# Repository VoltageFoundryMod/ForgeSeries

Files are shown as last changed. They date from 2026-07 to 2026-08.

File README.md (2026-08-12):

<div align="center">

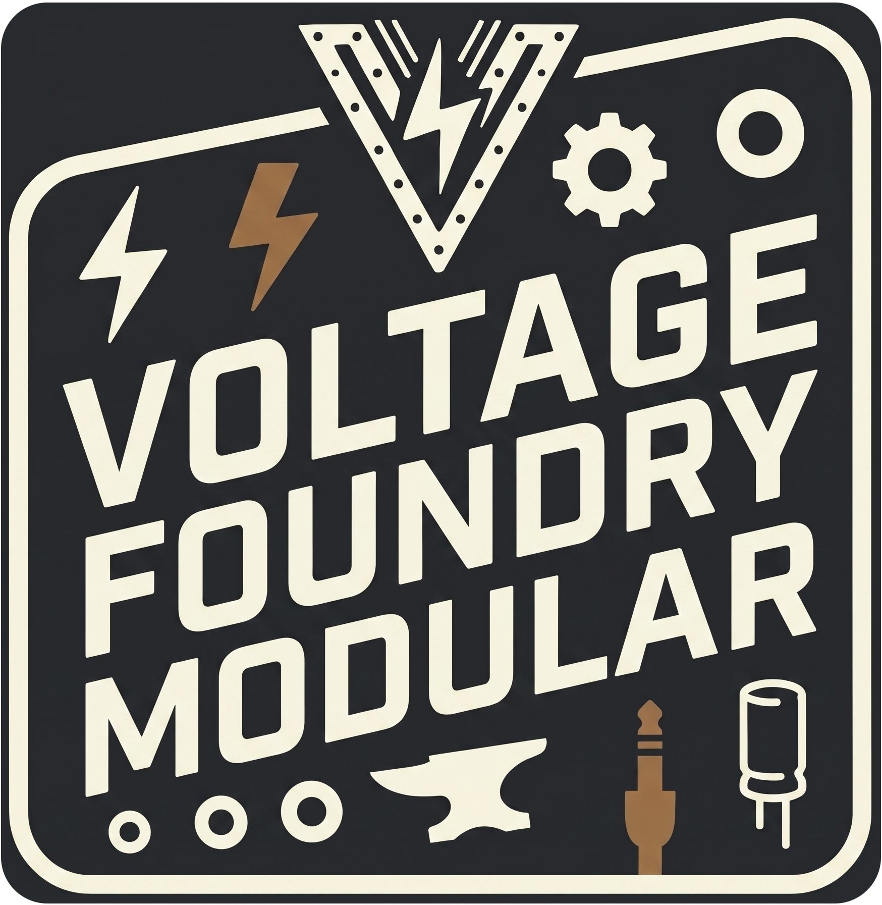
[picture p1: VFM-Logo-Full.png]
Voltage Foundry Modular


# ForgeSeries

**One open-source Eurorack platform. Many modules. You choose which one it is at
power-on — and the same firmware also runs inside VCV Rack.**

[The modules](#the-modules) ·
[Get one running](#get-one-running) ·
[The board](#the-board) ·
[Building from source](#building) ·
[How it fits together](#how-it-fits-together)

[Website & manuals](https://vfmod.com) ·
[Hardware repo](https://github.com/VoltageFoundryMod/ForgeSeries-Hardware) ·
[Firmware releases](https://github.com/VoltageFoundryMod/ForgeSeries/releases) ·
[Support on Patreon](https://patreon.com/carlosedp)

</div>

---

## What this is

ForgeSeries is a family of 6HP Eurorack modules from **Voltage Foundry Modular**
that all share a single board: a Seeed XIAO RP2040, a 128×64 OLED, one encoder,
3 CV inputs and 4 outputs. What makes the board a clock generator or a quantizer
is nothing but firmware.

This repository holds all of it:

- **The firmware** — one image (`src/`) that contains _every_ module. Hold
  the encoder at power-on to pick which one boots; the choice persists.
- **The VCV Rack plugin** — not a reimplementation. The actual firmware runs
  inside Rack against a hardware shim, with the OLED emulated pixel for pixel,
  so a patch behaves the same on the metal and on the screen.
- **The shared core** — board bring-up, CV calibration, storage, display and
  menu plumbing that every module builds on.

Schematics, PCB and panel files are open too, in the separate
[ForgeSeries-Hardware](https://github.com/VoltageFoundryMod/ForgeSeries-Hardware)
repository.

## The modules

| | Module | What it does | Docs |
| --- | --- | --- | --- |
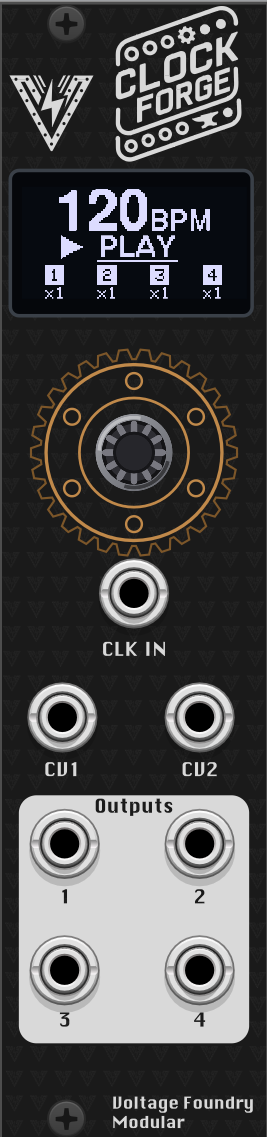
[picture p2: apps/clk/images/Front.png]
ClockForge front panel
|  | **ClockForge**<br><sub>`apps/clk`</sub> | Clock generator and modulation source. Four outputs with individual multiply/divide, waveforms, envelopes, Euclidean rhythms, swing, phase, probability, cross-operations and loops. Tap tempo and external sync. | [Overview](apps/clk/Readme.md) · [Manual](apps/clk/Manual.md) · [VCV port](apps/clk/docs/VCVRack_Plugin.md) · [ModularGrid](https://modulargrid.net/e/voltage-foundry-modular-clockforge) |
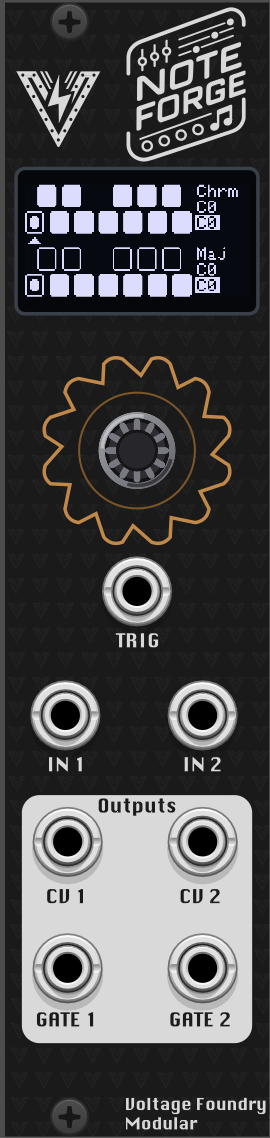
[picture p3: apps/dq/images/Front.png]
NoteForge front panel
|  | **NoteForge**<br><sub>`apps/dq`</sub> | Dual quantizer. Two independent channels, each with its own editable 12-note scale mask, octave shift, glide, sample & hold and a gate/envelope output. | [Overview](apps/dq/Readme.md) · [Manual](apps/dq/Manual.md) · [VCV port](apps/dq/docs/VCVRack_Plugin.md) · [ModularGrid](https://modulargrid.net/e/voltage-foundry-modular-noteforge) |
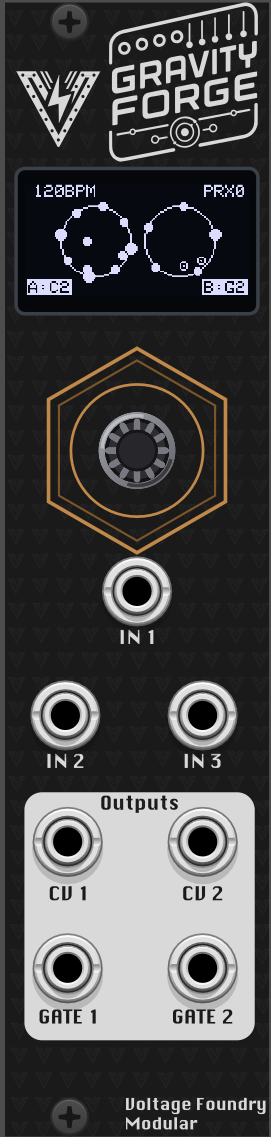
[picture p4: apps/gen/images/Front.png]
GravityForge front panel
|  | **GravityForge**<br><sub>`apps/gen`</sub> | Physics-based generative sequencer. Balls fall inside two rotating containers and ring scale-tuned pegs; a proximity control slides the two from independent sequencers into one entangled instrument. | [Overview](apps/gen/Readme.md) · [Manual](apps/gen/Manual.md) · [Design notes](apps/gen/docs/Design.md) · [ModularGrid](https://modulargrid.net/e/voltage-foundry-modular-gravityforge) |
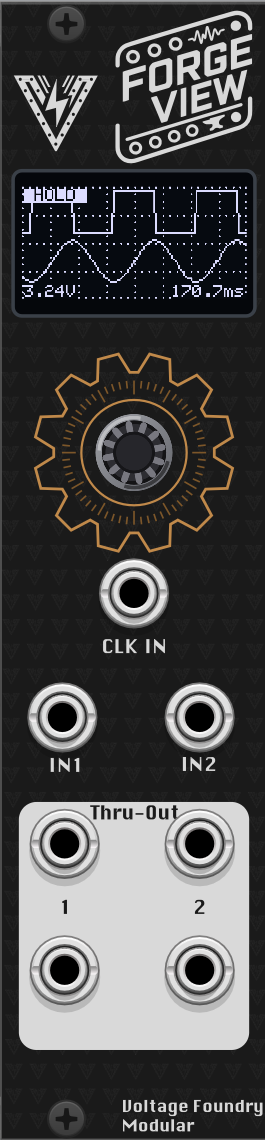
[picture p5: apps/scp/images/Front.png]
ForgeView front panel
|  | **ForgeView**<br><sub>`apps/scp`</sub> | Oscilloscope and analysis. Dual-trace and single-trace scope, triggered capture, spectrum analyzer, X-Y display and a tuner — with buffered pass-through so it can sit mid-patch. | [Overview](apps/scp/Readme.md) · [Manual](apps/scp/Manual.md) · [VCV port](apps/scp/docs/VCVRack_Plugin.md) · [ModularGrid](https://modulargrid.net/e/voltage-foundry-modular-forgeview)  |
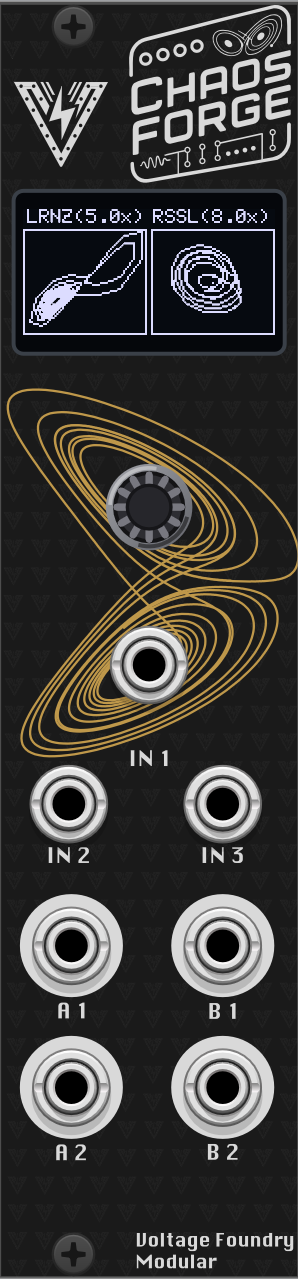
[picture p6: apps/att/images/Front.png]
ChaosForge front panel
|  | **ChaosForge**<br><sub>`apps/att`</sub> | Dual chaotic-attractor modulation source. Twelve strange attractors; each generator sends two of its three state variables to a pair of jacks, and a couple control takes the two from unrelated to locked. | [Overview](apps/att/Readme.md) · [Manual](apps/att/Manual.md) · [Design notes](apps/att/docs/Design.md) · [ModularGrid](https://modulargrid.net/e/voltage-foundry-modular-chaosforge) |
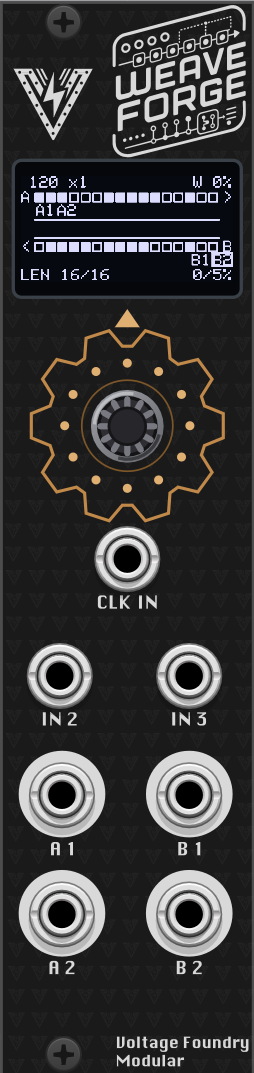
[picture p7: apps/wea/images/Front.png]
WeaveForge front panel
|  | **WeaveForge**<br><sub>`apps/wea`</sub> | Dual shift-register sequencer. Two Turing Machines side by side, and one WEAVE control that slides them from independent to chained into a single ring; four jacks assignable to notes, modulation, gates or triggers. | [Overview](apps/wea/Readme.md) · [Manual](apps/wea/Manual.md) · [Design notes](apps/wea/docs/Design.md) |

Each **Manual** is the complete user guide — every menu page, screenshot,
calibration and wiring detail. Browsable versions with images live on
[vfmod.com](https://vfmod.com).

## Get one running

### On hardware

1. Download `ForgeSeries-<version>-unified.zip` from the [latest release](https://github.com/VoltageFoundryMod/ForgeSeries/releases) or a [dev build](https://github.com/VoltageFoundryMod/ForgeSeries/actions) from CI run's artifacts (enter one of the workflow runs and the artifacts are at the bottom) and unpack the `.uf2` inside it.
2. Hold the small **BOOT (B)** button on the XIAO while connecting USB-C. A
   drive named `RPI-RP2` appears. (The XIAO is socketed, so this can be done
   with it removed from the module.)
3. Copy the `.uf2` onto that drive. The module reboots into the new firmware.
4. **Hold the encoder at power-on** to choose a module. It boots straight into
   that one afterwards; to get back to the selector, either hold the encoder for
   two seconds while running or pick **BOOT MENU** on the module's SETTINGS page.
5. Run the two-point **calibration wizard** once: pick **CALIBRATE**,
   the last row of the boot menu. Calibration works for the board, so one
   run serves every module and it survives firmware updates.

#### Single-module images

`ForgeSeries-<version>-individual-modules.zip` on the same release holds one image per
module — `ClockForge`, `NoteForge`, `GravityForge`, `ForgeView`, `ChaosForge`,
`WeaveForge` —
for a build of
the hardware that is only ever going to be one of them. Flashing works exactly
as above, and everything else in this section still applies: the module boots
straight in, and holding the encoder at power-on (or **BOOT MENU** on its
SETTINGS page) opens the same screen with that one module and **CALIBRATE** on
it, which is how you reach the wizard.

They are the same shell and the same module sources as the unified image, just
linked with one module instead of all of them, so a given release behaves identically
either way. Presets and calibration live in the same files, so you can move
between the two images without losing either.

> **Never connect Eurorack power and USB-C at the same time.** The module takes
> either, not both.

### In VCV Rack

The plugin bundles every module under the **Voltage Foundry Modular** brand.
Until it lands in the VCV library, build it from source — see
[Building](#building) — or take the packaged `.vcvplugin` from the [latest release](https://github.com/VoltageFoundryMod/ForgeSeries/releases) or a [dev build](https://github.com/VoltageFoundryMod/ForgeSeries/actions) from CI run's artifacts (enter one of the workflow runs and the artifacts are at the bottom).

```sh
make vcv && make vcv-install   # build the bundle and install it into Rack
```

And drop the `.vcvrack` file into plugins in the VCVRack user folder. MacOS is `~/Library/Application Support/Rack2/`, Windows is `C:\Users\<username>\AppData\Local\Rack2\`, and Linux is `~/.local/share/Rack2/`.

The Rack build can accept 0–5 V (like the hardware), ±5 V or 0–10 V inputs, so
it is more forgiving than the board while behaving identically inside that
range.

## The board

Every ForgeSeries module is the same hardware:

| | |
| --- | --- |
| MCU | Seeed XIAO RP2040 (dual core, 2 MB flash) |
| Display  | 128×64 SSD1306 OLED |
| Controls | one rotary encoder with push |
| I/O | 3 CV inputs, 4 outputs (12-bit MCP4728 DAC) |
| CV range | 0–5 V in and out (a ±5 V revision builds with `-DFORGE_CV_BIPOLAR`) |
| Size | 6 HP, 40 mm deep |
| Power | 12 V or 5 V, jumper selectable · ~60 mA |

Because the hardware is identical across modules, one board plus one firmware
flash gets you any of them — and a new module is a new firmware, not a new PCB.

## Repository layout

```text
platformio.ini  the firmware project — the repo root IS the PlatformIO project
src/            the shell. The only firmware built for the board
core/      the board, and everything every module shares
apps/
  clk/     ClockForge    — clock generator / modulation source
  dq/      NoteForge     — dual quantizer
  gen/     GravityForge  — physics-based generative sequencer
  scp/     ForgeView     — oscilloscope / spectrum analyser
  att/     ChaosForge    — dual chaotic-attractor modulation source
  wea/     WeaveForge    — dual shift-register sequencer
vcv/       the consolidated VCV Rack plugin (all modules, one binary)
vcvlib/    shared VCV Rack layer (Arduino shim, ForgeModule, IEngine, widgets)
tools/     env.ps1 — optional PATH helper for Windows
```

A module runs on two hosts — the shell (hardware firmware) and VCV Rack — and
its code lives in one place per host:

```text
apps/gen/
  src/gen_app.cpp   the module as the shell sees it (forge::IApp)
  src/gen_app.hpp   its factory — the only thing the shell includes
  lib/              the module's own headers, including engine.hpp
  vcv-plugin/       the same module as a standalone Rack plugin
  test/             native unit tests (googletest + ArduinoFake)
  platformio.ini    those tests only — there is no per-module firmware
```

`lib/engine.hpp` is the piece that keeps the two honest: the module's
per-iteration engine step lives there and both hosts include it, rather than
each carrying a copy. That duplication is how GravityForge's Rack port silently
lost its LOOP▸NAP muting.

## Building

Prerequisites: [PlatformIO](https://platformio.org/) for the firmware, and the
[VCV Rack SDK](https://vcvrack.com/manual/Building) for the plugins (expected at
`../Rack-SDK`, override with `RACK_DIR=`).

```sh
make                # the firmware (unified image, every module)
make upload         # build + flash
make upload-monitor # ...and open the serial monitor
make modules        # the single-module images, one per module
make fw-clk         # one of them  (== pio run -e xiao_clk)
make fw-upload-clk  # ...and flash it
make test           # native unit tests for every module
make vcv            # the consolidated Rack plugin
make vcv-install    # ...and install it into Rack's user directory
make vcv-dist       # package it as a .vcvplugin
make plugins        # every standalone per-module Rack plugin
make clk            # one module's standalone plugin, installed into Rack
make everything     # every firmware image + all standalone plugins
```

**Run `make everything` before committing.** It is the only thing that builds
both hosts. PlatformIO does not compile `vcv-plugin/`, so a green firmware build
says nothing about the Rack ports — and every bug found while this structure was
being built was caught by building all targets and missed by building one.

> **Do not leave both plugin flavours installed in Rack.** The standalone
> plugins have their own slugs (`ClockForge`, `NoteForge`, …) and the
> consolidated one is `VoltageFoundryMod`, so Rack happily loads all of them and
> every module shows up twice in the browser. Delete the standalone ones from
> Rack's plugin directory before installing the consolidated build
> (`make -C vcv print-plugins-dir` prints where that is).

Standalone plugins can also be built directly. Both paths are `?=` defaults:

```sh
cd apps/gen/vcv-plugin && make          # RACK_DIR ?= ../../../../Rack-SDK
make RACK_DIR=/path/to/Rack-SDK         # out-of-tree SDK
```

`FORGEVCV` defaults to `../../../vcvlib` (in-repo). It no longer needs a sibling
`ForgeSeries-VCVLib` checkout.

[CI](.github/workflows/CI.yaml) drives these same entry points, so what it
checks and what you run locally cannot drift apart: unit tests and the unified
image, the VCV engine isolation tests, and both plugin flavours.

### Windows toolchain

Everything builds from PowerShell — an msys2 _shell_ is not required. Rack's
`plugin.mk` shells out to POSIX tools, but GNU make picks up msys2's `sh.exe` as
SHELL once it is on PATH, so PowerShell only has to be the parent shell.

```powershell
. .\tools\env.ps1   # puts the three toolchain dirs on PATH, reports what it found
make everything
```

The plugin compiler must be **mingw64 g++** — the Rack SDK for Windows is
mingw-w64 built and MSVC will not link against it. `jq` is needed too, since
`plugin.mk` uses it to read `SLUG` out of `plugin.json`:

```
pacman -S --needed make mingw-w64-x86_64-gcc mingw-w64-x86_64-jq
```

The Makefile checks for all three before building plugins and says exactly what
is missing, rather than letting it surface as plugin.mk's "SLUG could not be
found in manifest". The check runs only for the plugin goals — the firmware
needs PlatformIO alone and builds without msys2 installed.

Point `MSYS` elsewhere if needed: `make MSYS=D:/msys64 plugins`.

---

# How it fits together

The rest of this document is for people working on the code. Start here if you
are adding a module, touching `core/`, or wondering why the include order in a
module TU looks the way it does.

## What belongs in `core/`

Every ForgeSeries module is the _same board_: XIAO RP2040, SSD1306 on Wire,
MCP4728 on Wire1, one encoder, 3 in / 4 out. Anything that follows from that is
shared:

| | |
| --- | --- |
| `boardPinouts.hpp` | wiring, converter resolution (`MAXDAC`/`MAXADC`) |
| `boardIO.hpp` | I2C bring-up, DAC writes + output calibration |
| `cvInput.hpp` | CV acquisition, calibration, range adapters |
| `calibrationData.hpp` `calibration.hpp` | the blob, and the wizard that fills it |
| `fsStore.hpp` `appStorage.hpp` | LittleFS storage; presets and calibration |
| `shellObjects.hpp` | the board-owned `display` / `displayMgr` / `encoder` / `cal` |
| `displayManager.hpp` `menuDisplay.hpp` `appDisplay.hpp` `splash.hpp`  | UI plumbing |
| `encoder.hpp` `encoderAccel.hpp` `encoderMenu.hpp` | encoder, acceleration, menu driver |
| `envelope.hpp` `scales.hpp` `quantizer.hpp` `utils.hpp` `metrics.hpp` | shared DSP/theory |
| `clockSource.hpp` | internal BPM, external clock at IN 1, the changeover |
| `IApp.hpp` | the shell↔app contract |

What stays in a module's `lib/` is genuinely its own: menu definitions, preset
schema, `engine.hpp`, and the DSP that makes it that module.

ClockForge's quantizer is deliberately not shared: it is a separate
implementation reached through `Output` rather than a channel, so folding it in
would be a port rather than a merge.

**Neither is ClockForge's clock**, for the same reason and with more at stake.
`core/clockSource.hpp` is a passed-in-time value object — nothing in it calls
`micros()`, which is what makes it host-testable and the Rack ports
deterministic. `apps/clk/lib/clockEngine.hpp` is a 960-PPQN hardware-timer ISR
with file-scope `BPM` and `tickCounter` globals driving that whole module from
the interrupt. They share a word, not an architecture. `clockSource.hpp` was
lifted out of GravityForge when WeaveForge needed the same internal/external
changeover, and GravityForge holds one as a member rather than having been
rewritten around it — its `Clock` still owns the quantize grid, SPACE and the
spin rates, and its 21 clock tests were the guard that the lift changed nothing.

Two rules govern anything living here, and both have bitten:

**Anything `core/` defines must be `inline`** (C++17 inline variables included).
The unified image links the shell plus one TU per module; without it you get a
duplicate symbol, or worse a file-scope `static` gives each TU a private copy of
what should be shared hardware state.

**`core/` must never include an app header.** `boardIO.hpp` once included the
module-level `pinouts.hpp` and made `core/` unbuildable without a module on the
include path. Where a shared header genuinely needs data the caller owns, it
requires the caller to have defined it rather than reaching for it — the way
`calibration.hpp` takes `SaveCalibration()` from the shell.

## CV, and the ±5 V hardware

Readings are **normalised floats**: `1.0` is +5 V at the jack on every hardware
revision. Not counts — a count means nothing without also knowing `MAXADC` and
the polarity convention, and presets store values derived from these.

```
unipolar (0..+5 V)   CvRead() ->  0.0 .. 1.0
bipolar  (-5..+5 V)  CvRead() -> -1.0 .. 1.0,  0 V == 0.0
```

Build for the ±5 V revision with `-DFORGE_CV_BIPOLAR`. Apps must read through
the adapters rather than open-coding a mapping, because which one is the
identity swaps when the flag flips:

| | unipolar | bipolar |
| --- | --- | --- |
| `CvUni` → 0..1 | identity | `(v+1)/2` |
| `CvBi` → -1..1 | `v*2-1`  | identity  |

Pitch is **not** normalised — `CvSemitones()` returns 1 V/oct semitones, and DAC
output stays in counts, scaled at the write. Three domains, three units.

0 V is C0 on both revisions, so the bipolar jack keeps the same five-octave
span. Moving C0 to -3 V for eight octaves is a future opt-in menu setting, not
something implied by the hardware.

## The unified firmware

`src/` is the shell and nothing else. It owns the board — one `display`,
one `encoder`, one `cal` — brings the hardware up, mounts the filesystem, runs
the module selector, then drives exactly one module through `forge::IApp`
(`Begin`/`Tick0`/`Tick1` + encoder events). The core split is the one every
firmware already used: Core 0 does ADC/DAC/encoder, Core 1 renders.

**Using it.** Hold the encoder at power-on to choose a module; the choice
persists, so it boots straight into it afterwards. Two ways back to the
selector: hold the encoder for two seconds while running, or pick **BOOT MENU**
on the module's SETTINGS page. Either way the switch reboots rather than
unwinding in place — a running module owns interrupts, a hardware timer and
Core 1 work — so `End()` is called first and a flag survives the reset.

The selector's last row is **CALIBRATE**, and it is the only way into the
wizard. Calibration measures the board's analog front and back ends, not
anything module-specific, so it belongs to the shell — and it has to run with
Core 1 parked and no module started, which is only true on this screen. It
writes `/cal.bin` and reboots back to the selector.

The held-encoder check happens before any module code runs, so a module that
hangs in its own `Begin()` can still be escaped by holding the encoder and
power-cycling.

**Single-module images.** `env:xiao_clk` and its three siblings build the same
shell with one module linked in — for hardware that is only ever going to be
that module. `make modules`, or `make fw-clk` for one.

The shell is not modified for this and neither is any module. The environment
passes `-DFORGE_ONLY_APP=<Factory>`, and the single `#ifdef` in `kApps[]` builds
an array of one from it. Everything above still holds with `kAppCount == 1`: the
module boots straight in, the selector lists it and **CALIBRATE**, and
`FORGE_UNIFIED` stays defined so **BOOT MENU** is still on the module's SETTINGS
page. Stripping the selector out instead is what would have cost something — it
is the only entry point to the wizard, so removing it means either an `#ifdef`
axis through every module's `menuHandlers.hpp` or no field calibration.

Naming the factory rather than setting a per-module flag is what keeps that to
one `#ifdef`: it covers every module, present and future, so adding one is still
just an include and an array entry. The `<app>_app.hpp` includes stay
unconditional even in a single-module image, because they only _declare_ a
factory — an unused declaration is not a link reference, so nothing is paid for
the three that are not there.

The array is written out rather than having each module TU register itself at
static-init time, because `/boot` stores an _index_ into it and static-init order
across translation units is unspecified — self-registration would let link order
decide what index 2 means.

**Storage** is LittleFS, not the emulated EEPROM. That sector is a single 4096
bytes and its `begin()` clamps silently — which is how ClockForge shipped with
permanently broken calibration and three dead preset slots. Several modules could
never have shared it.

```
/cal.bin      CalibrationData, shared by every module
/boot         which module to start, and a return-to-menu flag
/<app><n>.pre one preset slot
```

One file per slot, so a write is a whole-file atomic replace and the slot count
is no longer capped by a sector. Every write goes via a temp file and a rename;
every read checks a magic and an exact length, and anything that fails reads as
absent so the caller falls back to defaults.

**Namespaces.** Each module TU wraps itself in `namespace forge::<app>`, which
is what lets several firmwares share one binary — they all define `menuMode`,
`switchState`, `param` and friends at file scope.

> **Include order in a module TU is load-bearing.** Standard library,
> third-party and `core/` headers go at _global_ scope first, so their guards
> are already satisfied; only then the module's own headers, inside the
> namespace. Miss one — `<cstring>`, say — and libstdc++ lands inside
> `forge::<app>`, producing hundreds of errors in `stringfwd.h` that never name
> the file responsible. The blocks are bracketed with `clang-format off/on`
> because an editor that sorts includes will break this silently. See the header
> comment in `apps/scp/src/scp_app.cpp`.

A few `core/` headers are included _late_, after the module's state exists,
because they close over it: `engine.hpp` (the module's globals),
`appDisplay.hpp` (`HandleOutputs`, the display flags) and `encoderMenu.hpp`
(the five hooks). That is the price of sharing code that calls back into
per-module state.

## Image size, and how it scales

The root `platformio.ini` pulls each module TU in through `build_src_filter`, so
sources stay with their module rather than being copied. Only each module's
`src/` is on the include path: it holds nothing but the uniquely-named
`<app>_app.hpp`, so unlike putting the `lib/` dirs there it cannot shadow a
sibling's header. (It once did — GravityForge resolved `quantizer.hpp` to
NoteForge's copy purely because `dq` came first in the include path.)

Current size, every module in one image:

| | RAM | Flash |
| --- | --- | --- |
| unified | 31108 (11.9 %) | 280508 (15.3 %) |

Flash is measured against 1830912 bytes — 256 KB of the 2 MB part is reserved
for the LittleFS region, and that size must stay fixed across releases or the
region moves and stored files are lost.

Only one module _runs_ at a time, but all of them are _linked_, so static RAM is
the sum of every module's state rather than the maximum. That sounds worse than
it is: most of a module's apparent footprint is the Arduino/TinyUSB baseline,
which is paid once. What a module actually adds is its own translation unit's
`data+bss`:

| module | RAM added | flash added |
| --- | --- | --- |
| clk | ~7 KB | ~46 KB |
| gen | ~1.9 KB | ~28 KB |
| scp | ~1.2 KB | ~14 KB |
| dq | ~0.7 KB | ~19 KB |
| wea | ~0.5 KB | ~17 KB |
| shell  | ~0.2 KB | ~2 KB |

Baseline is ~17.8 KB. Six modules is ~12 % of RAM, so ten ClockForge-weight
ones would be ~34 % and ten typical ones ~15 %. Flash is looser still.

WeaveForge is the cheapest so far and shows where the cost actually is: its
engine is two `uint16_t` and a few dozen bytes of parameters, and essentially all
of its ~17 KB of flash is menu, render and preset code — the plumbing every
module pays, not the DSP that makes it that module.

ClockForge is the outlier at 10× NoteForge — if RAM ever gets tight, that one
module is the lever, not the module count.

If it did get tight, the escape hatch is half-built: each module's
`vcv-plugin/src/engine/engine_state.def` already enumerates every mutable global
it owns, because the Rack port needs per-instance state. The same X-macro could
size a shared arena and make RAM `max(module)` rather than `sum(modules)`. Not
needed at five, probably not at ten — but the enumeration exists, and it is
worth keeping accurate as modules are added, since only the Rack build catches a
stale entry.

## History

This repo was assembled from five separate repositories with `git subtree`, so
all 311 original commits are preserved and reachable.

Because the files moved into `apps/<app>/`, git's default history simplification
hides pre-import commits. To see them, ask for the **old** path with
`--full-history`:

```sh
git log --full-history -- lib/storage.hpp        # CLK's pre-import history
git log --full-history -- include/forgevcv/      # VCVLib's
```

Post-import history uses the new paths as normal.

The original repositories remain untouched on disk and on GitHub. They are the
authoritative record for anything predating the import.

---

## Contributing & support

Issues and pull requests are welcome on the
[GitHub repository](https://github.com/VoltageFoundryMod/ForgeSeries). If a
module misbehaves, its **Manual** has a troubleshooting section worth checking
first.

See [CONTRIBUTING.md](CONTRIBUTING.md) before opening a PR. Commits need a
`Signed-off-by` line (`git commit -s`) certifying the
[DCO](DCO); contributions are under GPL-3.0-or-later, like the rest of the code.
Panel and brand assets are not open to contribution — see
[LICENSE-ASSETS.md](LICENSE-ASSETS.md).

If these modules are useful to you, development is supported on
[Patreon](https://patreon.com/carlosedp) and
[GitHub Sponsors](https://github.com/sponsors/carlosedp).

## License

Two licences, covering two different things.

**The code — [GPL-3.0-or-later](LICENSE).** All of it: firmware, the VCV Rack
port, the shared core, the tooling. Fork it, study it, build on it, ship your
own version — provided your version is free software too. That is the whole
point: the ideas here should be reusable, and a proprietary product should not
be able to quietly absorb them.

**The brand — [LICENSE-ASSETS.md](LICENSE-ASSETS.md).** Panel designs, graphics,
the logo, and the names "Voltage Foundry Modular", "ForgeSeries" and the module
names are copyright and not covered by the GPL. You may build and run the
software with the artwork in place, and distribute modified versions that are
clearly marked as unofficial; you may not manufacture hardware wearing these
panels or ship something that looks like it came from us. Fork the code, put
your own face on it.

Hardware design files carry their own license in the
[hardware repository](https://github.com/VoltageFoundryMod/ForgeSeries-Hardware).

<div align="center">
<sub>Voltage Foundry Modular — open-source Eurorack, forged in code and copper.</sub>
</div>

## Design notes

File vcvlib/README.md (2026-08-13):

# ForgeSeries VCV Library

Reusable VCV Rack layer shared by [ForgeSeries](https://github.com/VoltageFoundryMod)
firmware ports. It lets a firmware written for the ForgeSeries hardware (XIAO
RP2040 + SSD1306 OLED + MCP4728 quad DAC + rotary encoder) compile and run
unchanged inside VCV Rack, wrapped in a consistent module UI.

The firmware's own DSP / menu / render code stays in each firmware repo; this
library provides only the host-side glue that would otherwise be copy-pasted
between plugins.

## What's in here

| Path | Purpose |
| ---- | --- |
| `shim/` | Arduino / Wire / EEPROM / Adafruit shims so firmware `lib/` compiles under Rack. Includes the `HostBridge` that routes firmware I/O (GPIO, ADC, DAC, framebuffer) to the hosting module. |
| `shim/Fonts/` | `GFXfont` headers usable via `display.setFont(&helvB24)` (see below). |
| `include/forgevcv/IEngine.hpp` | Abstract engine contract. Each firmware wraps its bridge in an `IEngine`. |
| `include/forgevcv/ForgeModule.hpp` | `rack::Module` base: owns the engine, holds the framebuffer, the CV-range and encoder-sensitivity host settings, the UI→audio encoder queue, the control-rate engine step, shared patch JSON, and the Initialize/Randomize actions. |
| `include/forgevcv/widgets.hpp` | Shared UI: `FramebufferDisplay` (emulated OLED), `EncoderKnob` (drag/click), `BpmSlider`. |
| `forgevcv.mk` | Makefile fragment: adds the include path, C++17, and exports `FORGEVCV_SHIM`. |
| `test/screenshot.cpp` | Prints a module's emulated 128×64 OLED to the terminal as ASCII, on the host compiler — no Rack, no hardware. Generic over `IEngine`; run it with `make screen-<app>`. |

Everything under `include/` is header-only (in-class definitions are inline, so
including from multiple module TUs is ODR-safe).

## Using it in a plugin

Add this repo as a submodule and include the fragment from your plugin Makefile:

```makefile
FORGEVCV ?= ../ForgeSeries-VCVLib      # git submodule path
include $(FORGEVCV)/forgevcv.mk

SOURCES += $(wildcard src/*.cpp) $(wildcard src/engine/*.cpp)

# Only the firmware engine TU sees the Arduino shim + firmware lib/, so the shim
# names never collide with rack.hpp in the UI sources.
build/src/engine/fw_engine.cpp.o: EXTRA_CXXFLAGS += -I$(FORGEVCV_SHIM) -I../lib
```

In your plugin:

1. **Engine** — implement `forgevcv::IEngine` in your engine TU, wrapping your
   firmware bridge. Keep any richer, module-specific parameter accessors (tempo,
   waveform, ...) in your own header for the context menu.

   `serialize()` must **commit the live state into the EEPROM blob first**
   (`Save(CollectParams(), 0)`) — firmwares only write EEPROM on an explicit
   SAVE, so dumping the raw buffer persists a blob with none of the user's edits
   in it and the patch reloads at factory defaults. `deserialize()` reads slot 0
   back. Optionally override `reset()` / `randomize()` to back Rack's Initialize
   and Randomize; they default to no-ops.
2. **Module** — subclass `forgevcv::ForgeModule`, declare your `InputId` /
   `OutputId` / ... enums, construct your `IEngine` into `engine`, and implement
   `process()` as: gather CV via `mapCvInput` + clock level → `stepEngine(...)` →
   write `outHold` to your outputs. Call `baseToJson` / `baseFromJson` from
   `dataToJson` / `dataFromJson`.
3. **Widget** — place `forgevcv::FramebufferDisplay` and `EncoderKnob`, pointing
   their `module` at your module instance. Add your own ports, panel, keyboard
   shortcuts, and context menu.

## Display rendering

`FramebufferDisplay` rasterizes the 128x64 framebuffer on the CPU, straight to
whatever resolution the screen currently occupies, then blits it 1:1 onto
device-pixel-snapped coordinates so the GPU never resamples it.

This matters because a ForgeSeries screen cutout is ~35 mm ≈ 103 px at 100 %
zoom, i.e. the panel *downscales* the framebuffer. Sampling that with
`NVG_IMAGE_NEAREST` drops 25 of the 128 columns and 13 of the 64 rows outright,
so 1 px font stems vanish; linear sampling smears them instead. Integrating the
exact area each output texel covers keeps a stem that falls between two texels
alive as two dimmer ones, which is why hardware looks sharper than a naive blit.

Above 3 device pixels per OLED pixel it switches to an integer supersample, so
every pixel stays exactly the same size when you zoom in.

Three corrections keep the downscaled result as bright and tight as hardware,
measured on a glyph-like test pattern at 103x51 (0.80 texels per OLED pixel):

| | total light | 1 px stem | solid fill | mid-tone texels |
| - | - | - | - | - |
| plain area resample | — | 209 | 210 | 144 |
| + gap fade | +41.6 % | 246 | **255** | 113 |
| + isolated-pixel gain | +56.0 % | **255** | **255** | 81 |
| + `sharpen` | +58.1 % | **255** | **255** | **4** |

- **Gap fade** — a dark inter-pixel grid only reads as a grid once there are
  enough texels to draw one. Below that it is invisible and just costs
  `(1-gap)²` of the light, so it fades in over 4..8 texels per pixel.
- **Gain** — when downscaling, an isolated lit pixel can only ever cover `s` of
  a texel, so without a `1/s` gain a 1 px stem could never reach the full
  brightness it has on hardware.
- **`sharpen`** — pulls partial coverage away from the middle, so an edge that
  lands well inside a texel goes fully on or off instead of grey. Mid-tone
  texels are what read as blur, and block-heavy UIs are the worst case for
  them: on a keyboard/grid screen this takes them from 647 to 50.

`sharpen` is safe to push hard because the gain pins an evenly-split 1 px stem
to coverage exactly 0.5 — the curve's pivot — so it is invariant under any
amount of sharpening. Measured over every column and row at ten zoom levels, the
dimmest a stem ever gets is 189/255, and it is a full 255 at every zoom at or
above 1:1. That is the difference from the nearest-neighbour blit this replaced:
comparably hard edges, but nothing can ever vanish.

Tweakable per instance (set `dirty = true` if you change one after the first
frame):

| Field | Default | Effect |
| ----- | --- | --- |
| `litColor` / `bgColor` | OLED blue / near-black | pixel and glass colours |
| `pixelGap` | `0.16` | dark fraction of each cell — the inter-pixel grid a real OLED has, faded in as it becomes resolvable. `0` fills cells solid |
| `sharpen` | `4` | >1 snaps edges toward fully on/off; `1` is plain area coverage. Higher approaches nearest-neighbour hardness without its dropped pixels. Backed off automatically as `pixelGap` fades in, since the grid ring is a soft edge worth keeping |
| `gamma` | `2.2` | coverage → alpha encode. OLED light adds linearly but NanoVG blends in sRGB, so without this partial coverage comes out far too dark. `1` disables |
| `bloom` | `0` | 0..1 light spill into the 4 neighbours; a little sells the emissive look at the cost of some sharpness |
| `glassSheen` | `false` | diagonal reflection over the glass; lifts the black floor, so it costs screen contrast |

The lit pixels are drawn on Rack's light layer, so the screen keeps glowing when
the room is dimmed; the glass and sheen stay on the panel layer and darken with
it. The texture is rebuilt only when the framebuffer actually changes, so a
static screen costs one `nvgFill` per frame.

## Custom fonts

The GFX shim implements the full Adafruit custom-font API (`setFont`,
`getTextBounds`, per-glyph metrics), pixel-identical to the hardware library.
`shim/Fonts/` bundles ready-to-use `GFXfont` headers:

- `helvB08/10/12/14/18/24` — hand-hinted X11 Helvetica Bold bitmaps (the
  "Pam's" look; recommended pairing: `helvB24` big + `helvB12` labels)
- `profont12/22` — monospaced terminal font, digits stay column-aligned
- `pixellari16`, `haxrcorp4089_16`, `helvetipixel16` — 16 px pixel fonts
  (use at ×1/×2)
- `FreeSans*`, `Org_01` — stock Adafruit fonts, unmodified

```cpp
#include <Fonts/helvB24.h>
display.setFont(&helvB24);
display.setCursor(x, y + 25); // custom fonts: cursor y = baseline, not top
display.print("120BPM");
display.setFont(nullptr);     // back to classic 5x7
```

The shim include path already covers `Fonts/`, so the include works unchanged
in Rack. For the physical module, copy the same header into the firmware repo
(the real Adafruit_GFX resolves `Fonts/...` from its own library folder for the
stock fonts, and compiles bundled headers like `helvB24.h` the same way).

## Versioning

Consumers pin a tag (`v0.x.y`). Because the `shim/` surface must match what
firmware `lib/` calls, bump the tag deliberately when the shim changes so an
older module can stay on an older tag.

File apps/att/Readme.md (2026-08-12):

# ChaosForge

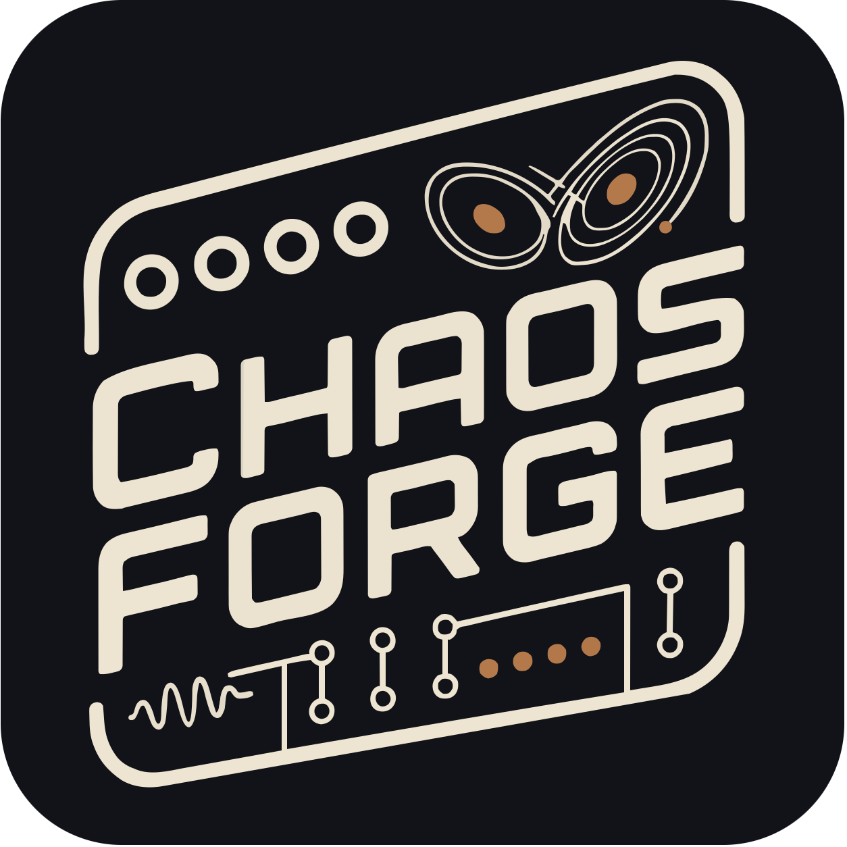
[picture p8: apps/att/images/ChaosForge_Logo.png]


**Dual chaotic-attractor modulation source.** Two strange attractors run side by
side; each sends two of its three state variables to a pair of output jacks. Four
voltages that are related without ever repeating, and a LINK control that lets the
two systems pull on each other.

Part of the [ForgeSeries](../../README.md) — same board, same shell, same
calibration as every other module in the family.

ChaosForge Module

Check the module on [ModularGrid](https://modulargrid.net/e/voltage-foundry-modular-chaosforge).

---

## What it is for

An LFO repeats exactly. A random source has no shape at all. A strange attractor
is the third thing: completely deterministic, smooth, with a figure you can learn
to recognise — and yet it never repeats, and two copies started a thousandth apart
are somewhere else entirely within seconds.

- Three inputs to control the attractor parameters
- Two outputs from each attractor, for a total of four jacks
- Two attractors, each with its own system, constants, speed, output axes, level, offset and smoothing
- A link between the two attractors, adjustable for variation and strength
- Nothing is ever quite the same twice, but it always sounds like the same instrument.

## At a glance

| | |
| --- | --- |
| **Systems** | Lorenz, Rössler, Thomas, Chua, Halvorsen, Chen, Burke-Shaw, Aizawa, Dadras, Sprott B, Sprott C, Finance |
| **Outputs** | 4 × 0–5 V CV — two per generator, each following a chosen axis |
| **Inputs** | IN 1 re-seed / freeze · IN 2 + IN 3 assignable modulation |
| **Per generator** | system, speed (0.01×–100×), up to four of that system's constants, output axes, level, offset, smoothing, range mode |
| **Link** | COUPLE, from unrelated through entrained to locked together |
| **Screen** | live Lissajous plot of each generator's output pair |
| **Presets** | 10 slots, slot 0 auto-loaded at boot, plus RANDOM |

## The controls that matter

**SYSTEM** picks the equations. Each one has its own figure and its own character:
Lorenz's double wing switches lobes at irregular intervals; Rössler drifts smoothly
then folds sharply on Z; Thomas is the gentlest, with no spikes at all; Chen is the
fastest and widest.

**SPEED** means the same kind of motion whichever system is selected — at 1.00×
a Lorenz wing takes about four seconds. From 0.01× (a drift that takes an hour to
go anywhere) up to 100×, which is well past the rate these systems are usually
shown animating at and into audible-adjacent territory.

**The constants** — SIGMA, RHO, ALPHA, and so on, named as the literature names
them — reshape the attractor itself. Some ranges include periodic windows where
the system stops being chaotic and becomes a pair of smooth repeating LFOs with an
unusual shape. That is a feature, not a bug; Thomas's B is the one to explore for
it.

**COUPLE** is the signature control. At 0 the two generators are unrelated. Turned
up they entrain — sharing their timing while keeping their own shapes — and near
the top, two copies of one system lock into a single orbit and the four jacks
become two.

**RANGE** decides how an orbit is fitted to the 0–5 V jack. FIXED uses a window
measured at the system's published constants: predictable, and identical from one
boot to the next. AUTO tracks the orbit's own window, which is what you want once
you have moved the constants far enough that the figure no longer fills the jack.

## Patch ideas

- **The default patch.** A1 and A2 (Lorenz X and Y) to filter cutoff and a
  wavefolder; B1 and B2 (a slow Rössler) to a reverb size and a pan. One
  fast pair, one slow pair, nothing repeating. Each generator owns a column of
  the panel — A down the left, B down the right.
- **One voice, two hands.** Both jacks of a generator into two parameters of the
  same voice. They will never agree and never fight.
- **Entrained pair.** Two generators on the same system, COUPLE around 30–50 %.
  Two voices that keep drifting into and out of agreement.
- **Sparse events.** Rössler with a jack on Z: smooth most of the time with an
  occasional sharp fold. Feed it to a comparator for gates that are rare but not
  random.
- **Frozen chord.** IN 1 set to FREEZE, hold a gate: every output stops dead and
  holds its exact voltage. Release and the orbits resume — they do not
  fast-forward through the pause.

---

## Usage

For more details and usage instructions, see [Manual.md](Manual.md).

## Contact

For support and inquiries, please open an issue on the [GitHub repository](https://github.com/VoltageFoundryMod/ForgeSeries).

## Acknowledgements

Thanks to NonLinear Circuits for the inspiration and many other open-source Eurorack makers that share their knowledge and work!

## License

Source code is GPL-3.0-or-later — see the [LICENSE](../../LICENSE) at the
repository root.

Panel designs, graphics, module names and the Voltage Foundry Modular brand are
copyright and are not covered by that licence; see
[LICENSE-ASSETS.md](../../LICENSE-ASSETS.md).

---

Thank you for choosing the ChaosForge module. We hope it enhances your musical creativity and performance.

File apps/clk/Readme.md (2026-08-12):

# ClockForge 2: Crafting Time, One Pulse at a Time

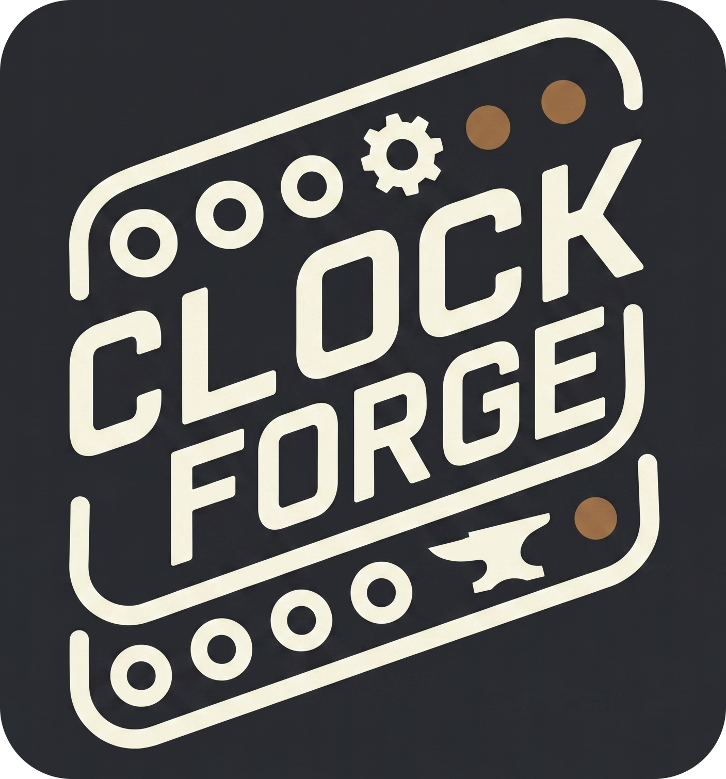
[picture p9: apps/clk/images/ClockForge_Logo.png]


## Overview

ClockForge provides clock signals and waveforms for synchronizing and modulating other modules in your Eurorack system. It features a global BPM control, multiple clock outputs, adjustable clock multiplication and division per output, tap tempo functionality, sync to external clock sources, Euclidean rhythm generation, CV Input modulation matrix and custom swing patterns per output.

Part of the **Forge** series of modules which share a single hardware platform. The new ClockForge 2 is an updated version with a more powerful microcontroller and 4 outputs that can generate clocks, waveforms and envelopes.

Most parts of this manual applies to both Hardware and VCV Rack plugin with exceptions to hardware specific features like calibration, powering and firmware update. The VCV Rack plugin is a full software emulation of the hardware module and can be used to test the module without having the physical hardware.

The hardware schematics and design files are completely open-source and available in the [GitHub repository](https://github.com/VoltageFoundryMod/ForgeSeries-Hardware).

ClockForge 2 Module

Check the module on [ModularGrid](https://modulargrid.net/e/voltage-foundry-modular-clockforge).

## Features

- **Global BPM Control**: Set the global BPM for all outputs.
- **Multiple Clock Outputs**: Four clock outputs with individual settings.
- **Adjustable Clock Multiplication and Division**: Configure each output to multiply or divide the global BPM.
- **Output Waveform Generation**: Outputs can generate different waveforms for modulation.
- **Pulse Probability**: Set the probability of a pulse occurring.
- **Euclidean Rhythm Generation**: Generate complex rhythms using Euclidean algorithm.
- **Custom Swing Patterns**: Apply swing to each output individually.
- **Sync to External Clock Sources**: Automatically adjust BPM based on an external clock signal with adjustable clock divider.
- **Phase Shift**: Adjust the phase of the output in relation to the master clock.
- **Waveform Duty Cycle and Level/Offset**: Adjust the pulse width and level/offset of the clock signal.
- **External modulation**: Many parameters can be modulated by the CV inputs by assigning CV targets.
- **Tap Tempo Functionality**: Manually set the BPM by tapping a button.
- **Quantization**: Quantize the output wave or CV input to some scale and root note.
- **Envelopes**: Outputs can generate different types of envelopes (AD, AR, ADSR) triggered by CV inputs.
- **Cross Operations**: Modulate an output with another output or CV input using arithmetic, logic and sample/hold operations.
- **Loops**: Rewind an output's pattern every few beats to build repeating, structured random/Euclidean phrases, with nap/wake muting.
- **Save/Load Configuration**: Save and load up to 10 configurations.

The module has a user-friendly interface with an encoder for navigation and parameter adjustment, and a clear display showing the current settings and status of each output. The main screen shows the BPM and the status of each output, while navigating into each output's settings allows for detailed configuration of that specific output. There are no submenus as all parameters are accessible by scrolling horizontally on the same menu screen.

The right side of the screen shows a navigation line to indicate the current position of the cursor in the menu. The navigation is not shown in the main (BPM) screen.

Whenever a parameter is changed, a small circle will be shown in the top-left corner of the screen. This indicates that the current settings were modified and not saved. The module always loads the preset saved in slot 0 on boot.

The current hardware design supports input signals from 0 to 5V, and the outputs are also 0-5V. The VCV Rack plugin module can be set to accept CV signals in the range of 0 to 5V like the hardware, -5 to +5V or 0 to 10V for more flexibility. The hardware might support other input/output ranges in the future but for now, voltages higher than 5V will be clipped and voltages lower than 0V will be ignored.

## Usage

For more details and usage instructions, see [Manual.md](Manual.md).

## Contact

For support and inquiries, please open an issue on the [GitHub repository](https://github.com/VoltageFoundryMod/ForgeSeries).

## Acknowledgements

Parts of the code are inspired by Hagiwo code, Quinienl's [LittleBen](https://github.com/Quinienl/LittleBen-Firmware) and Pamela's Workout.
Thanks for the inspiration!

## License

Source code is GPL-3.0-or-later — see the [LICENSE](../../LICENSE) at the
repository root.

Panel designs, graphics, module names and the Voltage Foundry Modular brand are
copyright and are not covered by that licence; see
[LICENSE-ASSETS.md](../../LICENSE-ASSETS.md).

---

Thank you for choosing the ClockForge module. We hope it enhances your musical creativity and performance.

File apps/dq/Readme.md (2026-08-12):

# NoteForge - A Dual Quantizer Eurorack Module

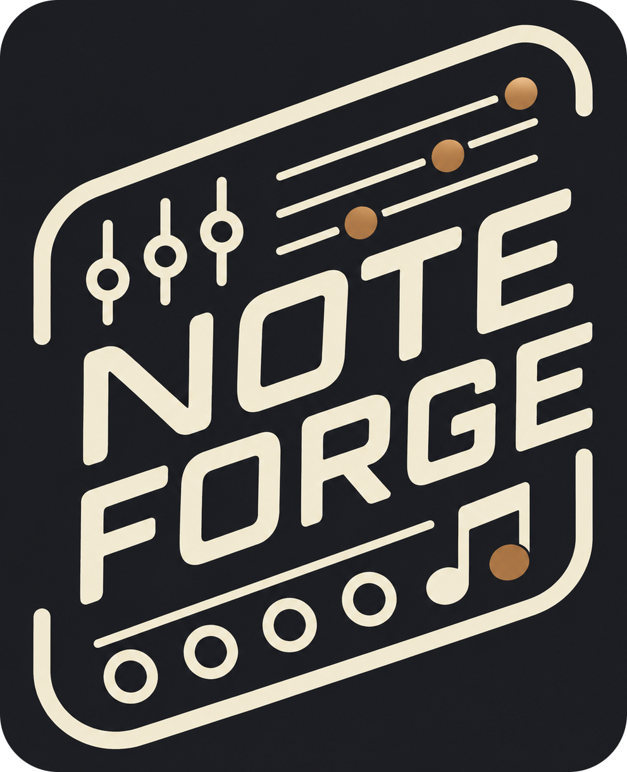
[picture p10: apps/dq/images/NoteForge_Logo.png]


## Introduction

NoteForge quantizes analog control voltages into musical notes. It has two fully
independent quantizers: each takes a pitch CV, snaps it to a scale you can edit
note by note, and emits a quantized CV plus a gate or envelope.

Part of the **Forge** series of modules, which share a single hardware platform
based on the Seeed XIAO RP2040. The hardware schematics and design files are
open-source and available in the
[hardware repository](https://github.com/VoltageFoundryMod/ForgeSeries-Hardware).

NoteForge also runs as a **VCV Rack plugin** — not a reimplementation, but the
actual firmware running inside Rack with the OLED emulated pixel for pixel. See
[docs/VCVRack_Plugin.md](docs/VCVRack_Plugin.md).

NoteForge Module

Check it out on [ModularGrid](https://modulargrid.net/e/voltage-foundry-modular-noteforge).

## Features

- Two independent quantizers, each with its own 12-note scale mask
- 15 built-in scales in any root, plus free per-note editing on the keyboard screen
- 12-bit quantized CV output on both channels (0–5 V, 1V/oct, 5 octaves)
- Boundary hysteresis so a CV resting on a note edge never chatters
- Per-channel gate/envelope output: AD envelope, fixed trigger, or gate
- Sync on trigger input, on note change, or both
- Per-channel octave shift, glide (portamento) and a note settle window
- Settle suppresses the notes an input sweeps through between two pitches
- Per-channel sample & hold: latch the note on a trigger and ignore the input between them
- IN 2 can become a transposition CV, stepping both channels in scale degrees
- 10 preset slots, with slot 0 loaded automatically at power-on
- Two-point CV input and output calibration wizard
- OLED display and rotary encoder for everything

## Usage

For more details and usage instructions, see [Manual.md](Manual.md).

## Contact

For support and inquiries, please open an issue on the
[GitHub repository](https://github.com/VoltageFoundryMod/ForgeSeries/issues).

## License

Source code is GPL-3.0-or-later — see the [LICENSE](../../LICENSE) at the
repository root.

Panel designs, graphics, module names and the Voltage Foundry Modular brand are
copyright and are not covered by that licence; see
[LICENSE-ASSETS.md](../../LICENSE-ASSETS.md).

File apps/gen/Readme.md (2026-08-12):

# GravityForge: Sequencing by Falling

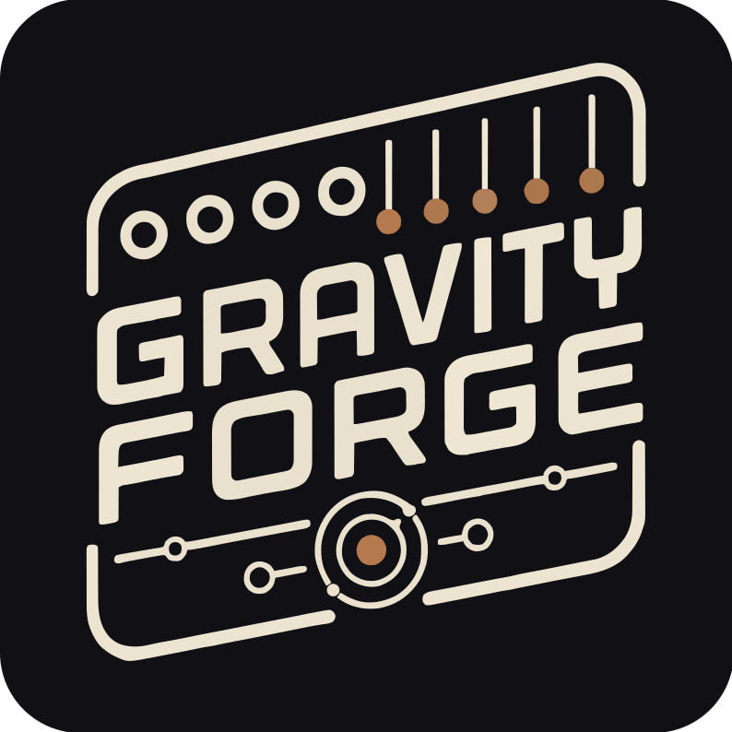
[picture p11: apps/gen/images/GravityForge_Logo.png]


## Overview

GravityForge is a **dual physics-based generative sequencer**. Two virtual containers hold bouncing balls. Gravity pulls them down, the containers rotate, and every time a ball strikes one of the **pegs** ringing a container wall, that peg plays a note.

Each peg _is_ a note. The ring is laid out in ascending pitch, and every peg is a degree of the container's selected scale — so where a ball happens to land decides what you hear, and nothing it can hit is out of key. Three controls shape that ring: **ROOT** is an absolute note (`C4`, not `C`) and the ring starts on it, **SPREAD** sets how many octaves it covers from there (1 to 5), and **BIAS** decides whether the notes are spaced evenly around it or crowd into the low or the high end. The **peg count** (3 to 16) then sets how finely that span is divided: a few pegs give wide intervals and an angular, arpeggio-like melody, while a full ring of sixteen gives small steps and something closer to a run. Individual pegs can be muted to open holes in the pattern — a muted peg still bounces the ball, it just stays silent.

Because the balls are never stepped by a clock, the notes land where the physics puts them: a rhythm that is repetitive enough to feel composed but never quite loops.

The signature control is **PROXIMITY**: the two containers are drawn side by side and a single parameter slides them together. Apart, they are two independent sequencers. Overlapping, a collision in one shoves the balls in the other and rings a peg on its rim. Fully merged, they share one space. It is one continuous knob from "two sequencers" to "one entangled instrument", and you can watch it happening on the screen.

Part of the **Forge** series of modules which share a single hardware platform. GravityForge runs the same board as ClockForge and NoteForge — only the firmware differs.

Most of this manual applies to both the hardware and the VCV Rack plugin, with the exception of hardware-specific topics like calibration, powering and firmware update. The VCV Rack plugin is a full software emulation of the hardware module and can be used without owning the physical module.

The hardware schematics and design files are completely open-source and available in the [GitHub repository](https://github.com/VoltageFoundryMod/ForgeSeries-Hardware).

GravityForge Module

Check the module on [ModularGrid](https://modulargrid.net/e/voltage-foundry-modular-gravityforge).

## Features

- **Two independent containers**: Each with its own gravity, bounce, rotation, ball count and peg ring, feeding its own CV and GATE output pair.
- **Proximity Coupling**: Slide the containers together to make collisions in one drive the other, from fully independent to fully merged.
- **Physics you can see**: The home screen draws the actual simulation — the balls, the peg ring, the hits and the coupling sparks are the state, not an illustration.
- **Scale-locked pitch**: Every peg is a scale degree, so no combination of settings can produce an out-of-key note. 15 scales and 12 root notes per container.
- **ROOT, SPREAD and BIAS**: ROOT is an absolute note and the ring starts on it, SPREAD sets how many octaves it covers from there, and BIAS decides where inside that span the notes crowd. Between them they place every peg — nothing is inferred.
- **Peg muting**: Individual pegs can be silenced to open up the rhythm and shape which coupled hits speak.
- **0V NOTE**: Tell the module which note your oscillator calls 0 V (C0–C5, default C4) and the notes it displays are the notes you hear.
- **Clock-locked rotation**: Container spin is set in beats per revolution (with reverse), so the motion stays musically related to the patch. Internal tempo or external clock.
- **Optional grid quantize**: The physics always free-runs, but the resulting note events can be deferred onto a 1/4 … 1/16T grid when a patch needs to lock up.
- **Loop / phrase mode**: Keep a passage you like. The simulation is deterministic, so it snapshots the balls and rewinds them every N beats, turning the endless stream into a repeating phrase — while gravity, proximity, the scale and every CV stay live over the top of it. Nap/wake mutes whole loops per container, and shifting one against the other gives call-and-response.
- **Gate shaping**: Per container AD envelope, fixed trigger or gate mode, with adjustable attack, decay and level.
- **Accent**: Scale the gate level by how hard the ball actually struck the peg, for real dynamics out of the physics.
- **CV modulation matrix**: Two assignable CV inputs covering gravity, spin, bounce, ball count, peg count, proximity and coupling — per container or both at once.
- **Assignable trigger input**: IN 1 acts as external clock, reset, kick or ball spawn.
- **Randomize**: Roll a whole new patch from the panel (or Ctrl+R in VCV Rack), leaving your clock and CV routing untouched.
- **Save/Load Configuration**: 10 preset slots, with slot 0 loaded automatically on boot.

The module has a single encoder for navigation and parameter adjustment and a 128×64 display. The main screen is the physics view; turning the encoder walks through parameter pages, and there are no submenus — every parameter is one scroll away on the same list.

The right side of the screen shows a navigation line indicating the cursor's position in the menu. It is not drawn on the main (physics) screen.

Whenever a parameter is changed, a small dot appears in the top-left corner of the screen. This indicates that the current settings were modified and not saved. The module always loads the preset saved in slot 0 on boot.

The pitch outputs cover five octaves at 1V/oct. Which notes those volts are depends on the oscillator you patch into, so **SETTINGS ▸ 0V NOTE** tells the module what its 0 V stands for (C0–C5, default C4 — VCV Rack's convention and the common one on hardware VCOs). The notes on screen are then the notes you hear; it renames the range without moving a single voltage.

The current hardware design supports input signals from 0 to 5V, and the outputs are also 0-5V. The VCV Rack plugin can be set to accept CV signals in the range of 0 to 5V like the hardware, -5 to +5V or 0 to 10V for more flexibility. Voltages higher than 5V will be clipped and voltages lower than 0V will be ignored on the hardware.

## Usage

For more details and usage instructions, see [Manual.md](Manual.md).

For the concept and the reasoning behind the design decisions, see [docs/Design.md](docs/Design.md).

## Contact

For support and inquiries, please open an issue on the [GitHub repository](https://github.com/VoltageFoundryMod/ForgeSeries/issues).

## Acknowledgements

The concept is inspired by Teenage Engineering's Tombola sequencer. Parts of the shared platform code are inspired by Hagiwo's code, Quinienl's [LittleBen](https://github.com/Quinienl/LittleBen-Firmware) and Pamela's Workout.
Thanks for the inspiration!

## License

Source code is GPL-3.0-or-later — see the [LICENSE](../../LICENSE) at the
repository root.

Panel designs, graphics, module names and the Voltage Foundry Modular brand are
copyright and are not covered by that licence; see
[LICENSE-ASSETS.md](../../LICENSE-ASSETS.md).

---

Thank you for choosing the GravityForge module. We hope it enhances your musical creativity and performance.

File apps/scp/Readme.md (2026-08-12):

# ForgeView: A scope for Eurorack

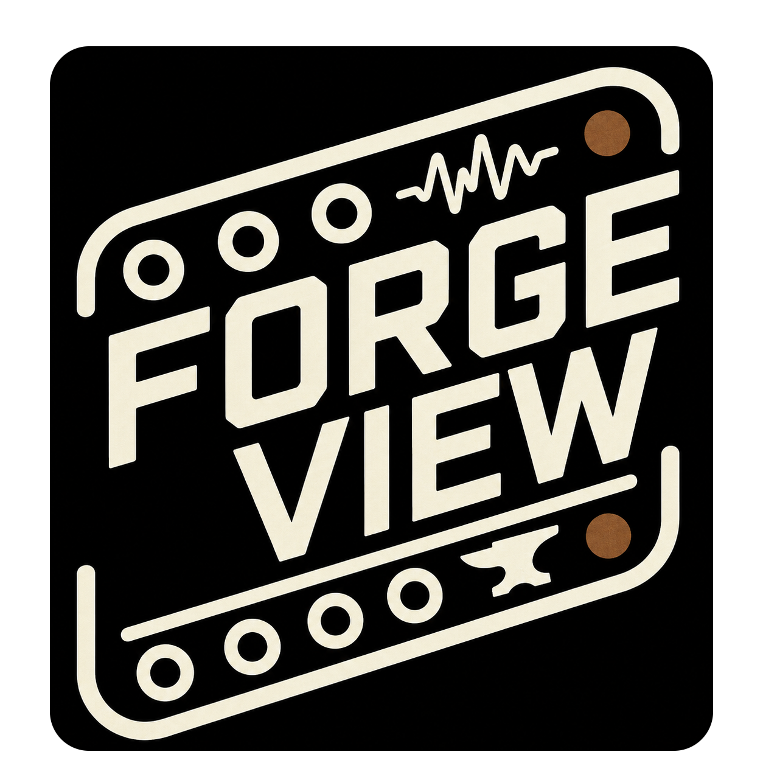
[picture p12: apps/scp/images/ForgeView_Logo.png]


## Overview

ForgeView is an essential oscilloscope for Eurorack systems. It can be used to visualize waveforms and signals in your modular system. The module has a 0.96" OLED display and can be used to visualize waveforms from LFOs, envelopes, oscillators, filters, and other signals in your system.

The module also exists as a VCV Rack plugin, which can be used to try the module virtually before building the hardware.

Part of the **Forge** series of modules which share a single hardware platform.

The hardware schematics and design files are completely open-source and available in the [GitHub repository](https://github.com/VoltageFoundryMod/ForgeSeries-Hardware).

ForgeView Module Front Panel

Check it out on [ModularGrid](https://modulargrid.net/e/voltage-foundry-modular-forgeview).

## Features

- **6 modes of operation** — dual-trace scope, single-trace scope, triggered single-shot capture, spectrum analyzer, X-Y (Lissajous) display, and a tuner / frequency meter.
- **Per-mode settings menu** — each mode has its own parameter list, edited with the encoder.
- **Engineering-unit readouts** — optional V/div and time/div axis labels, plus a peak-frequency readout in Spectrum mode.
- **Freeze-frame** — long-press the encoder in any mode to hold the current display.
- **Persistent settings** — the selected mode and all parameters are saved automatically and restored at power-up.
- **Signal pass-through** — both inputs are buffered and copied to the outputs so the scope can sit in the middle of a patch.

The current hardware design supports input signals from 0 to 5V, and the outputs are also 0-5V. The module is intended for visualization and not for high precision measurements. The VCV Rack plugin module can be set to accept CV signals in the range of 0 to 5V like the hardware, -5 to +5V or 0 to 10V for more flexibility. The hardware might support other input/output ranges in the future but for now, voltages higher than 5V will be clipped and voltages lower than 0V will be ignored.

## Usage

For more details and usage instructions, see [Manual.md](Manual.md).

## Contact

For support and inquiries, please open an issue on the [GitHub repository](https://github.com/VoltageFoundryMod/ForgeSeries).

## Acknowledgements

Great part of the code are inspired by Hagiwo's code.
Thanks for the inspiration!

## License

Source code is GPL-3.0-or-later — see the [LICENSE](../../LICENSE) at the
repository root.

Panel designs, graphics, module names and the Voltage Foundry Modular brand are
copyright and are not covered by that licence; see
[LICENSE-ASSETS.md](../../LICENSE-ASSETS.md).

---

Thank you for choosing the ForgeView module. We hope it enhances your musical creativity and performance.

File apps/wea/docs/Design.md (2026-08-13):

# WeaveForge — design notes

A dual shift-register sequencer for the Forge Series hardware.

Two 16-bit shift registers clock in parallel, each one a Turing Machine in the
Tom Whitwell sense: a ring of bits that either loops, drifts, or dissolves into
noise depending on one probability control. The novel part is **WEAVE** — a
single control that decides how much of each register's bit stream comes from
the _other_ one. At zero they are two independent sequencers; at full they chain
tail-to-head into a single ring as long as the two of them together.

That is the same proposition as GravityForge's PROXIMITY and ChaosForge's
COUPLE, but here the coupling is not a metaphor — it is the actual wiring of the
registers, and the screen draws it.

Inspired by Tom Whitwell's [Turing Machine], Hemisphere Suite's ShiftReg, and
the output-assignment idea from Phazerville's [Enigma] (see §9 for what was
deliberately not taken from it).

[Turing Machine]: https://www.musicthing.co.uk/Turing-Machine/
[Enigma]: https://firmware.phazerville.com/Enigma

---

## 1. Hardware contract

Shared Forge Series platform (XIAO RP2040, SSD1306 128×64, MCP4728 quad DAC,
rotary encoder + switch). See [ForgeSeries-Hardware].

[ForgeSeries-Hardware]: https://github.com/VoltageFoundryMod/ForgeSeries-Hardware

### Inputs

| Jack | Range | Role |
| ---- | --- | --- |
| IN 1 | gate/trigger | **CLOCK** — always, see below |
| IN 2 | **0–5 V** | Assignable modulation target  |
| IN 3 | **0–5 V** | Assignable modulation target  |

**IN 1 has no role menu, and that is a deliberate departure** from GravityForge
and ChaosForge. Those modules run a simulation that has its own life, so IN 1 is
free to mean RESET or KICK. A shift register has no state evolution between
clocks — unclocked, this module is a static voltage. Spending the only
interrupt-capable jack on anything but the clock would make the module
inoperable in its default patch, so the role list is one entry long and is not
shown.

An internal clock covers the unpatched case (see §7); RESET and the ShiftReg
"unlock" gate are reachable as CV targets on IN 2/IN 3.

> **CV range.** Current hardware is 0–5 V; a later revision moves to ±5 V. Every
> modulation read goes through `CvNorm()` / `CvBipolar()` in `lib/cvInputs.hpp`,
> which defer to `core/cvInput.hpp`, so the swap stays the `-DFORGE_CV_BIPOLAR`
> build flag and nothing else.

### Outputs

All four go through the MCP4728. Unlike every other module in the series, **the
jack map is not fixed** — it is the output matrix of §5. What is fixed is the
_default_ map, which mirrors NoteForge and GravityForge exactly so the muscle
memory survives:

| DAC index | Position | Panel | Default (ROUTING ▸ DUO) |
| --- | --- | ----- | --- |
| 0 | top-left | A1 | NOTE, register A |
| 1 | top-right | B1 | NOTE, register B |
| 2 | bottom-left  | A2 | GATE, register A |
| 3 | bottom-right | B2 | GATE, register B |

**Each register owns a COLUMN** in the default routing — A down the left, B down
the right — and the panel is labelled to match, exactly as ChaosForge's
generators are. Which half of the module a cable belongs to is then readable from
across a room, where two identical-looking rows are not.

The naming deliberately collides with the registers, and the collision is the
point: in DUO, jack `A2` really is register A. It is free to stop being true —
a jack named `A2` may perfectly well read register B in any other routing. The
jack name says where the cable goes; SOURCE (§5) says what comes out of it.

---

## 2. The register

Each channel holds a `uint16_t`. On a clock edge, with length `N` (2–16) and
chance `P` (0–100 %):

```cpp
bool tail = (reg >> (N - 1)) & 1;   // the bit about to wrap
if (RandomPercent(P)) tail = !tail; // ...possibly flipped
reg = (uint16_t)((reg << 1) | tail);
```

The register is always shifted as a full 16 bits; `N` only chooses which bit is
fed back, not how much of the register moves.

**What that does to the bits above `N` is worth understanding, because it looks
like a bug and is not.** They are not preserved. They keep marching up and fall
off the top at position 15, while position `N-1` copies whatever passes through
it into the region above. So the upper region is a running copy of the loop: at
CHANCE 0 it is the same loop at a different phase, and with CHANCE up it is the
loop's recent past. It is a delay line, not an attic.

Two consequences, both load-bearing:

- **ROTATE beyond LENGTH is musically meaningful**, not a jack reading dead
  bits. On a locked pattern it is another phase of the same loop — which is what
  makes §5's canon trick work at any length, not only at 16.
- **Shortening LENGTH and lengthening it again does not bring the long pattern
  back.** It is gone within `16 − N` clocks. That is the faithful Whitwell /
  ShiftReg behaviour and it is kept, but it is also the reason the register
  contents are part of a preset (§8): saving the slot is how you keep a pattern,
  not turning LENGTH back up.

### CHANCE is the original module's knob, unrolled

The Turing Machine's front-panel geometry is not three features, it is one
probability read at different points, and a plain 0–100 % control reproduces all
of it:

| CHANCE  | Original knob | Result |
| --- | --- | --- |
| 0 % | 5 o'clock | Locked. Repeats every `N` steps, forever. |
| ~50 % | noon | Maximum drift — a new sequence every pass. |
| 100 % | 7 o'clock | Locked, inverting: period **2N**, not N. |
| 10–30 % | 3 / 9 o'clock | "Slip" — a loop that changes a note now and then. |

The 100 % case is worth calling out in the manual: always-flip is just as
deterministic as never-flip, and it buys a pattern twice as long as the LENGTH
setting says. Users of the original know this trick; users who don't will find
it by turning the control to the end.

### Locking and editing

CHANCE = 0 is the lock, so there is no separate freeze control. What the module
adds instead is a **bit editor** on the home screen: the encoder walks a cursor
along the register's row and flips the bit under it.

The gesture has one platform constraint that decides its shape. The shell
reserves a **2 s hold** of the encoder for returning to the module selector
(`APP_SWITCH_HOLD_MS` in [src/main.cpp](../../../src/main.cpp)), and it forwards
the raw press/release to the app on every poll — so an app can time a press
itself, but anything it defines has to finish well inside two seconds. That
leaves:

| Gesture | Does |
| --- | ---- |
| click on HOME | enter cursor mode |
| turn | move the cursor (register A's row, then B's) |
| hold ~500 ms | flip the bit under the cursor |
| click | leave cursor mode |

Click cannot be both "flip" and "leave", which is what forces flip onto the
short hold rather than the more obvious click. **Not yet implemented** — the
home screen is currently read-only and the encoder navigates the menu as on
every other module.

This is the feature that turns a Turing Machine into something you can call a
sequencer. The workflow it is designed for is: let it drift until something good
goes past, pull CHANCE to 0 to keep it, then fix the two notes that bother you.
One encoder is a genuinely good fit for this — the row is the map, it runs in
the direction the encoder turns, and there is only ever one cursor.

`CLEAR` / `FILL` / `INVERT` / `RANDOMIZE` actions live on the register page for
the cases where editing bit by bit is the wrong tool.

---

## 3. WEAVE

The coupling. Per clock, each register's incoming bit is drawn either from its
own tail or from the other register's tail:

```
        ┌──────────── register A (16 bits) ────────────┐
   ┌───►│ bit0  ●  ○  ●  ●  ○  ○  ●  ○ ... bit N-1 ────┼──┐
   │    └──────────────────────────────────────────────┘  │
   │                          WEAVE  0..100 %             │
   │    ┌──────────── register B (16 bits) ────────────┐  │
   └────┼──── bit N-1 ... ○  ●  ○  ●  ●  ○  ○  ●  bit0 │◄─┘
        └──────────────────────────────────────────────┘
```

WEAVE is the probability, evaluated independently per register per clock, that
the incoming bit is taken from the other register instead of its own. CHANCE
still applies afterwards, to whichever bit was chosen.

| WEAVE | Behaviour |
| ----- | --- |
| 0 % | Two unrelated Turing Machines sharing a clock. |
| ~50 % | Motifs leak across and drift back — related, never identical. |
| 100 % | Tails swap every clock: A and B are **one ring of NA + NB**.  |

The endpoint is the point. At WEAVE 100 % a bit entering A at position 0 walks
to `NA-1` over `NA` clocks, crosses into B, walks `NB` more, and returns — a
single circulating ring of period **NA + NB**. Combined with CHANCE = 0 that is
a locked 32-step phrase spread across two outputs, which no amount of turning a
single Turing Machine's knob will give you.

Nothing requires the two lengths to match, and the general case is the useful
one: 5 and 3 chain into a ring of 8, 7 and 2 into 9. "Twice the length" is this
with `NA == NB`, which is only the default because both registers start at 16.

### Direction

One field qualifies the coupling. **DIR** — who feeds whom: `BOTH` · `A▸B` ·
`B▸A`.

One-way is the most useful of the three in practice and deserves its own entry
rather than being buried: with `A▸B`, register B becomes a variation on A that
cannot contaminate it. A stays the theme; B is the answer.

There is no coupling _mode_. An XOR variant (new bit = own tail ⊕ other tail)
was considered and dropped: it produces long deterministic non-repeating
structure, which is genuinely different from SWAP's endpoint, but it is a second
mechanism to explain in the manual and — worse — it is the one thing on this
module you cannot see happening on the screen. Bit exchange draws as strands
crossing between two rows (§6); a bitwise XOR draws as nothing at all. A control
whose only feedback is "the pattern sounds different now" is exactly the kind of
control this series avoids.

---

## 4. Why coupling belongs on this module at all

A fair objection: two Turing Machines and a mixer is not a new module. The test
this design holds itself to is that **WEAVE must be musically meaningful in
every routing mode of §5**, not just the two-voice one. It is:

| Routing | What WEAVE does there |
| --- | --- |
| DUO | Two basslines → two voices playing one long shared phrase. |
| MONO | The second modulation slides from unrelated to locked with the melody. |
| PULSE | Two independent 2-track drum patterns → one 32-step pattern across 4 tracks. |

If a future routing mode cannot answer that question, it does not belong in the
list.

---

## 5. The output matrix

Enigma's genuinely good idea is that registers and outputs are decoupled: an
output picks a source and a _type_, rather than the module hard-wiring which
jack is pitch. That is cheap to implement and it is what lets a 4-jack module be
several different instruments.

Each of the four jacks owns a slot:

| Field | Values |
| --- | --- |
| SOURCE | `A` · `B` · `AB` (the woven 32-bit ring — see §3) |
| TYPE | `NOTE` · `MOD` · `GATE` · `TRIG` |
| DEPTH | 1–8 bits — the window width read out of the ring |
| ROTATE | 0–15 (0–31 for `AB`) — where in the ring the window sits |
| _(contextual)_ | NOTE ▸ RANGE · MOD ▸ LEVEL · GATE/TRIG ▸ THRESH |
| _(contextual)_ | NOTE/MOD ▸ SLEW · TRIG ▸ WIDTH · GATE ▸ — |

Six fields, which is exactly the six rows a menu page holds — so each jack is
one page, four pages, no scrolling and no seventh row silently clipped off the
bottom at y=57.

**Those four pages are walked in panel order — A1, A2, B1, B2 — not in DAC
order.** The DAC order is the rows (top-left, top-right, bottom-left,
bottom-right) and it is fixed by the hardware, but the panel is labelled by
column and each register owns one in the default routing (§1), so a list in DAC
order puts B1 between A1 and A2 and interleaves the two halves of the module on
the one screen where you are setting up a jack you are looking at.
`WEA_JACK_COLUMN_ORDER` in `lib/outputs.hpp` is the single source of that order:
the OUT pages, the ROUTING page summary and the Rack context menu all walk it,
the last via `jackAt()` on the engine bridge so the plugin cannot drift. The
menu group IDs still map straight to jack indices — it is the order the blocks
sit in `MENU_ITEMS[]` that the encoder follows.

### ROTATE earns its place

Enigma offers rotation only on favourited registers. Here every jack has it, and
it costs one modulo add. Four jacks tapping the _same_ register at different
offsets are four phase-shifted copies of one pattern — canons, rounds, a bass
line and its own echo four steps late. It is the highest musical return per line
of code in the module.

### The types

**NOTE** — the DEPTH-bit window becomes a scale degree:

```
index  = (window * DegreesPerOctave() * RANGE) >> DEPTH
semitone = quantizer.SemitoneAt(index) + rootOffset
```

DEPTH sets _resolution_ and RANGE (1–5 octaves) sets _span_, which keeps the two
independent — 3 bits over 2 octaves is a sparse, singable line; 7 bits over the
same 2 octaves is a fine-grained wander through it. Uses
[core/quantizer.hpp](../../../core/quantizer.hpp) and
[core/scales.hpp](../../../core/scales.hpp) unchanged; the scale mask is
module-wide (one root, one mask, §7), not per jack.

**MOD** — the window scaled to 0–LEVEL % of 5 V. This is the original module's
main CV output, and at DEPTH 8 it is the same signal.

**GATE / TRIG** — see below. GATE holds high while the condition is true and
falls at the first clock where it is not; TRIG emits a fixed-width pulse.

### THRESH, and why GATE is not just bit 0

The obvious implementation — "output high when bit 0 is 1" — gives every gate
output a fixed ~50 % density that nothing can change. Four such outputs is not a
drum machine, it is four coins being flipped.

Instead the DEPTH-bit window is compared against a threshold:

```cpp
const int span  = 1 << DEPTH;
const int limit = (threshold * span) / 100;
bool fire = window >= span - limit;   // the TOP `limit` values of the range
```

THRESH 12 % is a sparse kick, 88 % is a busy hat, and the whole thing is still
driven by — and locked to — the same register as the melody. At DEPTH = 1 and
THRESH = 50 % it collapses exactly to the classic bit-0 behaviour, so the
original is a point in this space rather than a special case.

**Both halves of that comparison are load-bearing, and the first version got the
first half wrong** — it fired on `window < limit`, i.e. on the LOW values. A set
bit has to be the one that plays: the screen draws bit 1 as a filled cell and bit
0 as a hollow one, and every shift-register sequencer since the Turing Machine
fires on the 1, so firing on the low values meant a row of empty cells played
while a row of full ones sat silent. The panel, the screen and the manual all
described the opposite of what the jack did.

Counting the qualifying values down from the TOP of the range rather than up from
the bottom is what keeps THRESH meaning what it says. `limit` values out of `span`
qualify either way, so the density is `threshold` % whichever end they are taken
from — the naive repair, `window >= limit`, fixes the polarity and silently
inverts the control, turning a sparse kick at 12 % into a busy one.

### ROUTING is a macro, not a mode

The three configurations the matrix is _for_ are one menu item at the top of the
outputs page:

| ROUTING | A1 | B1 | A2 | B2 | The module is... |
| --- | --- | --- | --- | --- | --- |
| `DUO` | NOTE A | NOTE B | GATE A | GATE B | two voices |
| `MONO`  | NOTE A | GATE A | MOD A (rot 8) | MOD B | one voice + two correlated modulations |
| `PULSE` | TRIG A | TRIG A (rot 8) | TRIG B | TRIG B (rot 8) | the Pulses expander, in software |

**Selecting one stamps the four slots and nothing more.** The slots remain the
source of truth and stay individually editable; when they no longer match any
template the item reads `CUSTOM`.

This is the pattern [core/scales.hpp](../../../core/scales.hpp) already
establishes for note masks — "a scale here is only a helper for _populating_ the
mask; the mask is the source of truth, and the user is free to edit it
afterwards, which leaves it no longer matching any named scale." Following it
here means no mode/expert split, no settings that exist in one mode and vanish
in another, and no second code path.

`CUSTOM` is **recomputed by comparing the slots against the three templates**,
not stored. A stored mode index goes stale the moment a slot is edited from CV
or a preset load, and a preset that happens to match DUO should say DUO.

---

## 6. The screen

Home is **the loom**: two rectangular registers facing each other, running in
opposite directions, with the weave itself drawn in the channel between them.

```
 ▶ 124  ÷2                        WEAVE 65%
A ■□■■□□■□■■□■ · · · ·                    ▸
  └──────── len 12 ────────┘ ▲
     ╲   ╱ ╲       ╱ ╲   ╱
      ╳ ╱   ╲     ╳   ╲ ╳
     ╱ ╲     ╲   ╱ ╲   ╱ ╲
  ◂        └──── len 8 ────┘
B □■■□■□□■ · · · · · · · ·
   1▲      3▲        2▲   4▲
  CHANCE A                        24%
```

**The two rows flow in opposite directions** — A left to right, B right to left
— and that is the whole reason there are two rows rather than one. At WEAVE
100 % the chain becomes a visible racetrack: out of A's right end, down
through the channel, back along B, up into A's left end. A bit can be followed
around it with a finger. Two rows flowing the same way would draw that circuit
as a crossing tangle, and one long row would not draw it at all.

**The channel between them is the weave**, and it is the only animated element:
at WEAVE 0 the two rails run flat and parallel with nothing between them; strand
crossings appear as the control comes up, their count proportional to it; at
100 % it is a full braid. DIR shows as which way the arrowheads on the strands
point. The module is named for this and the screen draws it literally — the
picture of woven cloth **is** the parameter.

### What a cell says

Four states, all legible on a 1-bit panel at arm's length:

| Drawn | Means |
| --- | --- |
| ■ 6×6 filled  | bit = 1, inside the active length |
| □ 6×6 hollow  | bit = 0, inside the active length |
| ▨ 6×6 shaded  | bit = 1, past the feedback point |
| · 2×2 dot | bit = 0, past the feedback point |

LENGTH is therefore a _visible boundary_, not a number to read: the point where
the row goes dim. The delay line of §2 is drawn dimmer rather than omitted
because an output ROTATEd out there is reading it — and it shows its BIT VALUE
for the same reason. A single flat marker for the whole region, which is what
the first version drew, says "something is here" about cells a jack is actively
reading and refuses to say what; it is drawn dim, not small, because it is not
part of the loop and shortening LENGTH is about to overwrite it.

The third tone is a **checkerboard**. There is no grey on a 1-bit panel, but the
SSD1306 is a true pixel grid and the Rack port's OLED widget area-integrates, so
both hosts resolve one to a tone rather than to a visible pattern.

### What moves

The screen has to distinguish a running module from a stopped one, and at
CHANCE 0 — the setting the module is _sold_ on — every frame is otherwise
byte-identical. Three things animate, all driven by `StepClock::StepPhase()` and
`StepCount()`, both display-only: nothing that produces a voltage may read them,
or the outputs would depend on the frame rate.

| Element | Says |
| --- | ---- |
| the fresh-bit hole, at each row's entering end | which bit arrived on this clock |
| the travelling braid | the cloth is being drawn through the loom |
| the crossing courier | a bit **actually** jumped on this step |

A caret above each row marks the **feedback tap**, bit `LENGTH-1`. It is the most
important cell in a Turing machine — the bit about to wrap, the one CHANCE flips
on the way round, and the one a courier departs from — and nothing pointed at it,
so the only way to find the tail was to wait for a crossing, and at WEAVE 0 there
was no way at all. It also gives LENGTH a second reading: the shading boundary
says where the loop ends, the caret says which cell closes it.

**A strand is exactly 45°** — one pixel across per pixel down — so it spans as
many columns as the channel has rows. That is forced, not chosen. The first
version spanned a fixed 8 columns over however many rows the channel happened to
have, stepping `x0 + (i * 8) / h`; at `h = 7` that yields offsets 0,1,2,3,4,5,6,8,
so offset 7 never appears and every strand ran straight for seven rows and then
jumped two pixels sideways. Nine columns over eight rows is not a line. It read
as a bent strand with a detached pixel at the end, worst on the rightmost one
where nothing follows it to make the pattern legible — and the fixed width also
made the marks along the rails alternate 8 px / 6 px apart at WEAVE 100 instead
of falling evenly. Any change to the channel's height has to keep the strand
width tied to it (`LOOM_STRAND_W`), or the slope stops being 45° and the kink
comes back.

**Every animation moves at the rate the bits do**, and that constraint decides
each one's speed rather than taste. The braid travels one **cell pitch per
clock** — the same distance the registers shift — which is why it needs
`StepCount()` and not the phase alone: the first version scrolled a whole strand
span per clock, and the span is `112/strands`, so the cloth flew past at a low
WEAVE and crawled at a high one. Fastest exactly where least was crossing.
Speed must not depend on the control the picture is describing.

The courier earns its place twice over. WEAVE is a probability, so the braid
draws the _setting_ and is the same picture on the step where a bit crossed and
the step where none did; the courier draws the _event_. It runs between the two
cells the transfer is really between — out of the sender's tail, the cell LENGTH
selects, and into the receiver's bit 0, where the next frame draws it as the
fresh bit — so the animation joins up with the register rows rather than floating
between them. `WeavePair::Crossed()` is what it reads, and that flag is
observation only: nothing in `shiftreg.hpp` reads it back, so the file stays a
pure function of its inputs (§10).

Below about two frames per step the phase is a lie — successive redraws sample
unrelated points in the step — so the marks that depend on landing inside a
fraction of it drop out. The registers are a blur at those rates anyway.

**A full-width sweep line under the header was tried and removed.** It was the
largest moving thing on the screen and the least informative one; it read as a
progress bar for something that is not loading. The three animations above
already say the module is running _while also_ saying something about the
pattern, which is the bar an element on a 64-row screen has to clear.

### Where an output reads

Each jack's window — the DEPTH cells it is reading, at its ROTATE offset — is
barred underneath its row, between the cells and that jack's label. Without it
the label says only where a jack _starts_ reading, and a NOTE at DEPTH 5 is built
from five cells; the window exists nowhere on screen and the pitch you are
hearing has no visible source. Barred rather than boxed, because the cell outline
already means "bit = 0" and a second rectangle would read as a bit value.

Several jacks routinely read the same cells — the DUO default puts a NOTE and its
GATE both on register A at ROTATE 0 — so the bars merge. The jack being edited is
redrawn at cell _pitch_ rather than cell _width_, closing the 1 px gaps into one
solid bar, which picks it out of the pile without needing a row the screen does
not have.

### The leaders, and why labels cannot simply sit on their taps

Jacks sharing a tap have their labels packed left to right from it, because two
labels drawn at the same x print on top of each other. That packing means only
the FIRST label sits over its own cell: in the DUO default `A2` lands two cells
to the right of the one it taps, and the screen then states something false about
where a jack reads. This was live until the screenshot tool (`make screen-wea`)
made it visible — a photo of the panel cannot resolve it.

So each label gets a **leader** on a row of its own between the window bars and
the labels, running from the cell to the label that names it. The chain reads
cell ▸ window bar ▸ leader ▸ label, each touching the next.

Two details are load-bearing. The leader is **dotted**: drawn solid it stacked
under the window bar into a two-row slab and read as a fatter bar, which is the
one thing the row exists not to be. And the dots are on an **absolute parity**
rather than one relative to each leader's own start, so leaders that merge —
which they should, when jacks share a tap — stay dotted instead of filling each
other in.

The row was paid for by the labels, not the loom: a tap label is the classic
font's 8-row cell, but the glyphs here are capitals and digits, all of which
leave the last row empty for descenders. The lit block behind a speaking jack is
therefore 7 rows. It may not be widened back — row 29, under register A's
labels, is the weave channel's top rail.

The bracket under each row marks the active span and carries two more things:
the **bit-editor cursor** (`▲`), and the **output taps** — each jack's digit sits
at its ROTATE column under its source register. Seeing `1▲` and `3▲` four cells
apart is the only thing that makes ROTATE stop being an abstract number. Jacks
sourced from `AB` address the combined 32-cell ring and their digit lands on
whichever row that offset falls in, which is also how you learn what `AB` means
without reading the manual.

### Pixel budget

128×64 exactly, no scrolling, at 16 cells on a 7 px pitch (6 px cell + 1 px gap
= 112 px, centred with 8 px margins):

| Rows  | Content |
| ----- | --- |
| 0–11  | header — tempo in helvB12, rate and WEAVE % small  |
| 12–13 | A's feedback-tap caret |
| 14–19 | register A, flowing ▸ |
| 20 | A's output windows |
| 21 | A's tap leaders |
| 22–28 | A's output taps (length bracket, cursor: unbuilt)  |
| 29–38 | the weave channel — braid and couriers |
| 39–40 | B's feedback-tap caret |
| 41–46 | register B, flowing ◂ |
| 47 | B's output windows |
| 48 | B's tap leaders |
| 49–55 | B's output taps (length bracket, cursor: unbuilt)  |
| 56–63 | status line — the two lengths, the two chances |
| 54–63 | the live strip, over the status line while editing |

**The budget is exactly full, and the header is what fills it.** A helvB12 digit
is 12 rows, so the tempo cost four rows off the loom — two from the weave channel
(12 → 10) and one from each row of tap labels (9 → 8, which is the classic font's
cell exactly, so a lit label's block now has no padding row above it). There is
nowhere for a fifth row to come from. Anything else wanting large type has to
take it from something on this list, and the channel has no more to give: the
strands are diagonals, and below about 8 rows they stop reading as crossings.

The font is `core/fonts/helvB12.h`, shared with ClockForge and ScopeForge — it
used to be three byte-identical copies, one per app plus the Rack shim's. It is
included from inside the app's namespace like every other header here, which is
what keeps the unified firmware and the consolidated plugin from seeing several
definitions of the same glyph tables.

### Why not rings

Circles were the first sketch and are the wrong answer here. They are
GravityForge's face, so the series would have two modules that look alike from
across a room; the counter-flow reading that makes the chain obvious costs a
crossing tangle once both rings are round; a 32-position combined ring is
cramped at this diameter; and rectangular cells put the bit editor's cursor on a
straight line the encoder walks in one direction, which is what one encoder is
good at.

The row-of-LEDs every other Turing Machine uses is not this either — that is one
row, unlabelled, with no length boundary, no taps and no weave.

---

## 7. Clock, scale and CV

**Clock.** IN 1 with an internal fallback so the module does something on a
bench with nothing patched.

The shared part is promoted to **`core/clockSource.hpp`**, lifted out of
[apps/gen/lib/clock.hpp](../../gen/lib/clock.hpp) and trimmed to what a module
needs to know what time it is:

| Promoted to `core/` | Stays in GravityForge's `lib/clock.hpp` |
| --- | --- |
| BPM range, the external-PPQN enum and its tables | beats-per-revolution rotation mapping |
| external edge → interval → BPM, with outlier rejection | the `QuantizeDiv` hit grid |
| internal/external source selection and fallback | `NoteSpace` thinning |
| time always **passed in**, never read from a wall clock | `ConsumeBoundary()` and the LOOP phrase machinery |

The passed-in-time rule is the load-bearing one and the reason this promotion is
safe: it is what makes the clock testable on the host and deterministic in the
Rack port, and it is already how GravityForge works.

**GravityForge is migrated by composition, not rewrite** — its `Clock` keeps its
name and its API and gains a `ClockSource` member. A shipping module under test
should not be restructured to serve an unwritten one, and its native tests in
[apps/gen/test/](../../gen/test/) are the guard that the lift changed nothing.

### ClockForge is not a third consumer, and should not be made one

Worth settling now, because it looks like it ought to be. ClockForge's time base
is [apps/clk/lib/clockEngine.hpp](../../clk/lib/clockEngine.hpp): a 960-PPQN
**hardware-timer ISR** with file-scope `BPM` and `tickCounter` globals, tap
tempo, and the whole module driven from the interrupt. GravityForge's is a
passed-in-time value object with no timer and no globals. These are not two
copies of one thing — they are opposite architectures that happen to share the
word "clock", and folding one into the other means rewriting ClockForge's core
so that a new module can save eighty lines.

This is the same call [README.md](../../../README.md) already records for the
quantizer: _"ClockForge's quantizer is deliberately not shared: it is a separate
implementation reached through `Output` rather than a channel, so folding it in
would be a port rather than a merge."_ The clock is that situation again, with
more at stake, since ClockForge's ISR is the one piece of real-time code in the
series with no slack in it.

What would have to be true first: ClockForge would need its ISR to consume a
tempo rather than own one, and that refactor should be justified by ClockForge's
own needs, not by WeaveForge's. Until then `core/clockSource.hpp` has two
consumers, which is the threshold `core/` is meant to have anyway.

Also on the clock page: CLOCK DIV (÷1–÷16) and, for the internal clock, RATE.
The divider stays module-local — it is three lines and GravityForge has no use
for it, since its physics free-runs and is never stepped.

**Scale** is module-wide — one root, one mask, one keyboard page, reusing
NoteForge's. Per-jack scales were considered and dropped: two NOTE outputs in
different keys is a patch you can build with two modules, and the shared mask is
what makes the DUO routing sound like one instrument rather than two.

**CV targets** for IN 2 / IN 3, same `BuildModBus()` shape as
[apps/gen/lib/cvInputs.hpp:177](../../gen/lib/cvInputs.hpp#L177):

```
OFF · LEN A · LEN B · LEN AB · CHANCE A · CHANCE B · CHANCE AB
    · WEAVE · TRANSPOSE · ROTATE ALL · RESET · LOCK
```

`RESET` and `LOCK` are threshold-detected gates rather than continuous targets —
`LOCK` forces CHANCE to 0 while high, which is ShiftReg's Digital-2 trick
reachable without a second digital jack. As in every other module, **append to
this enum, never insert**: presets store the target as a raw index.

---

## 8. Preset schema

Ten slots via [core/appStorage.hpp](../../../core/appStorage.hpp), slot 0
auto-loaded at boot.

**The register contents are part of the preset.** Four bytes, and without them a
preset restores a machine that makes a different pattern — which for this module
means it restores nothing at all. Saving the pattern is the whole point.

```cpp
struct LoadSaveParams {
    uint8_t  valid;
    uint16_t reg[2];          // ← the patterns themselves
    uint8_t  length[2], chance[2];
    uint8_t  weave, weaveDir;
    uint8_t  outSource[4], outType[4], outDepth[4],
             outRotate[4], outParam[4], outParam2[4];   // the four slots
    uint16_t noteMask;  uint8_t scaleIndex, rootIndex; int8_t octave;
    uint8_t  clockDiv, clockRate, clockSource;
    uint8_t  cvTarget[NUM_CV_INS], cvDepth[NUM_CV_INS];
    int      menuScreenTimeout;
};
```

No ROUTING index — §5. Every field here must appear in `CollectParams()`; a
parameter reachable from the menu but missing from it is silently not persisted,
and in Rack silently lost on patch reload.

---

## 9. Deliberately left out

**Enigma's library, banks and song mode.** 40 registers in five banks, four
tracks of up to 99 steps, transposition per step, SysEx dump. It is a fine
design _for its hardware_ — two encoders, four buttons, and a screen you can
put a table on. Reproducing it on one encoder would mean a four-level nested
edit for every step, and a preset schema an order of magnitude larger than
anything else in the series. The part of Enigma worth having is the output
assignment matrix, and that is §5.

**A coupling mode (XOR)**, §3 — dropped because it is the one mechanism on this
module the screen cannot draw.

**Register stride** (shift by 2 or 3 instead of 1). Genuinely interesting — it
fragments a loop into interleaved sub-patterns — but it breaks the one-to-one
relationship between the row drawn on screen and the order bits are heard in,
which is the thing making this module legible. Revisit only with a screen design
that can show it.

**Folding ClockForge into `core/clockSource.hpp`**, §7 — a port, not a merge.

**Per-jack scales**, §7. **A second digital input**, §1.

**An IN 1 role menu.** §1 — the clock is not optional here.

---

## 10. File map

Mirrors ChaosForge; see [../AGENTS.md](../AGENTS.md) once written.

| File | Purpose |
| --- | --- |
| `src/wea_app.cpp` | the `forge::IApp` — `Begin`/`Tick0`/`Tick1`, encoder events, all file-scope state |
| `src/wea_app.hpp` | `forge::WeaApp()` factory, the only thing the shell includes |
| `lib/engine.hpp` | the per-iteration step + `DACWriteAll()`, **shared with the Rack port** |
| `lib/shiftreg.hpp` | `ShiftRegister` + `WeavePair` — the bit machinery, pure, no I/O |
| `lib/outputs.hpp` | the four slots, the four types, `ROUTING_TEMPLATES[]` |
| `lib/clock.hpp` | the ÷1–÷16 divider and the step edge, over `core/clockSource.hpp` (§7) |
| `lib/params.hpp` | `RegParams` / `WeaveParams` / `ModBus` + `ApplyParams()` |
| `lib/cvInputs.hpp` | `CvNorm()`/`CvBipolar()`, `CVTarget`, `BuildModBus()` |
| `lib/randomize.hpp` | `RandomizeParams()` — backs PRESETS ▸ RANDOM and Rack's Randomize |
| `lib/menuDefinitions.hpp` `lib/menuHandlers.hpp` `lib/menuRender.hpp` | the menu, its setters, the loom home screen |
| `lib/presetManager.hpp` `lib/storage.hpp` `lib/version.hpp` | §8, and the four-line storage shim |

Plus `vcv-plugin/` (standalone Rack plugin, slug `WeaveForge`), an entry in
`vcv/` for the consolidated build, `test/test_native/`, an `env:xiao_wea` in the
root [platformio.ini](../../../platformio.ini), and the `kApps[]` entry in
[src/main.cpp](../../../src/main.cpp).

---

## 11. Constraints inherited from the platform

- **Every mutable file-scope global in `lib/` must be listed in**
  `vcv-plugin/src/engine/engine_state.def`, or two Rack instances share it.
  `make isolation` is the guard and only the Rack build catches a stale entry.
  For this module that is both registers, so the failure mode is two WeaveForges
  playing the same pattern — obvious, at least.
- **Six rows per menu page.** `MD_START_Y=12` + `MD_ROW_H=9` puts row 6 at y=57;
  a seventh is clipped with no error. §5's six fields per jack is not a
  coincidence.
- **All four outputs are DAC** (MCP4728). Gates and triggers are DAC levels, and
  minimum trigger width is bounded by the `Tick0` period — TRIG ▸ WIDTH must
  clamp to something the loop can actually produce.
- **DAC channel swap**: hardware swaps DACB↔DACC, compensated by `_chanMap[]` in
  [core/boardIO.hpp](../../../core/boardIO.hpp).
- **Panel SVG**: `vcv-plugin/res/WeaveForge.svg` is the single source of jack
  labels; nanosvg ignores `<text>`, so every glyph is a path. Keep an editable
  `-src.svg` and re-run the Inkscape conversion rather than hand-editing.
- **Cost.** Two `uint16_t` plus a few dozen bytes of parameters: this is the
  smallest engine in the series, below NoteForge's ~0.7 KB. The work is the
  plumbing, not the DSP.

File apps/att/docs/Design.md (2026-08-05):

# ChaosForge — design notes

Why the module is built the way it is. The user-facing guide is
[../Manual.md](../Manual.md); the coding rules are [../AGENTS.md](../AGENTS.md).

---

## 1. The idea

A modulation source has two usual shapes. An LFO repeats exactly, which is
predictable and eventually boring. A random source never repeats, which is
unpredictable and has no shape at all — sample-and-hold is the same texture
forever, whatever you do to it.

A strange attractor is the third thing. It is completely deterministic, its
trajectory is smooth and it has an unmistakable shape you can learn to hear, and
yet it never repeats and two copies started a thousandth apart end up somewhere
entirely different within seconds. That is the whole proposition: modulation that
behaves like a *system* rather than like a waveform or a die.

The module runs two of them at once, and takes two of each system's three state
variables to a jack. That pairing matters more than the count:

- **two jacks from one orbit are related but never equal.** They are two views of
  one moving object. Patch them to filter cutoff and resonance and the two move
  together in a way no pair of free-running LFOs ever does, but they never line
  up into an obvious ratio the way two synced LFOs do.
- **two jacks from different orbits are unrelated** — until COUPLE says
  otherwise.

Prior art: Hemisphere Suite's Low-rents applet (Lorenz + Rössler, two generators,
a vectorscope screensaver), and Mutable Instruments' Streams, whose Lorenz code
Low-rents ported. This module keeps the pairing and the vectorscope and adds
twelve systems, editable constants, coupling between the generators and output
scaling that adapts to what the constants were changed to.

---

## 2. Integration: RK4 on a fixed 1 ms module step

**Why RK4 rather than Euler.** On a stiff system like Lorenz, Euler does not
merely lose accuracy — it changes the attractor. The orbit spirals outward and
eventually diverges, which on a jack is a CV that slams to a rail and stays
there. RK4 costs four derivative evaluations per step and buys an order of
magnitude in stable step size, so for a *bounded* orbit it is also the cheaper
option.

**Two clocks, deliberately.**

| | unit | changes with |
| --- | --- | --- |
| module step | 1 ms of real time | never |
| integrator step `h` | the attractor's own time units | SPEED |

SPEED decides how much attractor time each 1 ms slice covers; the slice itself is
fixed. Keeping them separate is what makes SPEED a smooth control rather than a
change of simulation grid, and the fixed slice is what makes the simulation
deterministic and testable.

Each system carries two constants for this:

- `hMax` — the largest RK4 step it stays accurate at, taken from the reference
  simulators these systems were tuned in.
- `rate` — attractor time units per real second at the rate the system is
  normally *catalogued* at. This is what makes SPEED mean the same thing on every
  system: Thomas advances 24 units a second there and Chua 0.96, yet both trace
  their figure at a comparable rate. Without it, changing system would be a wild
  jump in output rate.

**SPEED 1.00 is a tenth of the catalogued rate** (`ATT_RATE_SCALE`). Those rates
come from simulators built to be *watched*, and a rate that looks good on a
screen is a fast one to modulate with: at the catalogued rate a Lorenz wing takes
a third of a second, which is a 3 Hz LFO. At SPEED 1.00 it takes about four
seconds, which is where a modulation source wants to sit. The range runs to 100x,
so the catalogued rate and beyond are still reachable — only the middle of the
dial moved.

It is one constant rather than twelve edited `rate` values, so the table keeps
meaning "as catalogued" and the decision stays reversible in one place.

**Everything else that is a rate scales with SPEED too.** The auto-range relax
and the coupling strength are both "per second" quantities, and leaving them in
plain wall time would mean a slow patch had its window closed and its orbits
dragged ten times harder relative to the motion feeding them. Both are multiplied
by SPEED so they describe an amount of *orbit* rather than an amount of time. The
one deliberate exception is SMOOTH, which is a filter and belongs in
milliseconds — but its maximum had to grow with the slowdown, since 200 ms
rounded nothing off a fold that now takes over a second.

**The substep cap.** A 1 ms slice is split into `ceil(rate x scale x speed x
1 ms / hMax)` substeps, capped at `ATT_MAX_SUBSTEPS` (8). If the cap ever binds,
the step grows past `hMax` instead of time slowing down — an honest clock with
degraded accuracy beats a SPEED control that silently stops speeding up. At the
current ranges it never binds: the worst case at `ATT_SPEED_MAX` is seven
substeps, and every system is at or under its own `hMax` there. The cap remains as
a bound on what one module step can cost. Anything that does escape is caught by
`AttDiverged()` and re-seeded.

**Budget.** At SPEED 1 each generator runs 1000 RK4 steps/s — one per module step,
since the wanted step is well under `hMax` there. A step is roughly 70 soft-float
operations, so two generators cost a few percent of one M0+ core. At the top of
the SPEED range with both maxed it is ~7000 steps/s each, which is the worst case
the cap exists to bound.

**Divergence is caught, not clamped.** The parameter ranges are wide enough to
include settings where a system has no bounded attractor at all, and a divergent
orbit reaches 1e30 in a handful of steps. `AttDiverged()` tests `-1e5 < s < 1e5`
as a positive range check, which catches NaN in the same expression (every
comparison against NaN is false), and the generator re-seeds. A re-seed is heard
as the pattern restarting; a clamp would be heard as a dead module.

---

## 3. Getting an orbit into 0–5 V

The jack is 0–5 V. A Lorenz z lives in 3..47, a Chua y in ±0.4. Something has to
map one onto the other, and what it does when the constants are moved is the
whole question.

**FIXED — the published window.** `centre[]`/`halfSpan[]` per axis in
`ATTRACTORS[]`, measured rather than guessed: each system was run for ~700
simulated seconds at its published parameters and these are the **0.2/99.8
percentiles** of the resulting orbit.

Percentiles rather than true extremes, because a chaotic orbit's excursions are
rare and enormous. Sizing the jack to Lorenz's rarest z spike would spend most of
the range on a voltage you hear once a minute; the occasional clamped excursion is
a hundred times less audible than permanently halving the swing.
`PublishedWindowFillsMostOfTheJack` asserts every axis of every system still uses
more than 55 % of the range, which is what catches a mistyped constant.

**AUTO — the tracked window.** Those constants are only exact at the published
parameters. Move Rössler's C from 5.7 to 2.5 and the orbit is less than half the
size it was measured at, so the jack quietly loses more than half its swing. AUTO
tracks the orbit's own min/max instead:

- **instant on the way out**, because a clipped peak is the thing this exists to
  prevent;
- **slow on the way in** (5 % of the window per second, per side), because a
  chaotic orbit's excursions can be minutes apart and a fast relax would re-gain
  the CV between them;
- **floored**, because a system parked near a fixed point has a near-zero span and
  dividing by it turns numerical dust into full-scale CV.

FIXED is the default: it is predictable and identical from one boot to the next,
which is what you want when a patch depends on the voltage. AUTO is one click away
when it stops being.

**LEVEL and OFFSET are applied after normalisation, never inside the
simulation.** What the orbit does must not depend on how it is being listened to.
LEVEL scales around the centre of the range, so LEVEL 0 parks the jack at 2.5 V
rather than at a rail — a modulation depth control that jumped to 0 V when turned
down would be unusable as a VCA target.

---

## 4. Which twelve systems, and why those defaults

The set is drawn from the two reference simulators this module started as:
Lorenz, Rössler, Thomas, Chua, Halvorsen, Chen, Burke-Shaw, Aizawa, Dadras,
Sprott B, Sprott C and the Ma–Chen finance system.

**Four parameters, never more.** A menu page is six rows, and the SYSTEM page
carries TYPE and SPEED as well. Two systems naturally have more — Aizawa has six,
Dadras five — and rather than drop them, the constants that only reshape the
figure (Aizawa's e and f, Dadras's e) are fixed at their published values and the
four musical ones are exposed.

**Every shipped system must be genuinely chaotic at its defaults.** Two were not,
at the parameters they are usually published with. Measuring the largest Lyapunov
exponent by the two-orbit renormalisation method (two copies separated by 1e-9,
re-normalised every step, the mean log growth rate) gives:

| system | λ | e-folds/sec at the catalogued rate |
| --- | --- | --- |
| Lorenz | +0.91 | 2.2 |
| Rössler | +0.07 | 0.7 |
| Thomas (b = 0.19) | **+0.0001** | **0.0** |
| Chua | +0.41 | 0.4 |
| Halvorsen | +0.67 | 2.0 |
| Chen | +2.05 | 2.5 |
| Burke-Shaw | +0.70 | 1.7 |
| Aizawa | +0.10 | 0.6 |
| Dadras | +0.39 | 0.9 |
| Sprott B | +0.21 | 1.5 |
| Sprott C | +0.16 | 1.2 |
| Finance (a = 0.001) | **−0.0000** | **0.0** |

Thomas at b = 0.19 and Finance at a = 0.001 are **limit cycles**, not attractors.
On a limit cycle two nearby orbits converge and stay in phase, so the two
generators tracked each other forever and the module had two outputs rather than
four. The fix was to move both defaults into a genuinely chaotic band —
Thomas b = 0.05 (λ = +0.12) and Finance a = 0.95 (λ = +0.10) — and to draw their
parameter ranges around those bands rather than around the equations'
mathematically legal values.

This was found by `TheTwoGeneratorsDivergeFromEachOther`, not by ear, which is
why that test exists and why adding a system means measuring it.

**The periodic windows are left reachable on purpose.** Thomas's B in particular
is mostly *not* chaotic across its range, and a limit cycle there is a pair of
smooth, perfectly repeating LFOs with an unusual shape — a useful thing for the
module to be able to do, and one it can only do because the ranges were not
trimmed to the chaotic bands alone.

---

## 5. COUPLE

The signature control, and the reason the two generators are in one module rather
than being two copies of a simpler one.

It is **diffusive coupling**: each orbit is pulled toward the other by a fraction
of their difference, every module step, on all three axes. What comes out of it is
the real phenomenon of chaotic synchronisation — turned up far enough, two copies
of one system converge onto a single orbit and stay there, and two *different*
systems are entrained: they start sharing their timing while keeping their own
shapes.

Three decisions inside it:

- **In normalised units.** The systems' natural sizes differ by two orders of
  magnitude. Exchanging raw state would mean Chen simply overwriting Chua.
- **Symmetric.** Each orbit is pulled the same distance toward the other, so
  neither is master. Two copies of one system converging to a single orbit — four
  jacks becoming two — is the intended extreme and the clearest demonstration of
  what the control does.
- **Squared.** The interesting region, entrainment without lock, is narrow and
  sits near the bottom; a linear taper puts all of it in the first few percent.

At full coupling two *different* systems are dragged off their own attractors,
which is a legitimate place to be and is why
`CouplingLeavesDifferentSystemsBoundedAndAlive` exists: it must not flatten either
one into a stuck voltage.

---

## 6. The screen

Two Lissajous plots, one per generator: each generator's two output values
plotted against each other. It is the only view that shows what the module is
doing — one trace against time shows a wobble, the pair shows the attractor.

The trail is sampled **on the orbit's own clock**, not the frame clock: a point
every 1/40th of the attractor time the system covers in a second at its
catalogued rate. So the drawn arc covers the same amount of *trajectory* at every
SPEED, and the figure looks like itself whether it is being traced in ten seconds
or in a minute — at SPEED 1.00 a full 256-point buffer is about a minute of
drawing, which is simply how long a slow orbit takes to go round. A wall-time
floor sits under that, or SPEED 0.01 would leave the screen unchanged for seconds
at a time and read as a hung module.

**The head is drawn from the live output, not from the newest stored point**, and
the last segment runs from that point to it. Without that the whole picture only
changes when a trail point is pushed — four times a second at SPEED 1.00 — and
the screen stutters while the jacks are perfectly smooth. That was the first
thing anyone noticed about it. Measured on the emulated panel, the fix took the
plot from 4 to 8 distinct frames per second at SPEED 1.00, where the remaining
limit is that the head moves less than a pixel per frame, and from 16 to 24 at
SPEED 10.

This module also asks `DisplayManager` for a 30 fps redraw instead of the 20 fps
every other module uses. Their home screens are pages that change when you touch
something; this one is an animation, and 20 fps is visibly steppy at the middle
of the SPEED range. It costs Core 1 duty cycle and nothing else — the display bus
belongs to Core 1 alone, and the DAC is on the other bus behind Core 0, so a
faster screen cannot slow the outputs down.

What is plotted is the value **before** LEVEL and OFFSET, so the figure keeps
filling the frame however the jacks are scaled. The screen is for the shape; the
jack is for the voltage. Values outside the window are pinned to the frame rather
than dropped, so a clipping output is visible as the trace flattening against the
edge — which is exactly what the jack is doing at that moment.

---

## 7. Deliberately left out

**Gate or trigger outputs from threshold crossings.** Low-rents can XOR and sum
its generators into gate-ish outputs, and a threshold crossing on a Lorenz wing is
a decent event source. It was left out because all four jacks are spoken for by
the pairing above, and a jack that is sometimes a CV and sometimes a gate is a
worse version of both. A comparator downstream does this better and costs the
patch one module.

**Clock sync.** A chaotic system has no period to sync to, so anything honest here
would be a rate control locked to tempo — which is what SPEED already is, minus
the tempo. If it lands later it belongs on the CV page as a target, not as a
transport.

**Systems with more than four exposed parameters.** See §4: the page is six rows.

**Randomising RANGE, the IN 1 role, the CV matrix or the view.** Those are patch
wiring and preferences. Rerolling them turns "give me a new shape" into "break my
patch", which is the same line VCV Rack draws when it leaves ports alone on
randomize.

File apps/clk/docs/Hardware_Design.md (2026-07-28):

# Hardware Design

This document provides an overview of the hardware design for the ForgeSeries-CLK module. The module is designed to generate clocks, waveforms, and envelopes, and it is built on a powerful microcontroller platform.

## Microcontroller

The module uses the Seeed XIAO RP2040 microcontroller, which is based on the RP2040 chip. This microcontroller provides sufficient processing power and I/O capabilities to handle the module's functionality.

### Pinout

Looking from the front of the module, counted counter-clockwise starting from the top-left corner, the pinout is as follows:

| Pin | GPIO / Use | Function | In/Out | Notes |
| --- | --- | --- | --- | --- |
| 1 | GP26 /A0 / D0 | Input 1 | In | Clock/Trigger In |
| 2 | GP27 /A1 / D1 | Input 2 | In | CV In 1 |
| 3 | GP28 /A2 / D2 | Input 3 | In | CV In 2 |
| 4 | GP29 /A3 / D3 | Input 4 | In | CV In 3 (expander) |
| 5 | GP6 / D4 | SDA 1 | Out | Display Data Line  |
| 6 | GP7 / D5 | SCL 1 | Out | Display Clock Line |
| 7 | GP0 / D6 | SCL 2 | Out | DAC Clock Line |
| 8 | GP1 / D7 | SDA 2 | Out | DAC Data Line |
| 9 | GP2 / D8 | Encoder Pin 2  | In | Encoder Input B |
| 10  | GP4 / D9 | Encoder Pin 1  | In | Encoder Input A |
| 11  | GP3 / D10 | Encoder Switch | In | Encoder Switch |
| 12  | 3.3V Out | | Out | |
| 13  | GND | MODE button | In | |
| 14  | VBUS | SHIFT button | In | |

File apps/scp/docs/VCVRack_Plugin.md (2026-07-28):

# ForgeView — RP2040 port + VCV Rack plugin

ForgeView is the Forge Series **oscilloscope / spectrum** module. It shares the
Seeed XIAO RP2040 hardware with ClockForge and is built the same way: one set of
scope logic (`lib/scope.hpp`) drives both the hardware firmware and a VCV Rack
plugin through an Arduino compatibility shim.

## Scope modes

| Mode | What it shows | Parameters |
| --- | --- | --- |
| **Dual** | Dual-trace slow scope of CV1 + CV2 | Timebase, Off1, Off2, Vert, Info |
| **Single** | Single-channel oscilloscope (CV1) | Timebase, Off1, Vert, Refresh, Info |
| **Shot** | Triggered single-shot capture of CV1 | Timebase, Trig (Off/Rising/Falling/Auto), Off1, Vert, Info |
| **Spectrum** | 128-point FFT magnitude of CV1 | HF emphasis, Noise floor, Info |
| **X-Y** | Lissajous scatter — CV1 = X, CV2 = Y | Vert, Pers (persistence Live–60s), Info |
| **Tuner** | Frequency meter (Hz + nearest note + cents) | Chan (CV1/CV2) |

The encoder navigates a **per-mode named parameter list**: rotate to move the
cursor through that mode's parameters, click to edit the highlighted row, click
again to commit. The overlay scrolls when a mode has more rows than fit. **Mode
and Trig are shown by name** (not numbers). A **long-press** of the encoder
(~800 ms) toggles **Freeze-frame** (a `HOLD` marker appears). The **Info** row
toggles engineering-unit axis labels (V/div and time/div; approximate on hardware,
derived from the measured feed interval — exact-ish in Rack where the sample rate
is known).

## Architecture

Same three-layer split as ClockForge (see that repo's
`docs/VCVRack_Plugin_Development.md` for the full rationale):

```
lib/scope.hpp   ── the scope engine: state + acquisition + render + encoder
   ▲                     (platform-independent, no hardware calls)
   │
   ├── src/main.cpp                      RP2040 firmware (dual-core)
   │      Core 0: encoder + ADC sampling + DAC pass-through
   │      Core 1: ScopeRender() + display.display()
   │
   └── vcv-plugin/src/engine/fw_engine.cpp   VCV Rack engine
          Arduino shim + per-instance context-swap (engine_state.def)
          exposes the POD API in fw_engine.hpp (namespace fvengine)
```

### Push-based acquisition (the one real adaptation)

The original SAMD21 scope *pulled* samples in a blocking `analogRead()` +
`delayMicroseconds()` loop. That cannot work under Rack's one-sample-at-a-time
`process()`. So acquisition was rearchitected to be **push-based**:
`ScopeFeedSample(ch1, ch2, clk)` is called once per input sample — per ADC read on
hardware, per audio sample in Rack — and the engine decimates / captures
internally. The timebase knob became a sample-decimation factor. This unifies both
targets and is strictly cleaner than the busy-wait original.

### `fix_fft`

Vendored into `lib/fixfft.cpp` (PROGMEM/AVR access stripped) and `#include`d from
`scope.hpp`, so the same source compiles on RP2040 and in the Rack engine with no
external dependency — mirroring how ClockForge vendors `quantizer.cpp`/`scales.cpp`.

### VCV specifics

- **Inputs**: CLK/Trigger, CV1, CV2. **Outputs**: OUT1/OUT2 = buffered pass-through
  of CV1/CV2 (oscilloscope "through"). The engine produces the display; the module
  wires the pass-through directly (no DAC shim needed).
- Engine runs at control rate (`ENGINE_DECIM = 2`, ~22 kHz acquisition); the OLED
  re-renders at ~60 Hz.
- Context menu mirrors the firmware menu (Mode / Timebase / Par2) plus host-side
  conveniences (Input CV Range, Encoder Sensitivity). Scope state persists with the
  patch via `dataToJson`/`dataFromJson`.

## Building

**Firmware** (from repo root):

```bash
pio run -e xiao_rp2040        # build; double-tap reset to flash the UF2
```

**VCV plugin** (needs the VCV Rack SDK + a GCC toolchain; on Windows, MSYS2
MinGW64):

```bash
export PATH="/c/msys64/mingw64/bin:/c/msys64/usr/bin:$PATH"
cd vcv-plugin
make RACK_DIR="<path-to>/Rack-SDK"                    # -> plugin.dll
make RACK_DIR="<path-to>/Rack-SDK" RACK_USER_DIR="<Rack2>" install
```

**Host isolation/render test** (no Rack needed):

```bash
cd vcv-plugin && test/build_isolation_test.sh
```

## Panel art

`vcv-plugin/res/ForgeView.svg` is a clean lightweight placeholder panel. If you
have the real hardware panel export, drop it in at that path (keep the widget mm
coordinates in `ForgeView.cpp` in sync with the cutouts).

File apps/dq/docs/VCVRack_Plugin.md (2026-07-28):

# NoteForge for VCV Rack

NoteForge is available as a VCV Rack plugin. It is not a reimplementation — the
plugin runs the **actual hardware firmware** inside Rack, with the OLED emulated
pixel for pixel. Everything you learn on the panel applies to the module, and
vice versa.

6HP, same panel as the hardware

## Installing

Grab the release for your platform and drop the `NoteForge` folder into your
Rack user plugins directory, or build it yourself:

```bash
cd vcv-plugin
make install
```

See [VCVRack_Plugin_Development.md](VCVRack_Plugin_Development.md) for build
requirements.

## Ports

| Jack | Direction | Meaning |
|---|---|---|
| TRIG | in | Trigger input. Rising edges fire the gate/envelope on channels set to `TRIG` or `BOTH` sync; the level is what `GATE` mode follows. |
| IN 1 | in | Pitch CV for channel 1 (0–5 V, 1V/oct). |
| IN 2 | in | Pitch CV for channel 2. |
| CV 1 | out | Quantized pitch, channel 1. |
| CV 2 | out | Quantized pitch, channel 2. |
| GATE 1 | out | Gate / envelope, channel 1. |
| GATE 2 | out | Gate / envelope, channel 2. |

## Driving the panel

- **Encoder**: drag to turn, click to select. Dragging locks the cursor, so you
  can spin as far as you like without running off the module.
- **Keyboard shortcuts** (while hovering the module):
  - `[` / `]` — one encoder detent counter-clockwise / clockwise
  - `Space` — encoder push

The screen behaves exactly as the hardware does: the keyboard page is home, the
encoder walks through the 12 keys of each channel (click toggles a note), and
continuing past them moves into the SCALES, PITCH, CH1 GATE, CH2 GATE and
SETTINGS pages.

## Context menu

Everything the on-screen menu can do is also reachable from the right-click menu,
with proper option lists instead of encoder turns. Changes made here drive the
same live firmware state, so the emulated OLED tracks them and they are saved
with the patch.

**Hardware**

- **Input CV Shift** — `0V` / `+1V` / `+2V` / `+3V`. The hardware quantizes a
  0–5 V window. Rack sequencers commonly emit bipolar pitch CV, so this *shifts*
  the input up into that window. It deliberately does **not** rescale: pitch is
  1V/oct, and squeezing ±5 V into 0–5 V would make an octave 2 V wide.
- **Encoder Sensitivity** — pixels of drag per detent.

**Input routing**

- **IN 2** — `PITCH` (default) leaves IN 2 as channel 2's pitch input. `TRANSP`
  turns it into a transposition CV, and channel 2 then quantizes IN 1 alongside
  channel 1: two voicings of the same melody, transposed together.
- **Transpose range** — `+7`, `+12`, `-7/+7`, `-12/+12`, in scale degrees.
  Transposition steps along the scale, so +2 degrees is a third in a major scale
  and a fourth in a pentatonic — always in-scale, which semitone transposition
  could not guarantee.

**Per channel** (Channel 1 / Channel 2, showing the live note at the right)

- **Notes** — the 12-note mask; this is the real source of truth for quantization.
- **Scale** / **Root** — written straight into the note mask when chosen, exactly
  as on the hardware. Hand-edit individual **Notes** afterwards if you want
  something that is not a named scale; changing the scale or root again rebuilds
  the mask and replaces those edits.
- **Pitch mode** — `TRACK` follows the input; `S&H` latches the note on a TRIG
  edge and holds it, so nothing the input does between triggers is heard.
- **Octave** — −3…+3, applied after quantization.
- **Glide** — 0–100 %, portamento between notes.
- **Settle** — 0–50 ms. How long a new note must hold before the output plays
  it, so the notes an input sweeps through on the way between two pitches are
  never heard. A genuinely slow input still plays every note. Default 5 ms.
- **Follow transpose CV** — whether this channel responds to the transposition
  input (see *Input routing* below).
- **Gate mode** — `ENV` (attack/decay), `TRIG` (fixed 10 ms pulse), `GATE`
  (follows the TRIG input level).
- **Sync** — `TRIG`, `NOTE` (fire on note change) or `BOTH`.
- **Attack** / **Decay** — 0–2000 ms / 0–4000 ms.

## Patch persistence

The module's entire EEPROM image — all 10 preset slots — is saved with the patch,
so preset slots work in Rack just as they do on hardware, and a patch reopens
with exactly the state you left.

## Differences from the hardware

- **No calibration wizard.** Rack's inputs and outputs are ideal, so there is
  nothing to trim; the module uses the nominal 0–5 V mapping and quantizes
  exactly.
- **The screen refreshes at the firmware's 20 Hz rate.** That is the hardware
  behaviour, kept deliberately.
- Multiple instances are fully independent, despite the firmware keeping its
  state in globals — see the developer reference for how.

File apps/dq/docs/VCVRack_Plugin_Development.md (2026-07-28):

# VCV Rack Plugin — Developer Reference

This document describes how the VCV Rack port of NoteForge is built. For the
user-facing feature list and shortcuts, see [VCVRack_Plugin.md](VCVRack_Plugin.md).

## Strategy: run the firmware, don't rewrite it

The plugin is **not** a reimplementation of the module. It compiles the
**unmodified hardware firmware** (`lib/`) inside VCV Rack by providing a thin
compatibility ("shim") layer that emulates the Arduino/RP2040 environment the
firmware expects. The OLED is emulated as a framebuffer, so the on-screen UI is
pixel-identical to the hardware and the entire menu + quantizer + envelope
system comes across for free. Future firmware changes to `lib/` re-port with
little or no effort.

```txt
VCV Rack  ──►  NoteForge.cpp (Module + widgets)
                     │  clean POD API (nfengine)
                     ▼
              fw_engine.cpp  ──includes──►  ../lib/*.hpp   (unchanged firmware)
                     │                          │
                     ▼                          ▼
              ForgeSeries-VCVLib/shim/ (Arduino, Wire, GFX/SSD1306, MCP4728, EEPROM)
```

The shim, the reusable `ForgeModule`/`IEngine`/widget layer and the build
fragment all live in the shared [ForgeSeries-VCVLib](https://github.com/VoltageFoundryMod/ForgeSeries-VCVLib)
repository, which ClockForge uses too. This plugin adds only the parts that are
actually specific to NoteForge.

## Repository layout (`vcv-plugin/`)

| Path | Purpose |
| --- | --- |
| `src/plugin.cpp` / `plugin.hpp` | Plugin entry point; registers `modelNoteForge`. |
| `src/NoteForge.cpp` | The Rack `Module` + widgets (display, encoder, ports) and the context menu. Includes **only** `fw_engine.hpp` — never the shim or firmware headers. |
| `src/engine/fw_engine.hpp` | Clean opaque/POD API (`namespace nfengine`). The only bridge header; exposes no Arduino/firmware types so it coexists with `rack.hpp`. |
| `src/engine/fw_engine.cpp` | VCV-adapted port of the firmware's `main.cpp`: defines the firmware globals, non-blocking versions of the integration functions, and the `nfengine` entry points. |
| `src/engine/engine_state.def` | The registry of per-instance firmware state (see below). |
| `res/NoteForge-src.svg` | Panel authoring source (real `<text>` elements). |
| `res/NoteForge.svg` | The shipped panel — generated from the source with text converted to paths. |
| `test/isolation_test.cpp` | Two-instance state isolation harness; no Rack or hardware required. |
| `../lib/` | The hardware firmware — **reused unchanged** via the `-I../lib` include path on the engine translation unit only. |

## The engine (`fw_engine`)

`fw_engine.cpp` mirrors the firmware's `main.cpp` globals and provides
non-blocking replacements for the hardware/dual-core integration functions
(`HandleOutputs`, `RedrawDisplay`, `ShowTemporaryMessage`). The `nfengine` API
it exposes:

- `createEngine` / `destroyEngine`
- `process(dt, cvVolts[2], trigGateHigh, outVolts[4])` — reads the pitch CVs,
  quantizes, renders the envelopes.
- `encoderTurn(detents)` / `encoderButton(pressed)` — UI.
- `getFramebuffer(out[1024])` — current screen.
- `serialize` / `deserialize` — the EEPROM blob, for patch persistence.
- A curated parameter bridge (scales, roots, note masks, octave, glide, gate
  mode, sync, attack/decay) backing the Rack context menu.

## Module & UI (`NoteForge.cpp`)

- Runs the engine at **control rate** (`engineDecim = 8` samples ≈ 5.5 kHz at
  44.1 kHz). Outputs are held between updates.
- `forgevcv::FramebufferDisplay` blits the firmware framebuffer as a cached
  128×64 texture sampled `NVG_IMAGE_NEAREST` for crisp pixels at any zoom.
- `forgevcv::EncoderKnob` — drag to rotate (relative detents via `cursorLock`),
  click to push. UI events reach `process()` through `std::atomic` counters.
- Persistence: the EEPROM blob is stored as a JSON int array via
  `ForgeModule::baseToJson` / `baseFromJson`.

### Input CV handling: shift, never scale

`forgevcv::ForgeModule` offers a `cvRange` remap that linearly rescales a
bipolar input onto the firmware's 0–5V domain. **NoteForge deliberately does not
use it.** Pitch CV is 1V/oct: rescaling −5…+5V onto 0…5V would halve
volts-per-octave and an octave would stop being an octave.

Instead the module exposes an **Input CV Shift** (0V / +1V / +2V / +3V) that
*offsets* the incoming voltage into the hardware's window, leaving
volts-per-octave untouched. A sequencer putting out −2…+3V works correctly with
a +2V shift. `cvRange` is still serialized by the base class; it is simply
unused here.

## Time model

Engine time (`g_engineMicros`, backing `millis()`/`micros()`) advances by
`process()`'s `dt` — **not** wall-clock. This is deterministic and stays correct
when Rack renders faster than real time. The firmware's 20 Hz display
rate-limiter, envelope timing and glide all depend on it.

> If you write a headless harness and the screen never changes, this is why: the
> display rate-limiter needs engine time to advance, so call `process()` between
> `getFramebuffer()` calls.

## I/O mapping

- **CV in**: input volts (after the shift) → 0–4095 ADC (0–5 V range, matching hardware).
- **Outputs**: 0–4095 DAC → 0–5 V.
- **DAC channel swap**: hardware swaps DAC B/C; the shim undoes it
  (`hwToOut = {0,2,1,3}`) so outputs map 1:1 to jacks 1–4.
- Jack order is CV 1, CV 2, GATE 1, GATE 2.
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

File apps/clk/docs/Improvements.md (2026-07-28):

Features:

- [ ] Implement internal modulators for parameters
- [x] Add an operation to invert the output signal for each channel

Project Improvements:

- [x] Better resolution to generate cleaner waveforms
- [x] Better detection of input clock with different PPQNs (dividers)
- [x] Update menus to be able to change settings to all 4 outputs and not the previous outputs 3 and 4 which had DAC.
- [x] Add outputs 1 and 2 to the CV target options in the menu
- [x] Add outputs 1 and 2 to the quantization options in the menu
- [x] Timeout to main screen off or set seconds
- [ ] Organize code to find the defines and configurations easier also centralize default configs
- [x] Make the screen output indicators follow the outputs with probability, euclidean and things that affect it
- [x] Probability doesn't affect outputs with envelopes
- [x] CV 1/CV 2 passthrough: Probability and Euclidean are inert (value always passes through and the blink indicator follows the flowing CV instead of blinking "off")
- [x] Guard so the CV "Output X Div" target (and divider menu) can't move an envelope output off the "Env" divider slot
- [x] Improve user manual and documentation
- [x] Check the slight clipping in the outputs... could be adjustment but also firmware calibration issue
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

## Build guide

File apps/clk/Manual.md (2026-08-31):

# ClockForge 2: Crafting Time, One Pulse at a Time



## Overview

ClockForge provides clock signals and waveforms for synchronizing and modulating other modules in your Eurorack system. It features a global BPM control, multiple clock outputs, adjustable clock multiplication and division per output, tap tempo functionality, sync to external clock sources, Euclidean rhythm generation, CV Input modulation matrix and custom swing patterns per output.

Part of the **Forge** series of modules which share a single hardware platform. The new ClockForge 2 is an updated version with a more powerful microcontroller and 4 outputs that can generate clocks, waveforms and envelopes.

Most parts of this manual applies to both Hardware and VCV Rack plugin with exceptions to hardware specific features like calibration, powering and firmware update. The VCV Rack plugin is a full software emulation of the hardware module and can be used to test the module without having the physical hardware.

The hardware schematics and design files are completely open-source and available in the [GitHub repository](https://github.com/VoltageFoundryMod/ForgeSeries-Hardware).

ClockForge 2 Module

Check the module on [ModularGrid](https://modulargrid.net/e/voltage-foundry-modular-clockforge).

## Features

- **Global BPM Control**: Set the global BPM for all outputs.
- **Multiple Clock Outputs**: Four clock outputs with individual settings.
- **Adjustable Clock Multiplication and Division**: Configure each output to multiply or divide the global BPM.
- **Output Waveform Generation**: Outputs can generate different waveforms for modulation.
- **Pulse Probability**: Set the probability of a pulse occurring.
- **Euclidean Rhythm Generation**: Generate complex rhythms using Euclidean algorithm.
- **Custom Swing Patterns**: Apply swing to each output individually.
- **Sync to External Clock Sources**: Automatically adjust BPM based on an external clock signal with adjustable clock divider.
- **Phase Shift**: Adjust the phase of the output in relation to the master clock.
- **Waveform Duty Cycle and Level/Offset**: Adjust the pulse width and level/offset of the clock signal.
- **External modulation**: Many parameters can be modulated by the CV inputs by assigning CV targets.
- **Tap Tempo Functionality**: Manually set the BPM by tapping a button.
- **Quantization**: Quantize the output wave or CV input to some scale and root note.
- **Envelopes**: Outputs can generate different types of envelopes (AD, AR, ADSR) triggered by CV inputs.
- **Cross Operations**: Modulate an output with another output or CV input using arithmetic, logic and sample/hold operations.
- **Loops**: Rewind an output's pattern every few beats to build repeating, structured random/Euclidean phrases, with nap/wake muting.
- **Save/Load Configuration**: Save and load up to 10 configurations.
- **Expandable**: An optional [expander](#expander) adds four more outputs and a
  third CV input, with the same per-output settings as the built-in four.

The module has a user-friendly interface with an encoder for navigation and parameter adjustment, and a clear display showing the current settings and status of each output. The main screen shows the BPM and the status of each output, while navigating into each output's settings allows for detailed configuration of that specific output. There are no submenus as all parameters are accessible by scrolling horizontally on the same menu screen.

The right side of the screen shows a navigation line to indicate the current position of the cursor in the menu. The navigation is not shown in the main (BPM) screen.

Whenever a parameter is changed, a small circle will be shown in the top-left corner of the screen. This indicates that the current settings were modified and not saved. The module always loads the preset saved in slot 0 on boot.

The current hardware design supports input signals from 0 to 5V, and the outputs are also 0-5V. The VCV Rack plugin module can be set to accept CV signals in the range of 0 to 5V like the hardware, -5 to +5V or 0 to 10V for more flexibility. The hardware might support other input/output ranges in the future but for now, voltages higher than 5V will be clipped and voltages lower than 0V will be ignored.

---

## User Manual

- [ClockForge 2: Crafting Time, One Pulse at a Time](#clockforge-2-crafting-time-one-pulse-at-a-time)
  - [Overview](#overview)
  - [Features](#features)
  - [User Manual](#user-manual)
    - [Global Parameters](#global-parameters)
    - [Output Parameters](#output-parameters)
  - [Operation](#operation)
    - [Interface](#interface)
    - [Setting the BPM](#setting-the-bpm)
    - [Global Play/Stop](#global-playstop)
    - [Output clock division/multiplication](#output-clock-divisionmultiplication)
    - [Output Waveform](#output-waveform)
    - [Output Level and Offset](#output-level-and-offset)
    - [Output Enable/Disable and Invert](#output-enabledisable-and-invert)
    - [Pulse Probability](#pulse-probability)
    - [Euclidean Rhythm Configuration](#euclidean-rhythm-configuration)
    - [Swing Configuration](#swing-configuration)
    - [Output Phase Shift](#output-phase-shift)
    - [Duty Cycle (pulse width)](#duty-cycle-pulse-width)
    - [Envelopes](#envelopes)
    - [CV Input Modulation](#cv-input-modulation)
    - [Cross Operations](#cross-operations)
    - [Loops](#loops)
    - [Quantization](#quantization)
    - [Misc Settings](#misc-settings)
      - [Tap Tempo](#tap-tempo)
      - [Main screen timeout](#main-screen-timeout)
      - [Boot menu](#boot-menu)
    - [Save/Load Configuration](#saveload-configuration)
    - [External Clock Sync](#external-clock-sync)
  - [Expander](#expander)
    - [Enabling the expander](#enabling-the-expander)
    - [What it adds](#what-it-adds)
    - [After fitting one](#after-fitting-one)
    - [In VCV Rack](#in-vcv-rack)
    - [Notes](#notes)
  - [VCV Rack Plugin](#vcv-rack-plugin)
  - [Hardware Calibration](#hardware-calibration)
    - [What you need](#what-you-need)
    - [Running calibration](#running-calibration)
  - [Firmware Update](#firmware-update)
  - [Troubleshooting](#troubleshooting)
  - [Powering](#powering)
  - [Specifications](#specifications)
  - [Contact](#contact)
  - [Acknowledgements](#acknowledgements)
  - [License](#license)

### Global Parameters

- **BPM**: Beats per minute, adjustable from 10 to 300.
- **Master Stop**: Stop or resume all outputs.

The small squares on the main screen show the status of each output. If the square is filled, the output is active. If the square is empty, the output is stopped.

### Output Parameters

Each of the four outputs can be individually configured with the following parameters:

- **Divider/Multiplier**: Set the clock multiplication or division ratio.
- **Output State**: Enable or disable the specific output.
- **Invert**: Invert the output polarity (5V - value).
- **Pulse Probability**: Probability of a pulse occurring.
- **Euclidean Enabled**: Enable or disable Euclidean rhythm generation.
- **Euclidean Steps**: Number of steps in the Euclidean pattern.
- **Euclidean Triggers**: Number of triggers in the Euclidean pattern.
- **Euclidean Rotation**: Rotate the Euclidean pattern.
- **Euclidean Pad**: Add empty steps to the end of the Euclidean pattern.
- **Swing Amount**: Adjust the swing amount for the output.
- **Swing Every**: Set the pulse interval for applying swing.
- **Phase Shift**: Adjust the phase of the output in relation to the master clock.
- **Duty Cycle**: Adjust the pulse width of the clock signal.
- **Level**: Set the output voltage level.
- **Offset**: Set the output voltage offset.
- **Waveform**: Select the waveform for outputs.
- **Quantization**: Quantize the output to a specific scale and root note.
- **Cross Operation**: Combine this output's value with another output or CV input using a selected operation.
- **Loop**: Rewind this output's pattern every N beats, with optional nap/wake muting.

## Operation

### Interface

On it's main page, the module shows the current BPM and the status of each output. The small squares on the main screen show the status of each output. If the square is filled, the output is active. If the square is empty, the output is stopped.

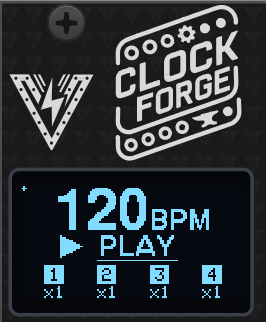
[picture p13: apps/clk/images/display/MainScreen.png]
Main Screen


- CLK In: Optional CV Clock input (0-5V)
- IN1, IN2: CV input to control internal parameters via matrix (0-5V)
- OUT 1 / 2 / 3 / 4: Outputs which are waveform capable (0-5V)

### Setting the BPM

1. Use the encoder to navigate to the BPM setting.
2. Push the encoder to enter edit mode.
3. Rotate the encoder to adjust the BPM value.
4. Press the encoder to exit edit mode.

### Global Play/Stop

With the **PLAY** or **STOP** word underlined, press the encoder button to stop or resume all outputs. The individual outputs can still be stopped or resumed individually and will remain in the last state set.

### Output clock division/multiplication

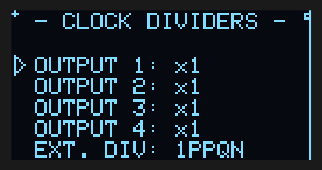
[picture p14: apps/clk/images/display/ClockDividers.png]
clock dividers


Outputs can be configured to multiply or divide the master clock. The default value is 1x which means the output will be in sync with the master clock. The outputs can be multiplied up to 64x or divided down to /128 with some triplets and dotted notes in between in the "1.5" and "3" division and multiplier values.

1. Navigate to the selected output.
2. Click the encoder to enter edit mode.
3. Use the encoder to select the desired divider value.
4. Click the encoder to exit edit mode.

### Output Waveform

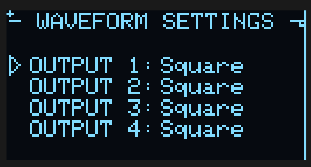
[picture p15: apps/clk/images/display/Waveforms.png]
waveforms


Outputs can be configured to multiple waveforms and envelopes.

They support the following:

- **Square**: A square wave with adjustable duty cycle, level and offset.
- **Triangle**: A triangle wave with adjustable duty cycle, level and offset.
- **Sawtooth**: A sawtooth wave with adjustable duty cycle, level and offset.
- **Sine**: A sine wave with adjustable duty cycle, level and offset.
- **Parabolic**: A parabolic wave with adjustable duty cycle, level and offset.
- **Logarithm Envelope**: A logarithm envelope curve (starts at 0% rising to 100%) with adjustable level and offset. Triggered by clock pulses.
- **Exponential Envelope**: An exponential envelope curve (starts at 0% rising to 100%) with adjustable level and offset. Triggered by clock pulses.
- **Inverted Logarithm Envelope**: An inverted logarithm envelope curve (starts at 100% decaying to 0) with adjustable level and offset. Triggered by clock pulses.
- **Inverted Exponential Envelope**: An inverted exponential envelope curve (starts at 100% decaying to 0) with adjustable level and offset. Triggered by clock pulses.
- **Hatchet x2**: Generates 2 square pulses in one up clock cycle. The pulse width can be adjusted by the duty cycle parameter. Level and offset can also be adjusted.
- **Hatchet x4**: Generates 4 square pulses in one up clock cycle. The pulse width can be adjusted by the duty cycle parameter. Level and offset can also be adjusted.
- **Noise**: A random signal with adjustable level and offset. Continuous.
- **Smooth Noise**: A smooth random signal with adjustable level and offset. Continuous.
- **Sample & Hold**: A sample and hold signal based on noise with adjustable level and offset. Triggered by clock pulses.
- **AD Envelope**: An Attack-Decay envelope (no sustain while gate is held) with adjustable level and offset. Triggered by a CV input.
- **AR Envelope**: An Attack-Release envelope (sustain is held at max level while gate is on) with adjustable level and offset. Triggered by a CV input.
- **ADSR** Envelope: An Attack-Decay-Sustain-Release envelope with adjustable level and offset. Triggered by a CV input.
- **Play**: The output will be true (high) when the master clock is running and false (low) when the master clock is stopped. This is useful for triggering other modules based on the master clock.
- **Reset**: The output will trigger (high) when the master clock starts running. This is useful for resetting other modules based on the master clock.
- **CV 1** / **CV 2**: The output mirrors CV input 1 or 2 respectively (a buffered copy of the input voltage). Enable Quantize on the output to snap that CV to the selected scale and root note — handy for pitch-quantizing an external sequencer or random source. No CV target assignment is needed.

1. Navigate to the selected output item. Click the encoder to enter edit mode.
2. Use the encoder to select the desired waveform. The waveform will be updated in real-time.
3. Click the encoder to exit edit mode.

### Output Level and Offset

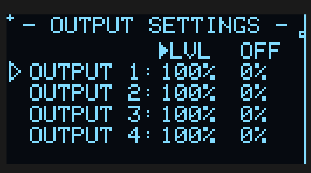
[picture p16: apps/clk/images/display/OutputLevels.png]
output level


Allows setting the output level and offset which ranges from 0 to 100% corresponding to 0 to 5V.

1. Navigate to the selected output. Click the encoder to enter edit mode.
2. Use the encoder to select the desired output level from 0 to 100% which corresponds to 0 to 5V.
3. Click the encoder to exit edit mode.

### Output Enable/Disable and Invert

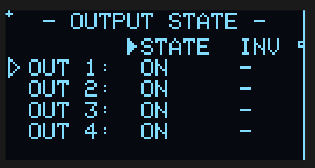
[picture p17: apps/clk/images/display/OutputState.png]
output state


The Output State page has two columns per output: **STATE** and **INV**.

Outputs can be stopped individually (STATE). When stopped, the output will not generate any pulses. When master stop is activated, all outputs will be stopped and when master play is resumed, any stopped output will be kept stopped.

The **INV** column inverts the output polarity (the final voltage becomes 5V − value), so a rising ramp becomes falling, and a high gate becomes low. This is applied at the very last stage, after cross-operations and quantization. (Note: inverting a quantized pitch mirrors it around mid-scale rather than transposing it, so invert is mainly useful for gates, triggers and modulation shapes.)

1. Navigate to the output state menu page.
2. Use the encoder to move between the STATE and INV columns for each output (the arrow indicates the active column).
3. Click the encoder to toggle the selected output's state (ON/OFF) or invert (Inv/-).

### Pulse Probability

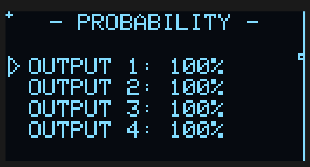
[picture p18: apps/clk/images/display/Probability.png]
probability


This is the percentage of probability that a pulse will be generated on the output. This is useful for creating random patterns or adding some variation to the output.

1. Navigate to the probability menu page.
2. Click the encoder to enter edit mode on the selected output.
3. Use the encoder to select the desired pulse probability in percentage.
4. Click the encoder to exit edit mode.

### Euclidean Rhythm Configuration

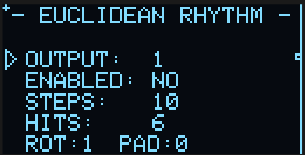
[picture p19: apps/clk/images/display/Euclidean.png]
euclidean


Euclidean rhythms are generated by an algorithm that takes a number of steps, a number of triggers (HITS — the active steps) and a rotation (ROT) of the pattern, then spaces the hits as equidistant from each other as possible. See <https://en.wikipedia.org/wiki/Euclidean_rhythm> for more info.

Additional empty steps can be added to the end of the pattern using the pad (PAD) parameter. This is useful for creating more complex rhythms.

1. Navigate to the euclidean rhythm menu page.
2. Select the output item and click the encoder to select the output to be edited. Click the encoder again to exit the output selection.
3. First setting enables or disables the Euclidean rhythm generation by clicking the encoder.
4. Select the Steps, Triggers and Rotation parameters, click the encoder to edit the values.
5. The pattern will be updated in real-time and displayed on the right of the screen. Euclidean rhythm allows up to 64 steps but only the first 47 are displayed. Rhythm steps are shown in columns, top to bottom, left to right.

The euclidean rhythm pulse is affected by the pulse probability setting.

### Swing Configuration

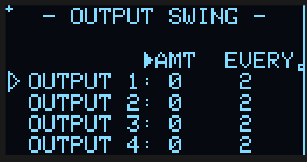
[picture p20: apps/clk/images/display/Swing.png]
swing


The outputs can have a swing pattern applied to them. The swing amount is in 1/96th of a note based on current BPM and the swing every is the interval between applying the swing. The swing amount can be set from 2/96th to 12/96th delay and the swing every from 1 to 16 pulses.

1. Navigate to the selected output. The first parameter to be edited is the swing amount.
2. Click the encoder to enter edit mode.
3. Use the encoder to select the desired swing amount.
4. Click the encoder to exit edit mode.
5. Navigate to the selected output, the second parameter to be edited is the swing every.
6. Click the encoder to enter edit mode.
7. Use the encoder to select the desired swing every value.
8. Click the encoder to exit edit mode.

### Output Phase Shift

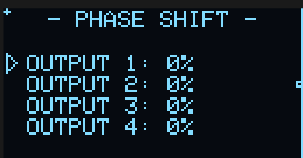
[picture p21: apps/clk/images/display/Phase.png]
phase


Outputs can have their phase adjusted in percentage in relation to the master pulse. This allows for phase shifting the output in relation to the master clock. The default value is 0% which means the output is in phase with the master clock.
An adjustment of 50% will shift the output by half a pulse width, which means this output will hit on the upbeats of the master clock (or of an output with a 0% phase shift).

Just be careful with phase wraps as shifting an output phase by more than 50% with a duty-cycle bigger than 50% can lead to unexpected triggers.

### Duty Cycle (pulse width)

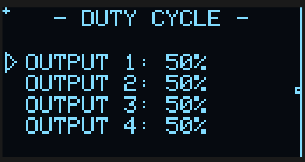
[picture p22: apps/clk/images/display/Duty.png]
duty


Duty cycle or width is the percentage of the pulse that remains high or low. The default value is 50% which means the pulse high cycle has the same length as the low cycle. The duty cycle can be set from 1 to 99% where 1% will generate a very short pulse and 99% a very long high pulse.

The non-square waveforms can also have their shape modified by the duty cycle parameter. For example, a 50% duty cycle (default) in the triangle wave output will generate a perfect triangle wave, setting the duty cycle to 1% will generate a sawtooth wave and setting it to 99% will generate an inverted sawtooth wave. The duty cycle also affects the envelopes by shortening or lengthening the decay time during the pulse.

1. Select the duty cycle parameter for the desired output. Click the encoder to enter edit mode.
2. Use the encoder to select the desired duty cycle value from 1 to 99%.
3. Click the encoder to exit edit mode.

### Envelopes

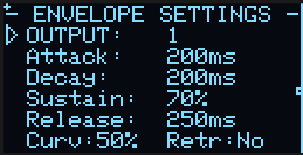
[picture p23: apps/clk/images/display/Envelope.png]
envelope


The module supports envelope generators based on input CV triggers. Refer to the Output Waveform section for more information on setting the envelope types.

The AD, AR and ADSR envelopes can only be generated by using triggers/gates on the CV inputs. They can have configurable curves between logarithmic, linear and exponential and also allow retriggering while the envelope is still active. The other waveforms (square, sine, Exp Env, Log Env and its inverted modes, etc) cannot be triggered by CV inputs.

To set an envelope generation, follow these steps:

1. Go to the waveform selection and choose between "AD Env", "AR Env" or "ADSR Env".
2. Go to CV Input target configuration, select which CV input will receive the gate/trigger and assign it to the Output X Env parameter.

Tip: You can have up to 2 envelopes running at the same time, as there are only 2 CV inputs that can be assigned as triggers. Each output can have its own parameters like envelope type, levels, offsets, curves and retriggering settings.

Adjust the envelope parameters like Attack, Decay and Release times, Sustain level, curve percentage and retriggering to your needs.

### CV Input Modulation

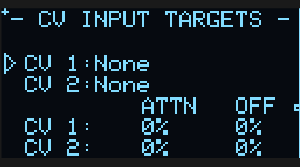
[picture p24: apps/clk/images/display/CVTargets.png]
cv input targets


Many parameters can be modulated by the CV inputs. The CV inputs are 0-5V and can be used on the modulation matrix to control the parameters below (X is the output number, 1-4, or 1-8 with an [expander](#expander) fitted):

- **Start/Stop**: Start or stop all outputs with a gate/CV signal (high = play, low = stop).
- **Reset**: Reset the clock on a rising edge.
- **BPM**: Modulate the global BPM with a CV signal.
- **Output X Div**: Modulate the clock division/multiplication for output X.
- **Output X Prob**: Modulate the probability of a pulse occurring on output X.
- **Swing X Amount**: Modulate the swing amount for output X.
- **Swing X Every**: Modulate the pulse interval for applying swing on output X.
- **Output X Level**: Modulate the output voltage level for output X.
- **Output X Offset**: Modulate the output voltage offset for output X.
- **Output X Waveform**: Select the waveform for output X based on the input CV Value.
- **Output X Duty Cycle**: Modulate the duty cycle of the output X.
- **Output X Envelope**: Trigger the envelope generation for the output X by sending a gate/trigger signal to the assigned CV input.

> To route a CV input straight to an output (e.g. to quantize an external CV), no target assignment is needed — set that output's waveform to "CV 1", "CV 2" or "CV 3" instead (see [Quantization](#quantization)).

Each input can be assigned to one of the parameters above, and each has its own
attenuation and offset. These live on two pages: **CV INPUT TARGETS** for the
assignments, and **CV ATTEN / OFFSET** for the trims.

1. On **CV INPUT TARGETS**, navigate to the CV input you want to assign.
2. Click the encoder to enter edit mode.
3. Use the encoder to select the desired parameter to be modulated.
4. Click the encoder to exit edit mode.
5. Optionally, scroll on to **CV ATTEN / OFFSET** and set the attenuation and
   offset for that input in the same way. The arrow at the top of the page shows
   which of the two columns the encoder is editing.

The CV target is only applied to the selected parameter when the user exits edit mode. This way, a CV connected to an input does not change the scrolled parameters while the user is selecting the target.

### Cross Operations

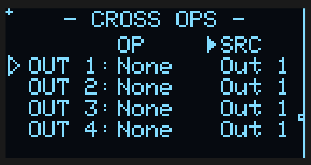
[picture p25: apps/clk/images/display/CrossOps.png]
cross operations


Cross operations allow the value of an output to be influenced by another signal (a _source_) through a selected operation. This can be as simple as mixing two outputs together, a logic gate, or something more involved like sample-and-hold or reseeding randomness. It greatly extends the basic logic operations found on similar modules.

The **Cross Ops** menu page has one row per output with two columns:

- **OP**: the operation to apply (set to anything other than "None" to activate).
- **SRC**: the source signal — another output (`Out 1`–`Out 4`) or a CV input (`IN 1`, `IN 2`).

When a source is another output, its value is taken **before** that output's own cross operation is applied, so two outputs can cross-modulate each other without feedback and the result is independent of output order. Cross operations are applied **before** quantization, so you can, for example, mix two pitches and then quantize the result.

1. Navigate to the Cross Ops page and the desired output row.
2. Click the encoder to edit the **OP** column and select an operation.
3. Move to the **SRC** column, click to edit, and select the source output or CV input.
4. Click the encoder to exit edit mode.

The available operations are:

- **None**: Cross operation disabled (output is unaffected).
- **MIX**: Average of the output and source values.
- **MULT**: Multiplies the two values (ring-mod style).
- **ADD**: Adds the two values, clipping any overflow.
- **SUB**: Subtracts the source from the output, clipping at zero.
- **MIN**: The lower of the two values.
- **MAX**: The higher of the two values.
- **HOLD**: While the source is high, the output value is frozen at its last value.
- **S&H**: A rising edge on the source samples the current output value and holds it until the next rising edge.
- **MASK**: When the source is zero, the output is forced to zero; otherwise it passes through.
- **NOT**: When the source is high, the output is forced to zero (inverse of MASK).
- **OR** / **XOR** / **AND**: Boolean logic of the two values, outputting either zero or full scale (like CMOS logic gates).
- **BitOR** / **BitXOR** / **BitAND**: Bitwise logic across all bits of the two values, for more complex stepped results.
- **SEED**: A rising edge on the source rewinds this output's random generator, replaying the same random sequence from the start (useful for "Krell"-style patches). The value passes through unchanged.

Logic operations treat a value above half scale as "high". The HOLD, MASK, NOT, S&H and SEED operations treat any value meaningfully above zero as "high/triggered".

### Loops

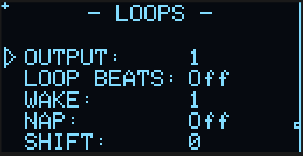
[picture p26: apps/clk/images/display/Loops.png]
loops


Loops turn free-running or random patterns into repeating, musically structured phrases by periodically rewinding an output. A loop length is specified in **beats** (quarter notes, not steps), and at each loop boundary the output's pattern generators — random values, probability decisions and the Euclidean step position — are rewound to their start, so the pattern repeats identically.

This is especially useful for random waveforms (Noise, Smooth Noise, S&H) and probability or Euclidean patterns: with a loop set, an otherwise endless random sequence becomes a locked, repeating groove aligned to the bar.

When a loop is active, the **Nap/Wake** parameters add a higher-level on/off arrangement counted in whole loops:

- **Loop Beats**: Loop length in beats. `Off` disables loops; otherwise 1–64 beats.
- **Wake**: Number of complete loops to play (output active) before napping.
- **Nap**: Number of complete loops to mute the output. `Off` (0) means the output never naps and just repeats.
- **Shift**: Offsets the start of the nap/wake cycle by a number of complete loops, so different outputs can stagger their drop-outs against each other.

For example, with Loop Beats = 4, Wake = 2 and Nap = 1, the output plays the same 8-beat phrase (two 4-beat loops), then goes silent for 4 beats, then repeats. While napping the output is muted (0 V) but its timing keeps running, so it resumes in phase.

1. Navigate to the **Loops** menu page.
2. Select the **OUTPUT** item and click the encoder to choose the output to edit. Click again to exit the output selection.
3. Set **LOOP BEATS** to the desired loop length (or `Off` to disable).
4. Optionally set **WAKE**, **NAP** and **SHIFT** to build the mute pattern.
5. Click the encoder to exit edit mode.

### Quantization

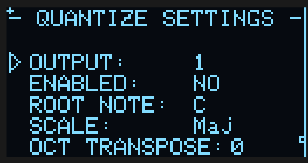
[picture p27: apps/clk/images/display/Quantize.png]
quantize


The module supports quantization of the output to a specific scale and root note. The quantization can be applied to the output waveform or to the CV input.

The Quantize Settings menu allows you to enable/disable quantization for the selected output, choose the root note, scale to be used and octave transpose with 3 octave levels higher or lower.

To use quantization on the generated output, first select the output waveform type (sine, S&H, etc) and then enable the quantization on Quantize menu. Select the root note and scale to be used. The quantization will be applied to the output waveform.

It's also possible to quantize an input CV signal to a specific scale and root note. This is useful for using CV values generated by external modules (e.g. a sequencer or random source) to drive pitch. To do this, select the **"CV 1"** or **"CV 2"** waveform type for the output — this mirrors the corresponding CV input jack to that output. Then enable quantization in the Quantize menu and pick the root note and scale.

Eg. to quantize CV input 1 on output 3: set output 3's waveform to "CV 1", then enable Quantize on output 3 and choose the scale/root note. The CV input is copied to the output and snapped to the selected scale — no CV Input Target assignment is needed.

With quantization disabled, the "CV 1"/"CV 2" waveform simply passes the CV input through to the output (a buffered copy), which can be used as a CV mult/buffer.

### Misc Settings

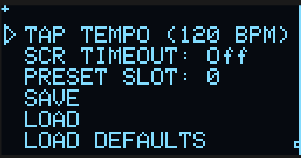
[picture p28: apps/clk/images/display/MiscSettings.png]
misc settings


#### Tap Tempo

In addition to setting the BPM manually, the module can be set to the desired BPM by clicking the encoder. The module will calculate the BPM based on the interval between taps.

1. Select the tap tempo parameter.
2. Press the encoder button at least 3 times to set the BPM based on the interval between taps. If more than 3 taps are entered, the average time between the last 3 is used. BPM is updated in real-time.

#### Main screen timeout

The module can be set to return to the main screen (the one showing the BPM and the output boxes) after a certain amount of seconds of inactivity when not editing a parameter. When a parameter is being changed (selected), the timeout doesn't apply. This can be configured in the "Screen Timeout" menu where the options are Off, 2s, 5s, 10s and 20s.

#### Boot menu

"BOOT MENU" hands the hardware back to the module selector, so you can run a different Forge module — or the [calibration wizard](#hardware-calibration) — without power-cycling. ClockForge flushes anything it owes to flash first, then the module reboots into the selector. Holding the encoder for two seconds does the same thing from anywhere in the menu.

### Save/Load Configuration

The module has 10 memory slots (0–9) to save and load configuration. The parameters saved into slot 0 are automatically loaded on boot.

1. Navigate to the PRESET SLOT parameter on the PRESETS page.
2. Click the encoder to enter the desired slot selection.
3. Click to exit the slot selection.
4. Select SAVE and click the encoder to save the current slot configuration.
5. Select LOAD and click the encoder to load the selected slot configuration.

The "LOAD DEFAULTS" option will load the default configuration to current parameters but will not save it. To save the default configuration, navigate to the save configuration parameter and save it to the selected preset slot.

### External Clock Sync

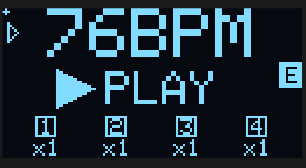
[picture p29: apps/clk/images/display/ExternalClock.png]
external clock


1. Connect an external clock signal to the **CLK IN** input.
2. The module will automatically adjust the BPM to match the external clock. A small "E" will be displayed on the screen next to BPM when the external clock is detected.
3. When the external clock is disconnected, the module will revert to the last used internal BPM.

If the external clock is faster than needed (for example running at higher PPQN), it's possible to apply an external clock divider (from no division to 48PPQN) to the input signal in the Clock Divider section.

The module works with external clocks from 30 to 300 BPM. Due to timer resolution, using very slow external clocks with high multipliers may lead to jitter on the outputs.

## Expander

**Expander 1** is a 4 HP companion module that adds four more outputs (**OUT 5** to
**OUT 8**) and one more CV input (**IN 4**). It connects to the expansion header on
the back of the module with a ribbon cable, and draws its power from there.

### Enabling the expander

Go to **SETTINGS → EXPANDER** and select **Exp 1**. The setting is stored with the
preset, so a saved patch remembers whether it expects an expander.

Left on **None**, the extra menu pages are not shown at all and outputs 5-8 stay
silent — which is also what happens if the ribbon comes loose.

### What it adds

Outputs 5-8 are not a reduced set: they are the same as outputs 1-4 in every
respect, with the same clock dividers, waveforms, levels, envelopes, Euclidean
patterns, swing, probability, loops, quantization and cross-operations.

- Eight new menu pages appear after **CROSS OPS**, mirroring the pages for
  outputs 1-4: dividers, waveform, level/offset, state and invert, probability,
  swing, phase/duty, and cross-operations — each covering outputs 5 to 8.
- The pages that work one output at a time (**Euclidean**, **Loops**,
  **Envelopes**, **Quantize**) simply extend their **OUTPUT** selector to 1-8.
- **IN 4** becomes a third CV input, listed as **CV 3**. It can be assigned a
  modulation target like CV 1 and CV 2, used as a cross-operation source, and
  mirrored straight to an output with the **CV 3** waveform.

### After fitting one

Re-run the calibration wizard (see [Hardware Calibration](#hardware-calibration)).
The expander has its own output trimmers and its own input stage, so it needs its
own measurements — the wizard detects it automatically and grows from six steps
to eight.

### In VCV Rack

The expander is a separate module in the browser. Place it on either side of
ClockForge and they connect automatically; the right-click menu's **Add
Expander 1** adds it and switches the setting on in one go.

### Notes

- The main screen still shows four output indicators, for the module's own jacks.
- Outputs 5-8 are updated one I2C frame after outputs 1-4, a fixed offset of
  roughly 200 microseconds. Both banks are calculated in the same pass, so this
  is a constant delay rather than jitter, and it is far below anything audible at
  the rates these outputs run.

## VCV Rack Plugin

The VCV Rack plugin is a full software emulation of the hardware module and can be used to test the module without having the physical hardware. The plugin saves and loads the configuration in the same way as the hardware module internally without the use of VCV Rack presets.

Some features of the VCV Rack module are exclusive to the plugin and not available on the hardware module. These include:

- Setting the input CV range to 0-5V or 0-10V or -5V to +5V. The hardware module only supports 0-5V.
- Setting the Encoder sensitivity.

## Hardware Calibration

The module ships with sensible default values, but for best precision — especially when using quantization or 1V/oct pitch CV — you should run the hardware calibration wizard once after building or assembling the module.

Calibration covers two things:

**Output trim**: the output op-amp gain is set with on-board trimmers so every output jack delivers exactly 5.00 V at full scale. This is purely a hardware adjustment — there is no software output scaling.
**CV input calibration**: each CV input is measured at two known reference voltages (1 V and 3 V) to build a per-channel linear correction (`mv = scale × reading + offset`) that compensates for resistor tolerances and ADC offset. This is done with external references and is independent of the module's own outputs, so any output-trim error does not propagate into the input calibration.

Calibration data is stored in a dedicated area of non-volatile memory **separate from presets**, so it survives firmware updates and preset load/save operations.

### What you need

- A multimeter capable of measuring DC voltage to at least two decimal places (for the output trim).
- A stable, known **1 V** and **3 V** source for the CV inputs — for example a precision voltage reference, a bench power supply, or a calibrated sequencer/quantizer output — and a patch cable to connect it.

### Running calibration

The wizard has 6 steps: an output trim, an output offset measurement, then four
CV input captures (1 V and 3 V on each of the two inputs).

With an [expander](#expander) fitted it becomes 8 steps — the extra two are the
1 V and 3 V captures for **IN 4** — and the trim and offset steps cover all eight
output jacks. The wizard detects the expander itself; there is nothing to select.

1. Power on the module **from your Eurorack supply** while **holding the encoder button** pressed, which opens the module selector. Release the button, scroll to **CALIBRATE** at the bottom of the list and click. (From a running module you can get to the same screen with **SETTINGS → BOOT MENU**, or by holding the encoder for two seconds.) Click the encoder at the welcome screen to start.

   Calibration belongs to the board, not to any one module: one run covers every module in the firmware, and the wizard reboots back to the selector when it is done.

   > ⚠️ Calibrate on Eurorack power, **not** the MCU's USB port — USB cannot drive the outputs to full scale, so the trim would be wrong. **Never connect Eurorack power and USB at the same time, as this could damage the module.**

2. **Step 1 — Output trim** (`1/6  OUTPUT TRIM`):
   Every output is driven to full scale. Using a multimeter set to DC voltage, probe each output jack in turn and adjust its corresponding trimmer potentiometer on the PCB until the reading is exactly **5.00 V**. When they all read 5.00 V, press the encoder to continue.

3. **Step 2 — Output offset** (`2/6  OUT 1 OFFSET` … ):
   Each output is driven to the code that should give exactly 1.000 V. Measure the
   jack and dial the reading you actually get into the display, then click to move
   to the next output. Together with the full-scale trim above, this pins down the
   op-amp's offset — the part a trimmer alone cannot remove.

4. **Steps 3–6 — CV input capture** (`3/6` … `6/6`):
   The display asks for a specific reference voltage on a specific input, in turn:
   - `3/6  CV1 INPUT 1V` — apply **1 V** to CV input 1
   - `4/6  CV1 INPUT 3V` — apply **3 V** to CV input 1
   - `5/6  CV2 INPUT 1V` — apply **1 V** to CV input 2
   - `6/6  CV2 INPUT 3V` — apply **3 V** to CV input 2

   With an expander fitted every step number reads `/8` rather than `/6`, and two
   more follow — `7/8  CV3 INPUT 1V` and `8/8  CV3 INPUT 3V` — for **IN 4**.

   For each step, apply the requested voltage to the named input. The screen shows a live voltage reading so you can confirm the signal is stable; when it is steady, press the encoder to capture (256 ADC samples are averaged).

5. **Review and save**:
   The display shows the derived per-channel scale and offset for a sanity check. Press the encoder to **save and reboot**. The module restarts with calibration applied.

> **Tip:** Calibration only needs to be run once. Re-run it if you replace any resistors or trimmers on the board, or if CV tracking feels off after assembly.

## Firmware Update

1. Download the latest firmware from the Releases section of the [GitHub repository](https://github.com/VoltageFoundryMod/ForgeSeries/releases). The firmware file is named `CURRENT.UF2`.
2. Connect the module to your computer using a USB-C cable while holding the small BOOT (B) button. The CPU can be removed from the module as it's socketed to the main board if desired. Firmware loading can be done with the CPU removed.
3. A new drive will show on your computer named RPI-RP2. Copy and overwrite the `CURRENT.UF2` file to the module USB drive. After copy is finished, the module will reboot and the new firmware will be loaded.

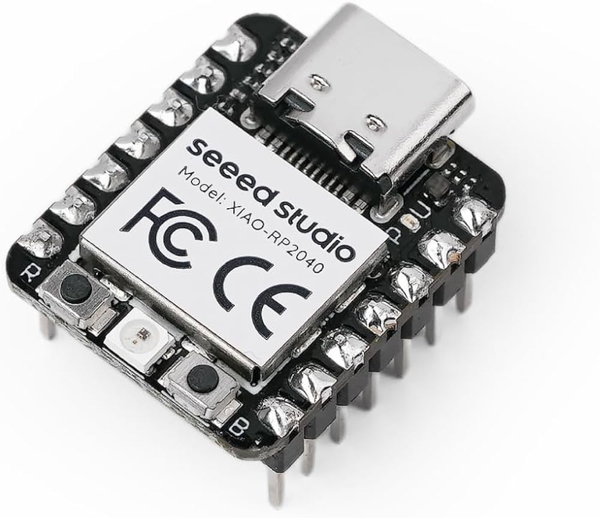
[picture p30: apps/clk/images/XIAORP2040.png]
XIAO RP2040 MCU


## Troubleshooting

- **No Power**: Ensure the module is properly connected to the power supply and the power jumper is set correctly.
- **No Output**: Verify the board connections and output settings and ensure the module is not stopped.
- **Inconsistent BPM**: Ensure the external clock signal is stable and properly connected.

## Powering

The module uses only 5V internally. This can be provided directly by a Eurorack supply with a 5V rail, or taken from the 12V line and converted to 5V on-board. The source is selected with an on-board jumper: closing the center pin to **INT REG** takes power from the Eurorack 12V supply, while closing the center pin to **EURO** takes power from the 5V rail (requires a 16-pin cable). It can also be powered from the USB-C jack on the microcontroller board.

**Never connect both the Eurorack power and the USB-C power at the same time**. The module might be damaged or even damage your computer if both are connected. The module is designed to be powered from either source, not both.

## Specifications

- **Power Supply**: 12V or 5V jumper selectable
- **Input CV Range**: 0–5V
- **Output CV Range**: 0–5V
- **Dimensions**: 6HP
- **Depth**: 40mm
- **Current Draw**: 60mA @ +12V or +5V

## Contact

For support and inquiries, please open an issue on the [GitHub repository](https://github.com/VoltageFoundryMod/ForgeSeries).

## Acknowledgements

Parts of the code are inspired by Hagiwo code, Quinienl's [LittleBen](https://github.com/Quinienl/LittleBen-Firmware) and Pamela's Workout.
Thanks for the inspiration!

## License

Source code is GPL-3.0-or-later — see the
[LICENSE](https://github.com/VoltageFoundryMod/ForgeSeries/blob/main/LICENSE) in the source repository.

Panel designs, graphics, module names and the Voltage Foundry Modular brand are
copyright and are not covered by that licence; see
[LICENSE-ASSETS.md](https://github.com/VoltageFoundryMod/ForgeSeries/blob/main/LICENSE-ASSETS.md).

---

Thank you for choosing the ClockForge module. We hope it enhances your musical creativity and performance.

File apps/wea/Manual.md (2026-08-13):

# WeaveForge — A Dual Shift-Register Sequencer

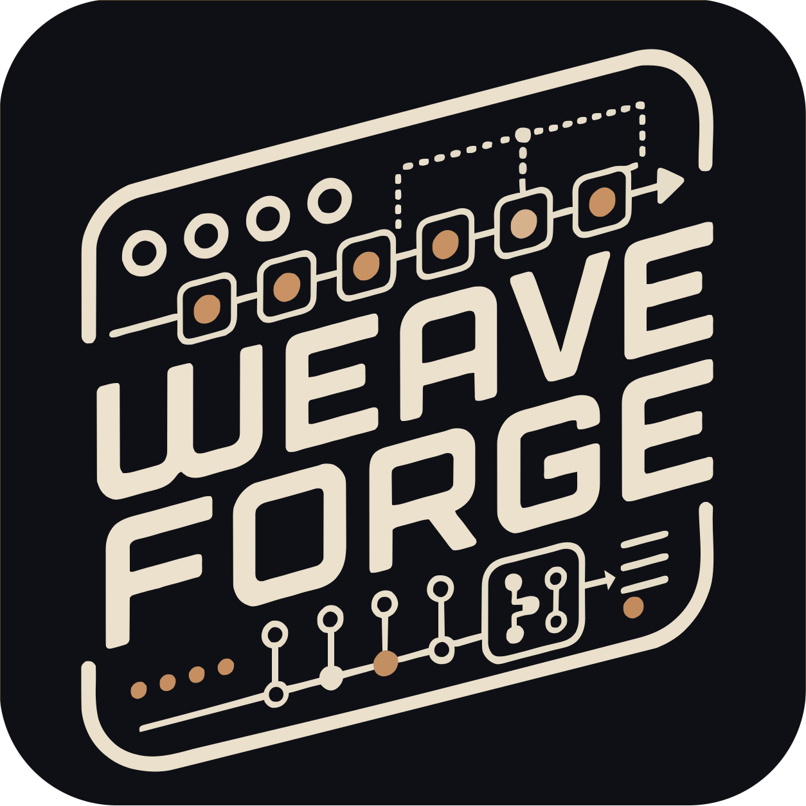
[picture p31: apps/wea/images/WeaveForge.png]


## Overview

Dual shift-register sequencer for the ForgeSeries hardware, and a VCV Rack
module built from the same code.

Two 16-bit shift registers clock in parallel. Each one is a Turing Machine in
Tom Whitwell's sense: a ring of bits that shifts on every clock, with one
probability control deciding whether the bit coming round the loop flips on the
way. At one end of that control the pattern is locked forever; at the other it
never repeats; in between it is a loop that changes a note now and then.

What makes this module its own thing is **WEAVE** — one control deciding how
much of each register's incoming bit comes from the _other_ register. At zero
they are two independent sequencers. Turned up, motifs leak across and drift
back. At full, the two registers chain tail-to-head into a single ring as long
as both of them together, and the screen draws the braid while it happens.

Four outputs read windows out of those registers, and each one is assignable:
notes, smooth modulation, gates or triggers, from either register or from the
woven ring, at any depth and any rotation. So the same two registers can be two
voices, one voice plus two correlated modulations, or a four-track drum machine.

WeaveForge Module

## Features

- Two 16-bit shift registers with independent length (2–16) and probability
- **WEAVE** — a continuous slide from two independent sequencers to one long one
- One-way coupling (`A▸B` / `B▸A`) for a theme-and-answer pair
- Four fully assignable outputs: source, type, window depth and rotation each
- Three one-click output layouts — two voices, voice + modulation, four drum tracks
- Quantized note outputs with 15 scales, root and transposition
- Gate and trigger outputs with a density control, not a fixed 50 %
- Internal clock or external, with multiplication and division either way
- Two assignable CV inputs; ten preset slots that store the patterns themselves

Check the module on [ModularGrid](https://modulargrid.net/e/voltage-foundry-modular-weaveforge).

---

## User Manual

- [WeaveForge — A Dual Shift-Register Sequencer](#weaveforge--a-dual-shift-register-sequencer)
  - [Overview](#overview)
  - [Features](#features)
  - [User Manual](#user-manual)
  - [Front panel](#front-panel)
  - [The screen](#the-screen)
  - [Menu map](#menu-map)
  - [REG A / REG B](#reg-a--reg-b)
  - [WEAVE](#weave)
  - [CLOCK](#clock)
  - [SCALE](#scale)
  - [ROUTING](#routing)
  - [OUT A1 / A2 / B1 / B2](#out-a1--a2--b1--b2)
  - [CV IN](#cv-in)
  - [SETTINGS](#settings)
  - [PRESETS](#presets)
  - [Patch ideas](#patch-ideas)
  - [In VCV Rack](#in-vcv-rack)
  - [Hardware Calibration](#hardware-calibration)
    - [What you need](#what-you-need)
    - [Running calibration](#running-calibration)
  - [Firmware Update](#firmware-update)
  - [Troubleshooting](#troubleshooting)
  - [Powering](#powering)
  - [Specifications](#specifications)
  - [Contact](#contact)
  - [Acknowledgements](#acknowledgements)
  - [License](#license)

## Front panel

| Jack | What it is |
| --- | --- |
| **IN 1** | **Clock.** Always — this jack has no role menu. A rising edge advances the sequencer. |
| **IN 2**, **IN 3** | Assignable modulation CV, 0–5 V. Destination and depth are set on the CV IN page. |
| **A 1**, **A 2** | The left column of outputs, 0–5 V. |
| **B 1**, **B 2** | The right column. |

The **encoder** turns to move through the menu, clicks to enter or leave a
value, and — held for two seconds — returns to the module selector.

**IN 1 is the clock and nothing else**, unlike GravityForge and ChaosForge where
that jack has a menu of jobs. Those modules run a simulation with a life of its
own; a shift register has no life between clocks, so a WeaveForge with nothing
patched to IN 1 would be a static voltage. An internal clock covers the
unpatched case, and RESET and the pattern-lock gate are available as CV
destinations on IN 2 / IN 3 instead.

**What the output jacks carry is not fixed.** The ROUTING page decides. In the
default DUO layout each register owns a column — A1/A2 are register A's note and
gate, B1/B2 are register B's — which is where the panel names come from. Any
other layout is free to break that, and the screen always tells you the truth.

Everything is 0–5 V. Note outputs are 1 V/oct over five octaves.

## The screen

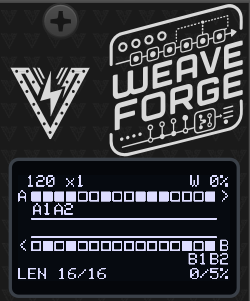
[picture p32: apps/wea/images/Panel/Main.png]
Main Panel


The home screen is **the loom**: both registers, the weave between them, and
where every output is reading.

**The two rows are the registers, and they run in opposite directions** —
register A left to right, register B right to left. That is not decoration. At
WEAVE 100 % the chain becomes a visible racetrack: a bit leaves A's right end,
crosses down through the channel, travels back along B, and comes up into A's
left end. You can follow one round it with a finger.

Each cell is one bit:

| Drawn | Means |
| --- | --- |
| filled block  | bit = 1, inside the active length |
| hollow block  | bit = 0, inside the active length |
| shaded block  | bit = 1, past the feedback point |
| small dot | bit = 0, past the feedback point |

So **LENGTH is a boundary you can see**, not a number to read: the point where
the row goes dim. The dim cells are still moving, and an output rotated out
there is still reading them — they show their bit value for exactly that reason
— but they are not part of the loop. They are a running copy of what has passed
through the feedback point, which is why they are drawn faint.

**The newest bit is punched through** for the first part of each step: whichever
cell just arrived gets a hole in its middle at the entering end of the row. On a
locked pattern that is the only thing on the row that changes, and it is how you
tell a running module from a stopped one at a glance.

**The small caret above each row points at the feedback tap** — the last cell of
the active length. That is the bit about to come round the loop, the one CHANCE
decides whether to flip, and the one that leaves for the other register when the
weave carries it across. Change LENGTH and the caret moves with the boundary
where the row goes dim; they are the same fact seen two ways.

**The channel between the rows is the weave.** At 0 % the two rails are dashed
with nothing crossing. As WEAVE comes up, strands appear crossing between them,
more of them the higher it goes, until at 100 % it is a full braid — and the
whole braid travels, so you can see the cloth being drawn through. It moves one
cell along per clock, the same rate the bits do, whatever WEAVE is set to. The
strands follow DIR, so a one-way weave shows them going one way only.

**A dot crossing the channel is a bit that actually jumped.** WEAVE is a
probability, so the braid says how much crossing is likely and the dot says what
happened: it leaves the sending register's feedback cell and arrives at the
receiving register's entering end, where the next step draws it as the new bit.
At a low WEAVE you get an open, quiet channel with something through it now and
then; at 100 % there is one every clock, each way.

**The labels under each row are the output jacks**, sitting at the cell they
read. `A1` and `A2` under register A's row mean those two jacks are reading it.
A label inverts to a solid block while its jack's gate or trigger is high, so you
can see which outputs are speaking as well as where they read from. Note and
modulation outputs have a value at all times, so they never light — their label
is a map, not a blinker. Set a jack's ROTATE and watch its label walk along the
row.

**The bar between a row and its labels is where that output reads from.** A jack
does not read one cell — it reads DEPTH of them, and the bar covers exactly those,
starting at its ROTATE. That is the group of bits being turned into the note, the
modulation, or the gate decision at that jack. Turn DEPTH and the bar grows;
turn ROTATE and it walks along the row. When several jacks read the same cells the
bars overlap into one, and while you are editing a jack its own bar is drawn
solid so you can pick it out.

**A dotted line joins each label to the cells it reads.** Two jacks reading the
same place cannot both have their label printed there, so the second one sits
along to the side — follow the dots rather than reading straight up from the
label, and you will always land on the right cells.

**Header:** the tempo large on the left, then the clock rate — prefixed `EXT`
when an external clock is running and the number is the measured tempo rather
than the one you set; weave amount on the right.
**Status line:** the two lengths, and the two probabilities.

Turning **LENGTH, CHANCE, WEAVE, DIR, BPM, RATE, DEPTH or ROTATE** hands the
screen back to the loom while you adjust, with the value in a strip along the
bottom — so the number and its effect are visible at the same time. It returns
to the page a few seconds after you stop.

## Menu map

Click the encoder to enter a value, turn to change it, click again to leave.

| Page | Rows |
| --- | --- |
| **home** | the loom |
| **REG A** | LENGTH · CHANCE · RANDOMIZE · INVERT · CLEAR · FILL |
| **REG B** | as A |
| **WEAVE** | AMOUNT · DIR |
| **CLOCK** | BPM · IN PPQN · RATE |
| **SCALE** | ROOT · SCALE · TRANSPOSE |
| **ROUTING** | ROUTING |
| **OUT A1 / A2 / B1 / B2** | SOURCE · TYPE · DEPTH · ROTATE · + two more |
| **CV IN** | IN2 DEST · IN2 DEPTH · IN3 DEST · IN3 DEPTH |
| **SETTINGS** | TIMEOUT · BOOT MENU |
| **PRESETS** | SLOT · SAVE · LOAD · RANDOM |

## REG A / REG B

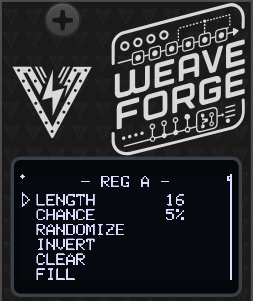
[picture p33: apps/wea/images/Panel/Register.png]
Register


The two registers are identical and independent. Everything here applies to
both.

**LENGTH** (2–16) — how many bits are in the loop. The bit at position
LENGTH−1 is the one fed back round to the start, so LENGTH is the number of
steps before the pattern comes round again.

**CHANCE** (0–100 %) — the probability that the bit coming round the loop flips
on the way. This one control is the whole character of the module, and _both
ends of it are settings_, not extremes to avoid:

| CHANCE  | What you get |
| --- | --- |
| 0 % | **Locked.** The pattern repeats every LENGTH steps, forever. |
| 10–30 % | A loop that changes a note now and then. |
| ~50 % | Maximum drift — a new sequence every time round. |
| 100 % | **Locked, inverting.** A pattern _twice_ LENGTH long. |

That last row is worth knowing: always-flip is exactly as deterministic as
never-flip. At LENGTH 16 and CHANCE 100 you get a locked 32-step phrase.

**RANDOMIZE** rolls new bits for this register. **INVERT** flips all sixteen —
the same rhythm inside out. **CLEAR** and **FILL** set them all to 0 or 1, which
are the two starting points to hand-build from once the bit editor lands.

> **Shortening LENGTH is destructive.** The region above the feedback point is
> overwritten within a few clocks, so turning LENGTH back up does not bring the
> longer pattern back. If you like a pattern, save it to a slot — the register
> contents are stored in the preset, which is the only way to keep one.

## WEAVE

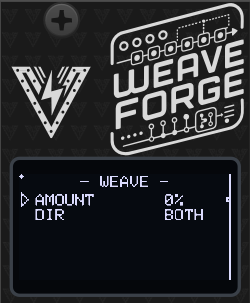
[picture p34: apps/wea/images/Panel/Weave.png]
Weave


The module's signature control, and the one the screen draws literally.

**AMOUNT** (0–100 %) — the probability, evaluated fresh for each register on
every clock, that its incoming bit is taken from the _other_ register's outgoing
bit instead of its own. CHANCE still applies afterwards, to whichever bit was
chosen.

| AMOUNT | Behaviour |
| --- | --- |
| 0 % | Two unrelated Turing Machines that happen to share a clock. |
| ~50 %  | Motifs leak across and drift back — related, never identical. |
| 100 %  | The tails swap every clock: one ring, as long as both together. |

At 100 % with both lengths at 16 that is a locked 32-step phrase spread across
two outputs — something no amount of turning a single Turing Machine's knob will
give you. The two lengths do not have to match: 5 and 3 chain into a ring of 8.

**DIR** — `BOTH`, `A▸B` or `B▸A`. One-way is the most useful of the three in
practice: with `A▸B`, register B becomes a variation on A that cannot
contaminate it. A stays the theme; B is the answer.

## CLOCK

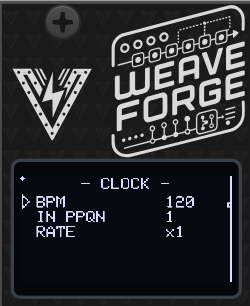
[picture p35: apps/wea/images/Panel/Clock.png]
Clock


**BPM** (20–300) — the internal tempo, used whenever no external clock is
running. When one _is_ running, this row shows the derived tempo with an `E`
after it, and the number you set is remembered for when the cable comes out.

**IN PPQN** (1, 2, 4, 8, 24) — how many pulses the clock arriving at IN 1 sends
per beat. This is a description of your clock source, not a setting that changes
the sequencer: 4 means you are feeding it sixteenth notes. It does nothing when
the internal clock is running.

**RATE** — steps per beat, and it means the same thing whether the tempo comes
from IN 1 or from BPM:

| RATE | One step every… |
| --- | --- |
| `/16` `/8` `/6` `/4` `/3` `/2` | 16, 8, 6, 4, 3 or 2 beats |
| `x1` | beat — the tempo as set |
| `x2` `x3` `x4` `x6` `x8` `x16` | 1/2, 1/3, 1/4 … of a beat |

`x1` is the tempo on the header, so the module boots stepping at exactly the
number it displays. The table is symmetric, so a click one way is the mirror of
a click the other. Multiplied steps are locked to the incoming clock's beat
rather than free-running, so they stay in time as the tempo moves.

The sequencer keeps playing on its internal tempo if the external clock stops or
is unpatched.

## SCALE

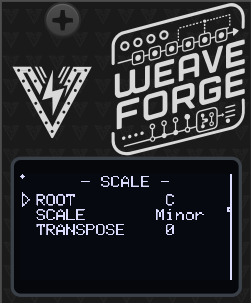
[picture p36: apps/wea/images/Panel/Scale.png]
Scale


Applies to every NOTE output; there is one scale for the whole module, which is
what makes two note outputs sound like one instrument rather than two.

**ROOT** (C–B) and **SCALE** — chromatic, major, minor, the modes, both
pentatonics, harmonic and melodic minor, whole tone, diminished and blues.
Together they build the set of notes the outputs can land on.

**TRANSPOSE** (−24 to +24 semitones) — shifts every note output.

## ROUTING

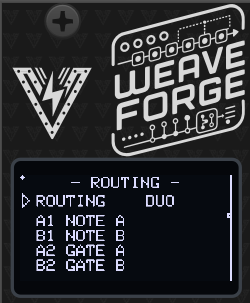
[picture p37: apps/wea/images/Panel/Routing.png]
Routing


One row, and it is the fastest way to change what the module _is_. Picking a
layout configures all four jacks at once, and the four lines below the row show
what it did.

| ROUTING | A1 | B1 | A2 | B2 | The module is… |
| --- | --- | --- | --- | --- | --- |
| `DUO` | NOTE A | NOTE B | GATE A | GATE B | two voices |
| `MONO`  | NOTE A | GATE A | MOD A  | MOD B | one voice plus two modulations |
| `PULSE` | TRIG A | TRIG A (rot 8) | TRIG B | TRIG B (rot 8) | a four-track drum machine |

**Picking a layout stamps the jacks and then steps out of the way.** Every field
on every OUT page stays editable afterwards, and once you change one this row
reads `CUSTOM`. Bring the jacks back into line with a layout and it names that
layout again — nothing is remembering that you edited anything.

Each layout keeps WEAVE meaningful: in DUO it merges two voices into one long
shared phrase, in MONO it slides the second modulation from unrelated to locked
with the melody, and in PULSE it merges two independent drum patterns into one.

## OUT A1 / A2 / B1 / B2

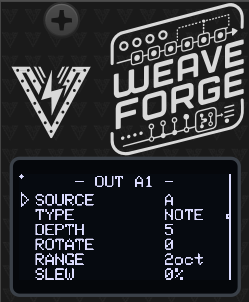
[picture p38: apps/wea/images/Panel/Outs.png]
Outputs


One page per jack, six rows each. The last two change meaning with TYPE.

The pages come in **panel order — down the left column, then down the right** —
so turning the encoder past A1 lands on A2 below it rather than jumping across to
B1. The ROUTING page's summary and the Rack context menu list them the same way.

**SOURCE** — `A`, `B`, or `AB`. `AB` is the two registers as one 32-position
ring, which is what WEAVE at 100 % actually makes them.

**TYPE**

| TYPE | Emits |
| --- | --- |
| `NOTE` | A quantized pitch, 1 V/oct. |
| `MOD`  | A stepped voltage — the original Turing Machine's main CV output. |
| `GATE` | High while the jack fires, low at the first step where it does not. |
| `TRIG` | A fixed-width pulse each time the jack fires. |

**DEPTH** (1–8 bits) — how many bits this jack reads. More bits, finer
resolution.

**ROTATE** — where in the register it reads. This is the highest-value control
on the page: four jacks tapping the _same_ register at different offsets are
four phase-shifted copies of one pattern. Set a gate four steps behind its note
and you have a canon; do it across a drum kit and you have four tracks that
cannot drift apart. Its range follows SOURCE — 0–15 for a single register, 0–31
for `AB`.

**Fifth row, per TYPE:**

- `NOTE` ▸ **RANGE** (1–5 octaves) — the span the pattern is spread across.
  DEPTH sets resolution and RANGE sets span, so the two stay independent: 3 bits
  over 2 octaves is a sparse, singable line; 7 bits over the same 2 octaves
  wanders finely through it.
- `MOD` ▸ **LEVEL** (0–100 %) — output scaling.
- `GATE` / `TRIG` ▸ **THRESH** (0–100 %) — how often it fires. The bits are
  compared against this threshold rather than a single bit being read, so a gate
  output has a _density_ control: 12 % is a sparse kick, 88 % a busy hat — and
  both are still locked to the same register as the melody. At DEPTH 1 and
  THRESH 50 % it is exactly the classic behaviour.

**Sixth row, per TYPE:**

- `NOTE` / `MOD` ▸ **SLEW** (0–100 %) — glide between values.
- `TRIG` ▸ **WIDTH** — pulse length in milliseconds.
- `GATE` has no sixth parameter and shows `-`.

## CV IN

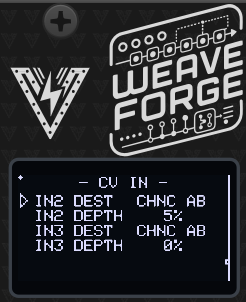
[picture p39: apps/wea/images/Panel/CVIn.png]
CV In


**IN2 DEST / IN3 DEST** — what that input modulates:

| Destination | Notes |
| --- | --- |
| `OFF` | nothing |
| `LEN A` `LEN B` `LEN AB` | pattern length |
| `CHNC A` `CHNC B` `CHNC AB` | probability |
| `WEAVE` | the coupling |
| `TRANS` | transposition of every note output |
| `ROTATE` | every jack's rotation together — moves all the taps |
| `RESET` | gate: restarts both patterns from a known state |
| `LOCK` | gate: holds the patterns while high |

**IN2 DEPTH / IN3 DEPTH** (0–100 %) — how much. Length, probability and weave
are _trims_ around whatever the menu is set to, so a centred CV leaves the panel
setting alone.

`RESET` and `LOCK` act on the level of the input and ignore depth. `LOCK` forces
probability to zero while it is high, which is the quickest way to freeze a
phrase from outside the module, and it wins over a CHANCE knob at 100 %.

## SETTINGS

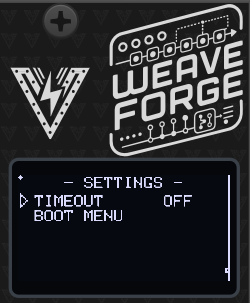
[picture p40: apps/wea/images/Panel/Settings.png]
Settings


**TIMEOUT** — how long the menu waits before dropping back to the loom: `OFF`,
2, 5, 10 or 20 seconds.

**BOOT MENU** — returns to the module selector, the same as holding the encoder
for two seconds. The selector is also the only way into the calibration wizard.

## PRESETS

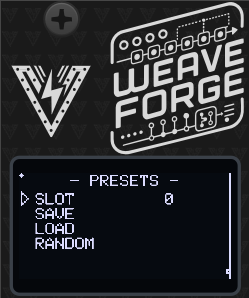
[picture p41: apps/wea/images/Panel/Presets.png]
Presets


Ten slots. **Slot 0 is loaded automatically at power-on**, so save the patch you
want to start with there.

**SLOT** picks the slot; **SAVE** and **LOAD** do what they say. A dot in the
top-left corner of the screen means the live state differs from what is stored.

**RANDOM** rolls a new patch: new bits in both registers, new lengths and
probabilities, a new weave. It deliberately leaves the output routing, the CV
destinations, the scale and the clock alone — those are decisions you made on
purpose, and rerolling them would turn "give me a new phrase" into "break my
patch". It does not write a slot, so a saved patch is one LOAD away.

**The register contents are part of a preset**, not just the settings. That is
the point: a preset that restored the right length and the wrong bits would have
restored nothing you cared about.

## Patch ideas

- **Two voices, converging.** DUO, both lengths at 16, CHANCE around 25 %. Take
  A1/A2 to one voice and B1/B2 to another, then bring WEAVE up slowly from zero.
  Two unrelated lines pull together into one long phrase spread across both
  voices. This is the module in one knob.
- **Theme and answer.** DIR `A▸B`, WEAVE around 60 %. B follows A and can never
  disturb it.
- **A drum machine off the bass line.** PULSE, then set THRESH per track — low
  for the kick, high for the hats. The rhythm and the melody come from the same
  register, so they are locked together by construction.
- **Canon.** DUO, then set A2's ROTATE to 4. The gate plays the pattern four
  steps behind the note.
- **Keep one.** Let it drift until something good goes past, pull CHANCE to 0 to
  freeze it, and save the slot. Or patch `LOCK` and freeze it with a footswitch.
- **A very long loop.** Both lengths 16, WEAVE 100 %, CHANCE 0. One locked
  32-step phrase. Set CHANCE to 100 instead for a 64-step one.

## In VCV Rack

The Rack module runs the same firmware against a hardware shim, with the OLED
emulated pixel for pixel, so it behaves identically to the panel.

Drag the encoder to scroll and click to select. With the mouse over the module,
`[` and `]` turn the encoder one detent and `space` clicks it.

Everything on the panel is also on the right-click menu — Weave, both registers
with their pattern actions, the output matrix, clock, scale and CV routing —
with real sliders and option lists instead of relayed encoder turns. The context
menu also carries an input CV range setting (0–5 V like the hardware, ±5 V or
0–10 V) and an encoder sensitivity setting.

Saving a Rack patch stores the live state, including the patterns themselves, so
a reloaded patch plays the phrase you left it on.

## Hardware Calibration

The module ships with sensible default values, but for best precision —
especially when using the quantized note outputs — you should run the hardware
calibration wizard once after building or assembling the module.

Calibration covers two things:

**Output trim**: the output op-amp gain is set with on-board trimmers so every output jack delivers exactly 5.00 V at full scale. This is purely a hardware adjustment — there is no software output scaling.
**CV input calibration**: each CV input is measured at two known reference voltages (1 V and 3 V) to build a per-channel linear correction (`mv = scale × reading + offset`) that compensates for resistor tolerances and ADC offset. This is done with external references and is independent of the module's own outputs, so any output-trim error does not propagate into the input calibration.

Calibration data is stored in a dedicated area of non-volatile memory **separate from presets**, so it survives firmware updates and preset load/save operations.

### What you need

- A multimeter capable of measuring DC voltage to at least two decimal places (for the output trim).
- A stable, known **1 V** and **3 V** source for the CV inputs — for example a precision voltage reference, a bench power supply, or a calibrated sequencer/quantizer output — and a patch cable to connect it.

### Running calibration

The wizard has 5 steps: one output trim followed by four CV input captures (1 V and 3 V on each of the two inputs).

1. Power on the module **from your Eurorack supply** while **holding the encoder button** pressed, which opens the module selector. Release the button, scroll to **CALIBRATE** at the bottom of the list and click. (From a running module you can get to the same screen with **SETTINGS → BOOT MENU**, or by holding the encoder for two seconds.) Click the encoder at the welcome screen to start.

   Calibration belongs to the board, not to any one module: one run covers every module in the firmware, and the wizard reboots back to the selector when it is done.

   > ⚠️ Calibrate on Eurorack power, **not** the MCU's USB port — USB cannot drive the outputs to full scale, so the trim would be wrong. **Never connect Eurorack power and USB at the same time, as this could damage the module.**

2. **Step 1 — Output trim** (`1/5  OUTPUT TRIM`):
   All four outputs are driven to full scale. Using a multimeter set to DC voltage, probe each output jack in turn and adjust its corresponding trimmer potentiometer on the PCB until the reading is exactly **5.00 V**. When all four outputs read 5.00 V, press the encoder to continue.

3. **Steps 2–5 — CV input capture** (`2/5` … `5/5`):
   The display asks for a specific reference voltage on a specific input, in turn:
   - `2/5  CV1 INPUT 1V` — apply **1 V** to CV input 1
   - `3/5  CV1 INPUT 3V` — apply **3 V** to CV input 1
   - `4/5  CV2 INPUT 1V` — apply **1 V** to CV input 2
   - `5/5  CV2 INPUT 3V` — apply **3 V** to CV input 2

   For each step, apply the requested voltage to the named input. The screen shows a live voltage reading so you can confirm the signal is stable; when it is steady, press the encoder to capture (256 ADC samples are averaged). Repeat for all four steps.

4. **Review and save**:
   The display shows the derived per-channel scale and offset for a sanity check. Press the encoder to **save and reboot**. The module restarts with calibration applied.

> **Tip:** Calibration only needs to be run once. Re-run it if you replace any resistors or trimmers on the board, or if CV tracking feels off after assembly.

## Firmware Update

1. Download the latest firmware from the Releases section of the [GitHub repository](https://github.com/VoltageFoundryMod/ForgeSeries/releases).
2. Connect the module to your computer using a USB-C cable while holding the small BOOT (B) button. The CPU can be removed from the module as it's socketed to the main board if desired. Firmware loading can be done with the CPU removed.
3. A new drive will show on your computer named RPI-RP2. Copy the `.uf2` file to the module USB drive. After copy is finished, the module will reboot and the new firmware will be loaded.

## Troubleshooting

- **No Power**: Ensure the module is properly connected to the power supply and the power jumper is set correctly.
- **Nothing happens**: This module does not run without a clock. Patch one to IN 1, or check that the CLOCK page's BPM is set — the internal clock takes over whenever no external one is arriving.
- **The pattern never changes**: CHANCE is at 0 on both registers, or a `LOCK` gate is high on one of the CV inputs. Both are deliberate freezes.
- **The pattern will not settle**: CHANCE near 50 % is maximum drift. Come down to 10–30 % for a loop that changes occasionally, or to 0 to lock it.
- **A gate output fires constantly or never**: check that jack's THRESH — it is a density control, and 0 % and 100 % are silence and a solid gate.
- **Note outputs are all the same pitch**: check RANGE on that jack, and that the scale has more than one note enabled.

## Powering

The module uses only 5V internally. This can be provided directly by a Eurorack supply with a 5V rail, or taken from the 12V line and converted to 5V on-board. The source is selected with an on-board jumper: closing the center pin to **INT REG** takes power from the Eurorack 12V supply, while closing the center pin to **EURO** takes power from the 5V rail (requires a 16-pin cable). It can also be powered from the USB-C jack on the microcontroller board.

**Never connect both the Eurorack power and the USB-C power at the same time**. The module might be damaged or even damage your computer if both are connected. The module is designed to be powered from either source, not both.

## Specifications

- **Power Supply**: 12V or 5V jumper selectable
- **Input CV Range**: 0–5V
- **Output CV Range**: 0–5V
- **Dimensions**: 6HP
- **Depth**: 40mm
- **Current Draw**: 60mA @ +12V or +5V

## Contact

For support and inquiries, please open an issue on the [GitHub repository](https://github.com/VoltageFoundryMod/ForgeSeries).

## Acknowledgements

The shift register is Tom Whitwell's [Turing Machine](https://www.musicthing.co.uk/Turing-Machine/),
by way of Hemisphere Suite's ShiftReg. The assignable output matrix is the good
idea from Phazerville's [Enigma](https://firmware.phazerville.com/Enigma).
Thanks for the inspiration!

## License

Source code is GPL-3.0-or-later — see the
[LICENSE](https://github.com/VoltageFoundryMod/ForgeSeries/blob/main/LICENSE) in the source repository.

Panel designs, graphics, module names and the Voltage Foundry Modular brand are
copyright and are not covered by that licence; see
[LICENSE-ASSETS.md](https://github.com/VoltageFoundryMod/ForgeSeries/blob/main/LICENSE-ASSETS.md).

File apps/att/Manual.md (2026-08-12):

# ChaosForge — A Chaotic-Attractor Modulation Source



## Overview

Dual chaotic-attractor modulation source for the ForgeSeries hardware, and a VCV
Rack module built from the same core.

The module is built with a catalogue of published chaotic systems, each with its own constants and three state variables. Each generator runs one system, and the two can be linked to pull on each other.

The module hosts two attractors at a time and the user can adjust the constants, speed, output axes, level, offset and smoothing for each. The attractors are drawn on the screen in real time, and the user can assign two modulation inputs to control speed, constants, level, offset or coupling.

ChaosForge Module

Check the module on [ModularGrid](https://modulargrid.net/e/voltage-foundry-modular-chaosforge).

## Features

- Three inputs to control the attractor parameters
- Two outputs from each attractor, for a total of four jacks
- Two attractors, each with its own system, constants, speed, output axes, level, offset and smoothing
- A link between the two attractors, adjustable for variation and strength
- Nothing is ever quite the same twice, but it always sounds like the same instrument.

- [ChaosForge — A Chaotic-Attractor Modulation Source](#chaosforge--a-chaotic-attractor-modulation-source)
  - [Overview](#overview)
  - [Features](#features)
  - [Front panel](#front-panel)
  - [The screen](#the-screen)
  - [Menu map](#menu-map)
  - [A SYSTEM / B SYSTEM](#a-system--b-system)
  - [A OUTPUT / B OUTPUT](#a-output--b-output)
  - [LINK](#link)
  - [CV IN](#cv-in)
  - [SETTINGS](#settings)
  - [PRESETS](#presets)
  - [The twelve systems](#the-twelve-systems)
  - [In VCV Rack](#in-vcv-rack)

---

## Front panel

| Jack | What it is |
| --- | --- |
| **IN 1** | Trigger/gate. Its job is set by LINK ▸ IN 1: re-seed both orbits, re-seed one, or freeze both while the input is high. |
| **IN 2**, **IN 3** | Assignable modulation CV, 0–5 V. Destination and depth are set on the CV IN page. |
| **A 1**, **A 2** | Generator A's two outputs, 0–5 V. Each follows one axis of A's orbit. |
| **B 1**, **B 2** | Generator B's two outputs. |

The **encoder** turns to move through the menu, clicks to enter or leave a value,
and — held for two seconds — returns to the module selector.

Everything is 0–5 V. There is no negative rail on this hardware; OFFSET slides the
pair inside that range and LEVEL scales it.

## The screen

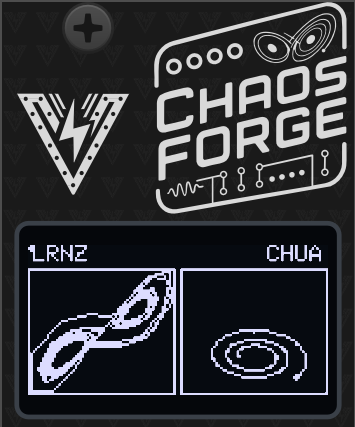
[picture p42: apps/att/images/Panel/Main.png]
Main Panel


Left alone, the screen shows the **plot**: each generator's two outputs drawn
against each other. That is the view that shows what the module is actually doing
— one trace against time is a wobble, the pair is the attractor.

```txt
 LRNZ      C45      RSSL      <- system names, and COUPLE when it is up
┌───────────┐┌───────────┐
│    ╱▔▔╲ ││  ╱▔╲      │
│   ╱   ○│  ││ ○   ╲     │    ○ = where the orbit is right now
│  ╲___╱    ││  ╲__╱     │
└───────────┘└───────────┘
```

- The **filled dot** is the present; the trail behind it is where the orbit has
  just been. It is sampled on the orbit's own clock, so the figure covers the same
  amount of trajectory at any SPEED.
- The centre badge shows **C** and the couple percentage while LINK is up, or
  **FRZ** while IN 1 is holding the orbits frozen.
- The plot draws the value _before_ LEVEL and OFFSET, so the figure keeps filling
  the frame however the jacks are scaled. A trace flattening against the frame
  edge means the jack is clipping.
- SETTINGS ▸ VIEW gives a single generator the whole screen.

While you are turning any control that changes the figure, the plot takes over the
screen with the value in a strip along the bottom, so you can see the effect and
read the number at the same time. It hands the page back a few seconds after you
stop.

## Menu map

Turning the encoder walks through every row; the page changes when you cross into
the next group.

| Page | Rows |
| --- | --- |
| **plot** | the home screen |
| **A SYSTEM** | SYSTEM · SPEED · P1 · P2 · P3 · P4 |
| **A OUTPUT** | A1 · A2 · LEVEL · OFFSET · SMOOTH · RANGE |
| **B SYSTEM** | as A |
| **B OUTPUT** | B1 · B2 · LEVEL · OFFSET · SMOOTH · RANGE |
| **LINK** | COUPLE · IN 1 · RESEED A · RESEED B · RESEED ALL |
| **CV IN** | IN2 DEST · IN2 DEPTH · IN3 DEST · IN3 DEPTH |
| **SETTINGS** | VIEW · TIMEOUT · BOOT MENU |
| **PRESETS**  | SLOT · SAVE · LOAD · RANDOM |

## A SYSTEM / B SYSTEM

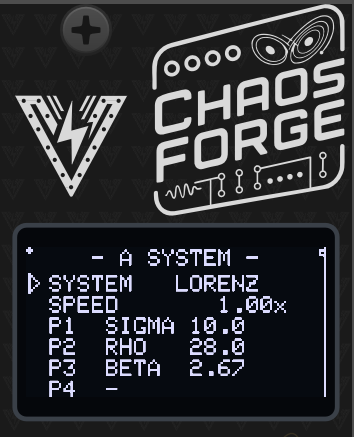
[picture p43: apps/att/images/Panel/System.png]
SystemMenu


**SYSTEM** — which set of equations this generator runs. Changing it loads that
system's published constants, because parameter 1 means SIGMA on Lorenz and ALPHA
on Chua; the old numbers would mean nothing in the new equation.

**SPEED** — 0.01× to 100×, and 1.00× is comparable motion on every system: a
Lorenz wing takes about four seconds there, a Rössler circuit about six. The
control is geometric, so a detent is a percentage rather than a fixed amount, and
turning faster moves further.

1.00× is deliberately a tenth of the rate these systems are usually _shown_ at —
that rate is a good one to look at and a fast one to modulate with, so the middle
of the dial sits well below it and the top of the range reaches it and beyond.

**P1 – P4** — that system's own constants, shown with the names the literature
uses. A system with fewer than four shows the unused rows as `-`; Sprott B and C
have none at all, which is the point of them. Some of these ranges include
_periodic_ windows where the system stops being chaotic and settles into a
repeating loop — that is a usable sound (a pair of smooth, oddly-shaped LFOs), not
a fault. Thomas's B is the one to explore for it.

If a setting leaves the system with no bounded orbit at all, the generator
re-seeds itself rather than pinning the jack to a rail. You will hear the pattern
restart; back the constant off.

## A OUTPUT / B OUTPUT

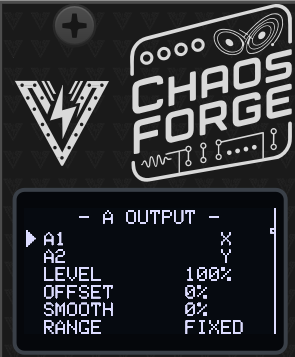
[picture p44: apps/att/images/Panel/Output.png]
Output


**A1 / A2** (and B1 / B2 for generator B) — which state variable each
jack follows: X, Y or Z.

The four jacks are two rows of two, and **each generator owns a column**:
A1 above A2 down the left, B1 above B2 down the right. Which pair is which is
therefore readable at a glance, which two identical-looking rows would not be. Every system's three axes have different characters;
Rössler's Z, for example, is flat with occasional sharp folds while its X and Y
drift smoothly.

Pointing both jacks at the same axis is allowed, and gives two copies of one
voltage. It is also the quickest way to prove to yourself that the pair really are
different signals.

**LEVEL** — 0–100 %, scaling the swing around the middle of the range. At 0 the
jack sits at 2.5 V, not at 0 V.

**OFFSET** — ±100 %, sliding the pair up or down inside 0–5 V.

**SMOOTH** — 0–100 %, a lag on the output. Rounds the leading edge of the one fast
event some of these systems have.

**RANGE** — FIXED or AUTO.

- **FIXED** scales the jack by a window measured at the system's published
  constants. Predictable and identical every boot.
- **AUTO** tracks the orbit's own window instead. Use it once you have moved the
  constants far enough that the figure no longer fills the jack — it widens
  instantly and closes back in slowly, so a rare excursion is never clipped.

## LINK

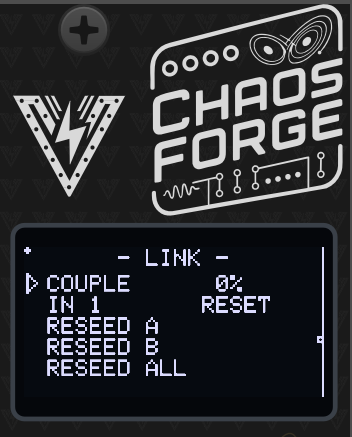
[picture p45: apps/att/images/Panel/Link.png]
Link


**COUPLE** — 0–100 %, how hard the two orbits pull on each other. At 0 they are
completely independent. Turned up they _entrain_: they start sharing their timing
while keeping their own shapes. Near the top, two generators running the same
system lock onto a single orbit and all four jacks become two signals.

**IN 1** — what the trigger jack does:

| | |
| --- | --- |
| **RESET** | a rising edge puts both orbits back on their start points |
| **RESET A** | ...just generator A |
| **RESET B** | ...just generator B |
| **FREEZE**  | while the input is **high**, both orbits hold, and every output holds its exact voltage |

FREEZE reads the level rather than the edge, so it is playable with a gate.
Releasing resumes where it stopped — the paused time is not banked and replayed.

**RESEED A / B / ALL** — the same gesture from the menu. On a system this
sensitive, re-seeding is not "the same pattern again": the two generators start a
thousandth apart and are somewhere else entirely within seconds. It is a fresh
draw from the same figure.

## CV IN

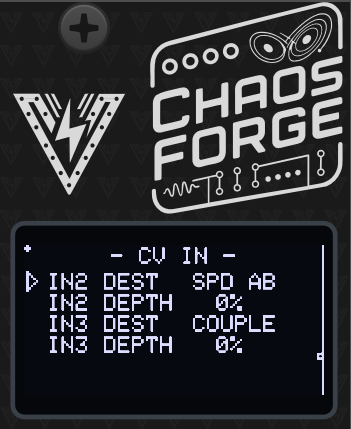
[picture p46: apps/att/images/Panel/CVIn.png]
CVIn


Two assignable modulation inputs, each with a destination and a depth.

| Destination | What it moves |
| --- | --- |
| **OFF** | nothing |
| **SPD A / SPD B / SPD AB** | speed, ±3 octaves at full depth |
| **P1 A / P1 B / P2 A / P2 B** | the first or second constant of a generator, over a fraction of its own range |
| **LVL A / LVL B / LVL AB** | level — _downward_ from the menu setting, so the jack becomes a VCA |
| **OFS A / OFS B** | offset |
| **COUPLE** | the link between the generators |

Depth is 0–100 %. Speed is modulated multiplicatively, because it is a rate.
Level modulates downward on purpose: at LEVEL 100 %, where the control is nearly
always left, upward modulation would do nothing.

## SETTINGS

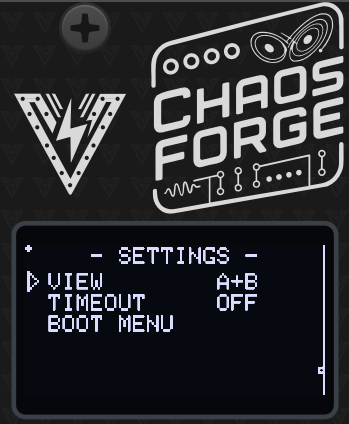
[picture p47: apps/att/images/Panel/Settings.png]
Settings


**VIEW** — whether the plot shows both generators side by side (`A+B`) or gives
one of them the whole screen.

**TIMEOUT** — how long the menu waits before dropping back to the plot.

**BOOT MENU** — returns to the module selector, which is also the only way into
the board's calibration wizard. Holding the encoder for two seconds does the same
thing.

## PRESETS

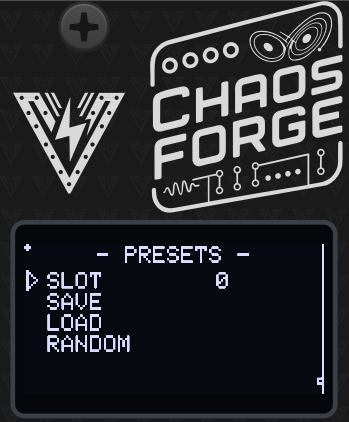
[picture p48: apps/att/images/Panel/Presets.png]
Presets


Ten slots. Slot 0 is loaded automatically at power-on, so save the patch you want
to boot into there.

**RANDOM** rolls a new pair of systems, constants, speeds, axes and shaping — and
a modest amount of COUPLE. It deliberately leaves the IN 1 role, the CV matrix, the
view and RANGE alone: those are how the module is wired into the patch, not how it
sounds. It does not write a slot, so a saved patch is one LOAD away.

The dot in the top-left corner means there are unsaved changes.

## The twelve systems

| System | Constants | Character |
| --- | --- | --- |
| **Lorenz** | SIGMA, RHO, BETA | The double wing. Switches lobes at irregular intervals — the classic. |
| **Rössler** | A, B, C | Smooth spiral with a sharp fold on Z. The nearest thing here to an event output. |
| **Thomas** | B | The gentlest: no spikes, all three axes alike. Its range holds several periodic windows. |
| **Chua** | ALPHA, BETA, M0, M1 | The double scroll, and the one you can build out of op-amps. |
| **Halvorsen**  | A | Three-fold symmetry, three interlocked scrolls. |
| **Chen** | A, B, C | The fastest and widest here. Found while trying to control Lorenz. |
| **Burke-Shaw** | S, V | A compact, tightly wound figure-eight. |
| **Aizawa** | A, B, C, D | A torus with a spiralling skirt. Two further shape constants are held at their published values. |
| **Dadras** | A, B, C, D | A knotted structure with sharp direction changes. |
| **Sprott B** | — | Minimal chaos, three terms, nothing to turn. |
| **Sprott C** | — | The other minimal one; a different route into chaos. |
| **Finance** | A, B, C | Boom/bust cycles. Its Y axis leans rather than swings. |

## In VCV Rack

The Rack module runs the same firmware. The screen, the encoder and every menu
page behave identically — drag the encoder to scroll, click to select, or hover
the module and use `[`, `]` and space.

The right-click menu offers the same parameters as real option lists and sliders,
which is faster than relaying encoder detents:

- **Hardware** — input CV range, encoder sensitivity, which generator the screen
  shows.
- **Link** — couple, the IN 1 role, re-seed both.
- **CV modulation** — destination and depth for IN 2 and IN 3.
- **Generator A / Generator B** — attractor, speed, that system's constants (the
  list changes with the system), output axes, level, offset, smooth, auto range
  and a per-generator re-seed.

**Initialize** restores the factory patch; **Randomize** rolls the same kind of
patch the panel's RANDOM does. Patch save/load carries the whole module state,
including your preset slots.

## Hardware Calibration

The module ships with sensible default values, but for best precision — especially when using quantization or 1V/oct pitch CV — you should run the hardware calibration wizard once after building or assembling the module.

Calibration covers two things:

**Output trim**: the output op-amp gain is set with on-board trimmers so every output jack delivers exactly 5.00 V at full scale. This is purely a hardware adjustment — there is no software output scaling.
**CV input calibration**: each CV input is measured at two known reference voltages (1 V and 3 V) to build a per-channel linear correction (`mv = scale × reading + offset`) that compensates for resistor tolerances and ADC offset. This is done with external references and is independent of the module's own outputs, so any output-trim error does not propagate into the input calibration.

Calibration data is stored in a dedicated area of non-volatile memory **separate from presets**, so it survives firmware updates and preset load/save operations.

### What you need

- A multimeter capable of measuring DC voltage to at least two decimal places (for the output trim).
- A stable, known **1 V** and **3 V** source for the CV inputs — for example a precision voltage reference, a bench power supply, or a calibrated sequencer/quantizer output — and a patch cable to connect it.

### Running calibration

The wizard has 5 steps: one output trim followed by four CV input captures (1 V and 3 V on each of the two inputs).

1. Power on the module **from your Eurorack supply** while **holding the encoder button** pressed, which opens the module selector. Release the button, scroll to **CALIBRATE** at the bottom of the list and click. (From a running module you can get to the same screen with **SETTINGS → BOOT MENU**, or by holding the encoder for two seconds.) Click the encoder at the welcome screen to start.

   Calibration belongs to the board, not to any one module: one run covers every module in the firmware, and the wizard reboots back to the selector when it is done.

   > ⚠️ Calibrate on Eurorack power, **not** the MCU's USB port — USB cannot drive the outputs to full scale, so the trim would be wrong. **Never connect Eurorack power and USB at the same time, as this could damage the module.**

2. **Step 1 — Output trim** (`1/5  OUTPUT TRIM`):
   All four outputs are driven to full scale. Using a multimeter set to DC voltage, probe each output jack in turn and adjust its corresponding trimmer potentiometer on the PCB until the reading is exactly **5.00 V**. When all four outputs read 5.00 V, press the encoder to continue.

3. **Steps 2–5 — CV input capture** (`2/5` … `5/5`):
   The display asks for a specific reference voltage on a specific input, in turn:
   - `2/5  CV1 INPUT 1V` — apply **1 V** to CV input 1
   - `3/5  CV1 INPUT 3V` — apply **3 V** to CV input 1
   - `4/5  CV2 INPUT 1V` — apply **1 V** to CV input 2
   - `5/5  CV2 INPUT 3V` — apply **3 V** to CV input 2

   For each step, apply the requested voltage to the named input. The screen shows a live voltage reading so you can confirm the signal is stable; when it is steady, press the encoder to capture (256 ADC samples are averaged). Repeat for all four steps.

4. **Review and save**:
   The display shows the derived per-channel scale and offset for a sanity check. Press the encoder to **save and reboot**. The module restarts with calibration applied.

> **Tip:** Calibration only needs to be run once. Re-run it if you replace any resistors or trimmers on the board, or if CV tracking feels off after assembly.

## Firmware Update

1. Download the latest firmware from the Releases section of the [GitHub repository](https://github.com/VoltageFoundryMod/ForgeSeries/releases). The firmware file is named `CURRENT.UF2`.
2. Connect the module to your computer using a USB-C cable while holding the small BOOT (B) button. The CPU can be removed from the module as it's socketed to the main board if desired. Firmware loading can be done with the CPU removed.
3. A new drive will show on your computer named RPI-RP2. Copy and overwrite the `CURRENT.UF2` file to the module USB drive. After copy is finished, the module will reboot and the new firmware will be loaded.

XIAO RP2040 MCU

## Troubleshooting

- **No Power**: Ensure the module is properly connected to the power supply and the power jumper is set correctly.
- **No Output**: Verify the board connections and output settings and ensure the module is not stopped.
- **Inconsistent BPM**: Ensure the external clock signal is stable and properly connected.

## Powering

The module uses only 5V internally. This can be provided directly by a Eurorack supply with a 5V rail, or taken from the 12V line and converted to 5V on-board. The source is selected with an on-board jumper: closing the center pin to **INT REG** takes power from the Eurorack 12V supply, while closing the center pin to **EURO** takes power from the 5V rail (requires a 16-pin cable). It can also be powered from the USB-C jack on the microcontroller board.

**Never connect both the Eurorack power and the USB-C power at the same time**. The module might be damaged or even damage your computer if both are connected. The module is designed to be powered from either source, not both.

## Specifications

- **Power Supply**: 12V or 5V jumper selectable
- **Input CV Range**: 0–5V
- **Output CV Range**: 0–5V
- **Dimensions**: 6HP
- **Depth**: 40mm
- **Current Draw**: 60mA @ +12V or +5V

## Contact

For support and inquiries, please open an issue on the [GitHub repository](https://github.com/VoltageFoundryMod/ForgeSeries).

## Acknowledgements

Parts of the code are inspired by Hagiwo code, Quinienl's [LittleBen](https://github.com/Quinienl/LittleBen-Firmware) and Pamela's Workout.
Thanks for the inspiration!

## License

Source code is GPL-3.0-or-later — see the
[LICENSE](https://github.com/VoltageFoundryMod/ForgeSeries/blob/main/LICENSE) in the source repository.

Panel designs, graphics, module names and the Voltage Foundry Modular brand are
copyright and are not covered by that licence; see
[LICENSE-ASSETS.md](https://github.com/VoltageFoundryMod/ForgeSeries/blob/main/LICENSE-ASSETS.md).

---

Thank you for choosing the ClockForge module. We hope it enhances your musical creativity and performance.

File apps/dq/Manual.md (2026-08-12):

# NoteForge - A Dual Quantizer Eurorack Module



## Introduction

NoteForge quantizes analog control voltages into musical notes. It has two fully
independent quantizers: each takes a pitch CV, snaps it to a scale you can edit
note by note, and emits a quantized CV plus a gate or envelope.

Part of the **Forge** series of modules, which share a single hardware platform
based on the Seeed XIAO RP2040. The hardware schematics and design files are
open-source and available in the
[hardware repository](https://github.com/VoltageFoundryMod/ForgeSeries-Hardware).

NoteForge also runs as a **VCV Rack plugin** — not a reimplementation, but the
actual firmware running inside Rack with the OLED emulated pixel for pixel. See
[docs/VCVRack_Plugin.md](docs/VCVRack_Plugin.md).

NoteForge Module

Check it out on [ModularGrid](https://modulargrid.net/e/voltage-foundry-modular-noteforge).

## Features

- Two independent quantizers, each with its own 12-note scale mask
- 15 built-in scales in any root, plus free per-note editing on the keyboard screen
- 12-bit quantized CV output on both channels (0–5 V, 1V/oct, 5 octaves)
- Boundary hysteresis so a CV resting on a note edge never chatters
- Per-channel gate/envelope output: AD envelope, fixed trigger, or gate
- Sync on trigger input, on note change, or both
- Per-channel octave shift, glide (portamento) and a note settle window
- Settle suppresses the notes an input sweeps through between two pitches
- Per-channel sample & hold: latch the note on a trigger and ignore the input between them
- IN 2 can become a transposition CV, stepping both channels in scale degrees
- 10 preset slots, with slot 0 loaded automatically at power-on
- Two-point CV input and output calibration wizard
- OLED display and rotary encoder for everything

## Interface

| Jack | Direction | Meaning |
| --- | --- | --- |
| TRIG | in | Trigger input (0–5 V) |
| IN 1 | in | Pitch CV for channel 1 (0–5 V) |
| IN 2 | in | Pitch CV for channel 2, or transposition CV (0–5 V) |
| OUT 1  | out | Quantized CV, channel 1 (12-bit, 0–5 V) |
| OUT 2  | out | Quantized CV, channel 2 (12-bit, 0–5 V) |
| GATE 1 | out | Gate / envelope, channel 1 (0–5 V) |
| GATE 2 | out | Gate / envelope, channel 2 (0–5 V) |

## Getting Started

1. Connect the module to a suitable power source and power it on.
2. The display shows a splash screen, then the module name and version.
3. Settings load from preset slot 0. On a fresh module that means channel 1
   chromatic and channel 2 in C major.
4. Patch a pitch CV into IN 1 and take the quantized result from OUT 1.

## Using the Module

### The keyboard screen (home)

The home screen shows one piano keyboard per channel:

- **Filled key** — the note is in the channel's scale.
- **Outlined key** — the note is excluded; incoming CV never lands on it.
- **Dotted key** — the note the channel is playing right now.

The column on the right of each keyboard shows the selected scale, the root and
octave offset, and the live note. The live note is drawn inverted while that
channel's gate/envelope is running.

Turning the encoder walks across the 12 keys of channel 1, then the 12 keys of
channel 2 — the arrow between the keyboards points up at a channel 1 key and
down at a channel 2 key. **Click to toggle** the note under the cursor. Keep
turning past the last key to reach the menu pages.

### Menu pages

Turning the encoder past the keyboards steps through:

| Page | Contents |
| --- | --- |
| SCALES | Scale and root per channel |
| CH1 PITCH | Mode, octave, settle and glide for channel 1 |
| CH2 PITCH | The same for channel 2 |
| CH1 GATE  | Mode, attack, decay, sync and level for channel 1 |
| CH2 GATE  | The same for channel 2 |
| ROUTING | IN 2 role, transpose range, and per-channel transpose enables |
| SETTINGS  | Screen timeout, boot menu |
| PRESETS | Preset slot, save, load, load defaults |

A **hollow arrow** means the row is selected; **click** to start editing and the
arrow fills in. Turn to change the value, click again to confirm. Spinning the
encoder quickly accelerates the change. A dot in the top-left corner means there
are unsaved changes.

The screen returns to the keyboard after the configured timeout (default 5 s,
disable it on the SETTINGS page).

### Choosing a scale

Changing **SCALE** or **ROOT** on the SCALES page writes straight into that
channel's note mask — there is nothing to confirm. Scrolling through the scales
with a CV patched is therefore audible: you hear each one as you land on it, and
the keyboard screen redraws to match.

The note mask stays the source of truth for what the quantizer plays, so you are
free to toggle individual keys on the keyboard screen afterwards and build
something that is not a named scale at all. The trade-off is that touching SCALE
or ROOT again rebuilds the mask and replaces those manual edits — so hand-edit
_after_ picking the scale, not before.

If you switch every note off, the channel falls back to chromatic rather than
freezing — the sounding note is marked with a small dot so it is obvious what
happened.

### Gate and envelope

Each channel drives its GATE jack in one of three modes:

- **ENV** — attack/decay envelope, retriggerable. Attack 0–2000 ms, decay
  0–4000 ms.
- **TRIG** — a fixed 10 ms pulse at full level, for clocking other modules.
- **GATE** — follows the TRIG input level directly.

**SYNC** decides what fires it:

- **TRIG** — a rising edge at the TRIG input.
- **NOTE** — the quantized note changed.
- **BOTH** — either.

`LEVEL` scales the output from 0–100 %.

### Pitch controls

- **MODE** — `TRACK` or `S&H`. See below.
- **OCT** — shifts the output ±3 octaves, applied after quantization, so the
  result always stays in the scale.
- **GLIDE** — portamento between notes, 0–100 % (up to a 500 ms time constant).
- **SETTLE** — 0–50 ms. How long a new note has to hold before the output plays
  it. See below.

#### Why SETTLE exists

When the input jumps between two distant notes it does not arrive at the ADC as
a clean step: the input smoothing takes a few loop iterations to converge, and a
quantizer that simply follows its input plays every note it crosses on the way.
That is heard as a short sweep up to the target note rather than a clean jump.

SETTLE requires a new note to hold for a given time before the output follows.
The transient notes are each held for well under a millisecond, so none of them
survives the window and the output steps straight from the old note to the new
one. An input that genuinely _is_ moving slowly still plays every note it passes
through, because each one holds for longer than the window — so this is a
de-glitcher, not a slew limiter.

The default is 5 ms. Set it to 0 for the old immediate-follow behaviour, or
raise it if your source is noisy or slewed.

> This replaces the SENS (sensitivity) control from earlier firmware. SENS was a
> gain trim on the incoming pitch CV, which is the wrong tool once the
> calibration wizard has fitted the input scale properly — any setting other than
> unity detunes the module and makes it quantize to the wrong note.

### Sample & hold

Each channel's pitch **MODE** decides _when_ the output is allowed to move:

- **TRACK** — follow the input continuously, subject to the settle window.
- **S&H** — latch the quantized note on a rising edge at TRIG and hold it until
  the next one.

In `S&H` nothing the input does between triggers reaches the jack: no sweeps, no
drift from a slewed source, no chatter from a noisy one. It is the unconditional
version of what SETTLE does statistically, and it is what you want when the
pitch comes from something that moves continuously — an LFO, a slew limiter, a
hand on a joystick.

SETTLE keeps working in this mode, as the _sample delay_. A sequencer puts out
its pitch and its gate at the same instant, so at the moment of the trigger the
pitch CV may still be in transit; SETTLE is how long the module waits after the
edge before believing what it reads. The default 5 ms is a good starting point.

The first reading after power-on is latched immediately, so the module is never
silent waiting for a trigger that has not arrived yet.

### Transposition (IN 2)

On the ROUTING page, **IN2 ROLE** hands IN 2 over to a transposition CV:

- **PITCH** (default) — IN 2 is channel 2's pitch input; normal dual quantizer.
- **TRANSP** — IN 2 becomes a transposition CV, and **channel 2 quantizes IN 1**
  alongside channel 1.

That second part is the point of the mode: rather than losing a quantizer, you
get two voicings of the same melody — different scales, octaves and envelopes on
each channel — transposed together in real time.

**TR RANGE** sets how far the CV reaches: `+7`, `+12`, `-7/+7` or `-12/+12`, in
scale degrees. **CH1 TRANSP** and **CH2 TRANSP** decide which channels follow
it; transposing only channel 2 against a static channel 1 is often the most
musical setting.

Transposition is measured in **scale degrees, not semitones**. +2 degrees in a
major scale is a third; in a pentatonic scale it is a fourth. The result is
therefore always a note of the scale, which semitone transposition could not
guarantee. Transposing past either end of the range clamps rather than wrapping,
so a small change in CV never produces a multi-octave jump.

The unipolar ranges are listed first and `+7` is the default deliberately: at
0 V they transpose by nothing. The hardware has no switched jacks and cannot
tell an unpatched input from one sitting at 0 V, so the safe rest state is "no
transposition" rather than "transposed all the way down".

While a channel is following the transpose CV, the second line of its keyboard
info column shows the live transposition (`T+3`) in place of the root and
octave — a mode that rewrites every note should never be invisible.

### Presets

The PRESETS page has 10 slots. Pick a slot, then `SAVE` or `LOAD`. Slot 0 is
loaded automatically at power-on. `LOAD DEFAULTS` restores the factory settings
into the live state but does not write them to flash, so a mis-click is undone by
loading your slot again.

### Switching modules

`BOOT MENU` on the SETTINGS page hands the hardware back to the module selector,
so you can run a different Forge module — or the calibration wizard — without
power-cycling. NoteForge flushes anything it owes to flash first, then the module
reboots into the selector. Holding the encoder for two seconds does the same
thing from anywhere in the menu.

## Calibration

Pitch accuracy is the entire job of a quantizer, so calibration matters more here
than on other modules: an uncalibrated ADC gain error drifts the output off by a
semitone or more toward the top of the range.

**Hold the encoder button while powering on** to open the module selector, then
pick **CALIBRATE** at the bottom of the list. From a running module the same
screen is one click away under **SETTINGS → BOOT MENU** (or hold the encoder for
two seconds). The six-step wizard:

1. All outputs go to full scale — adjust each on-board trimmer until the jack
   reads 5.00 V on a multimeter.
2. All outputs go to the ideal 1 V code — measure each jack (named OUT 1 – OUT 4,
   which are NoteForge's CV 1, CV 2, GATE 1, GATE 2) and dial the reading in with
   the encoder. This captures the op-amp offset the trimmer leaves.
3. – 6. Apply an external 1 V and then 3 V reference to each CV input and click
   when the reading is stable.

The result is stored in `/cal.bin`, separately from the preset slots, and
**survives firmware updates**. Calibration describes the board rather than any
one module, so a single run covers all of them and you only need to re-run it if
the hardware changes.

## Firmware Update

1. Download the latest firmware from the Releases section of the [GitHub repository](https://github.com/VoltageFoundryMod/ForgeSeries/releases). The firmware file is named `CURRENT.UF2`.
2. Connect the module to your computer using a USB-C cable while holding the small BOOT (B) button. The CPU can be removed from the module as it's socketed to the main board if desired. Firmware loading can be done with the CPU removed.
3. A new drive will show on your computer named RPI-RP2. Copy and overwrite the `CURRENT.UF2` file to the module USB drive. After copy is finished, the module will reboot and the new firmware will be loaded.

XIAO RP2040 MCU

## Troubleshooting

### No output on CV 1 / CV 2

- Check the input CV is within 0–5 V; anything below 0 V reads as 0.
- Check the channel has at least one note enabled (all-off falls back to chromatic).
- Check the octave shift hasn't pushed the output against the end of the range.

**Notes are wrong near the top of the range** — run the calibration wizard.

**The output jumps between two notes** — that is what the hysteresis exists to
prevent, so it usually means the input itself is moving. Try a small amount of
glide, or check the source for noise.

**Gate never fires** — check `SYNC`. In `TRIG` mode nothing happens without a
trigger; in `NOTE` mode nothing happens until the note actually changes. `GATE`
mode ignores note changes entirely and only follows the TRIG input.

**Display is blank / module halts at boot** — the display and DAC are both
required. The module shows an I2C error screen if the MCP4728 is missing, and
blinks the on-board LED if the display itself failed to start.

## Powering

The module uses only 5V internally. This can be provided directly by a Eurorack supply with a 5V rail, or taken from the 12V line and converted to 5V on-board. The source is selected with an on-board jumper: closing the center pin to **INT REG** takes power from the Eurorack 12V supply, while closing the center pin to **EURO** takes power from the 5V rail (requires a 16-pin cable). It can also be powered from the USB-C jack on the microcontroller board.

**Never connect both the Eurorack power and the USB-C power at the same time**. The module might be damaged or even damage your computer if both are connected. The module is designed to be powered from either source, not both.

## Specifications

- **Processor**: Seeed XIAO RP2040 (dual-core Cortex-M0+)
- **DAC**: MCP4728 quad 12-bit
- **Power Supply**: 12 V or 5 V, jumper selectable
- **Input CV Range**: 0–5 V
- **Output CV Range**: 0–5 V, 1V/oct, 5 octaves
- **Dimensions**: 6HP
- **Depth**: 40 mm
- **Current Draw**: 60 mA @ +12 V or +5 V

## Development

See [AGENTS.md](AGENTS.md) for the architecture, build and test instructions, and
[docs/VCVRack_Plugin_Development.md](docs/VCVRack_Plugin_Development.md) for how
the same firmware is compiled into a VCV Rack plugin.

```bash
pio run             # build the RP2040 firmware
pio test -e native  # run the unit tests
```

## Contact

For support and inquiries, please open an issue on the
[GitHub repository](https://github.com/VoltageFoundryMod/ForgeSeries/issues).

## License

Source code is GPL-3.0-or-later — see the
[LICENSE](https://github.com/VoltageFoundryMod/ForgeSeries/blob/main/LICENSE) in the source repository.

Panel designs, graphics, module names and the Voltage Foundry Modular brand are
copyright and are not covered by that licence; see
[LICENSE-ASSETS.md](https://github.com/VoltageFoundryMod/ForgeSeries/blob/main/LICENSE-ASSETS.md).

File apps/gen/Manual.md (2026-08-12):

# GravityForge: Sequencing by Falling



## Overview

GravityForge is a dual physics-based generative sequencer. Two virtual containers hold bouncing balls; gravity pulls them down, the containers rotate, and every time a ball strikes a peg on a container wall it plays a note. A single **PROXIMITY** control slides the two containers together, taking them from independent sequencers, through overlapping-and-coupled, to a single merged space.

Part of the **Forge** series of modules which share a single hardware platform. Most of this manual applies to both the hardware and the VCV Rack plugin, with the exception of hardware-specific topics like calibration, powering and firmware update.

GravityForge Module

Check the module on [ModularGrid](https://modulargrid.net/e/voltage-foundry-modular-gravityforge).

---

## User Manual

- [GravityForge: Sequencing by Falling](#gravityforge-sequencing-by-falling)
  - [Overview](#overview)
  - [User Manual](#user-manual)
  - [How it works](#how-it-works)
  - [Jacks](#jacks)
  - [Operation](#operation)
    - [Interface](#interface)
    - [The physics screen](#the-physics-screen)
    - [Menu pages](#menu-pages)
  - [Parameters](#parameters)
    - [Clock](#clock)
    - [Loop](#loop)
    - [Coupling](#coupling)
    - [Physics (per container)](#physics-per-container)
    - [Notes (per container)](#notes-per-container)
    - [Gate (per container)](#gate-per-container)
    - [CV Input Modulation](#cv-input-modulation)
    - [Settings](#settings)
    - [Presets](#presets)
  - [Working with the module](#working-with-the-module)
    - [What you hear out of the box](#what-you-hear-out-of-the-box)
    - [Getting a first sequence](#getting-a-first-sequence)
    - [Using proximity musically](#using-proximity-musically)
    - [Taming or thickening the density](#taming-or-thickening-the-density)
    - [Slow, ambient patterns](#slow-ambient-patterns)
    - [Keeping a phrase](#keeping-a-phrase)
    - [Locking to a grid](#locking-to-a-grid)
    - [External clock sync](#external-clock-sync)
    - [Muting pegs](#muting-pegs)
    - [Randomize](#randomize)
    - [Save/Load Configuration](#saveload-configuration)
  - [VCV Rack Plugin](#vcv-rack-plugin)
  - [Hardware Calibration](#hardware-calibration)
    - [What you need](#what-you-need)
    - [Running calibration](#running-calibration)
  - [Firmware Update](#firmware-update)
  - [Troubleshooting](#troubleshooting)
  - [Powering](#powering)
  - [Specifications](#specifications)
  - [Contact](#contact)
  - [License](#license)

## How it works

Each container is a circle with a ring of **pegs** on its wall and a number of **balls** inside it. Gravity accelerates the balls downward; the container rotates and drags the balls along with it through friction at the wall (**GRIP**), and each impact loses some energy (**BOUNCE**).

When a ball hits the wall hard enough, the peg at that point of the rim fires:

- the **CV output** of that container jumps to the pitch of that peg;
- the **GATE output** of that container fires an envelope, trigger or gate.

Pegs are laid out around the ring in ascending pitch, so where the ball lands determines the note. Every peg is a degree of the selected scale, so nothing can play out of key.

Nothing is stepped by the clock: the physics always free-runs, and the notes land where the balls land. The clock only sets how fast the containers rotate and, optionally, provides a grid the notes can be deferred onto.

Container A drives OUT 1 and OUT 3; container B drives OUT 2 and OUT 4.

## Jacks

| Jack  | Direction | Signal |
| ----- | --- | --- |
| IN 1  | Input | Trigger/gate input. Role selectable: CLOCK, RESET, KICK or SPAWN |
| IN 2  | Input | Assignable CV modulation (0–5 V) |
| IN 3  | Input | Assignable CV modulation (0–5 V) |
| OUT 1 | Output | **CV A** — pitch of the last peg hit in container A |
| OUT 2 | Output | **CV B** — pitch of the last peg hit in container B |
| OUT 3 | Output | **GATE A** — envelope / trigger / gate for container A |
| OUT 4 | Output | **GATE B** — envelope / trigger / gate for container B |

The jack map is deliberately identical to NoteForge, so it stays muscle memory across the series.

CV outputs follow the usual 1V/oct convention within the module's 0–5 V range, which is why the pitch span is centred and limited to five octaves.

Which notes those volts _are_ depends on the oscillator you patch into, so tell the module: **SETTINGS ▸ 0V NOTE** names the note its 0 V stands for (default `C4`, VCV Rack's convention and the common one on hardware VCOs). The module's range is then `C4` at 0 V up to `C9` at 5 V, and the notes on the home screen are the ones you hear. It only renames the shown note — the voltage on the jack never moves.

## Operation

### Interface

The module is driven entirely from the rotary encoder:

- **Turn** (while navigating): move between parameters. Crossing a group boundary changes the page.
- **Click** on a value parameter: enter edit mode. The value is now changed by turning the encoder.
- **Click** again: leave edit mode.
- **Click** on an action row (RESET BALLS, KICK, SAVE, LOAD, RANDOM, BOOT MENU): execute it immediately.
- **Click** on a toggle row (DIR): flip it immediately.

Turning the encoder quickly accelerates the step size (up to 8× for a fast spin), so long ranges like BPM or DECAY can be crossed without a lot of turning. Reversing direction always resets to single steps.

A small dot in the top-left corner means the current settings differ from the saved preset. The line on the right edge of the screen shows where you are in the whole parameter list.

If **TIMEOUT** is set, the display returns to the physics screen after that many seconds of inactivity. The timeout does not apply while a parameter is in edit mode.

### The physics screen

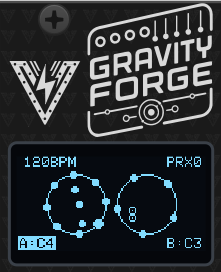
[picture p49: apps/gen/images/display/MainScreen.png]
Main Screen


The home screen is the simulation itself, not an illustration of it:

- **Top left**: the tempo. An `E` after the number means an external clock is actually running into IN 1.
- **Top right**: `PRX` and the current proximity percentage.
- **Middle**: the two containers. Container A's balls are drawn filled, container B's hollow, so they stay tellable apart when proximity merges the two circles into one space.
- **On the rims**: pegs. A solid dot is an active peg, a small hollow ring is a muted one, and a peg flashes larger for a few frames when it fires.
- **Bottom**: the live note of each channel (`A:` and `B:`). The label is inverted while that channel's gate is up.
- **Expanding rings**: a coupling spark — a strike in one container that transmitted into the other. This is the cue that tells you the containers are actually talking to each other.

### Menu pages

Turning the encoder from the home screen walks through the pages in this order:

| Page | Contents |
| --- | --- |
| **HOME** | The physics view |
| **CLOCK** | BPM, clock divider, quantize grid, IN 1 role |
| **COUPLING**  | Proximity, couple amount, reset balls, kick |
| **A PHYSICS** | Gravity, bounce, grip, spin, direction, ball count |
| **B PHYSICS** | Same, container B |
| **LOOP** | Phrase length, nap/wake, per-container shift |
| **A NOTES** | Scale, root+octave, spread, bias, pegs, density |
| **B NOTES** | Same, container B |
| **A GATE** | Mode, attack, decay, level, accent, space |
| **B GATE** | Same, container B |
| **CV IN** | IN 2 / IN 3 destination and depth |
| **SETTINGS**  | The note at 0 V, screen timeout, boot menu |
| **PRESETS** | Preset slot, save, load, randomize |

## Parameters

### Clock

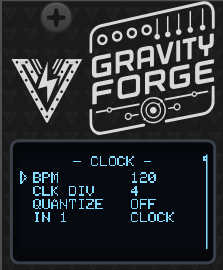
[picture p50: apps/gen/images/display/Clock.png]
Clock page


- **BPM** — Internal tempo, 20 to 300. This sets the container rotation rate and the quantize grid. When an external clock is live, the screen shows the derived tempo with an `E`, and this setting is what the module falls back to when the external clock stops.
- **CLK DIV** — How many pulses per quarter note the external clock at IN 1 sends: 1, 2, 4, 8 or 24. Use 4 for the common 16th-note Eurorack clock, 1 for a clock that already emits quarter notes.
- **QUANTIZE** — The grid that peg hits are deferred onto: `OFF`, `1/4`, `1/8`, `1/16`, `1/8T`, `1/16T`. See [Locking to a grid](#locking-to-a-grid).
- **IN 1** — What the trigger input does:
  - **CLOCK** — External clock. Tempo is derived from the interval between edges.
  - **RESET** — Re-places all balls and zeroes the rotation on every rising edge.
  - **KICK** — Applies an impulse to every ball, shaking both containers.
  - **SPAWN** — Adds a ball to both containers on each pulse, wrapping back to one after the maximum of eight.

### Loop

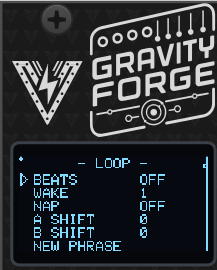
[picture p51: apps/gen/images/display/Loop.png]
Loop page


The simulation is deterministic: the same state, stepped the same number of
times, produces the same notes. Loop mode uses that to keep a phrase — it
snapshots the balls, the rotation and the random generator, and puts them back
every _N_ beats. What was an endless stream becomes something that repeats.

- **BEATS** (`OFF`, 1–64) — Length of the phrase in beats. `OFF` is the default
  and free-running is the module's normal state; set a length when you hear
  something worth keeping. The rewind lands on an exact simulation step, so the
  phrase repeats note for note rather than drifting apart after a few passes.
- **WAKE** (1–16) — How many loops a container plays before it naps.
- **NAP** (`OFF`, 1–16) — How many loops it then stays silent for. `OFF` means it
  never naps. The simulation keeps running through a nap — only the output is
  muted — so the phrase stays in phase and comes back exactly where it left off.
- **A SHIFT / B SHIFT** (0–16) — Offset each container's position in the
  wake/nap cycle. This is what turns nap/wake from an on-off stutter into
  call-and-response; see [Keeping a phrase](#keeping-a-phrase).
- **NEW PHRASE** — Throw the captured phrase away and keep whatever the balls are
  doing right now. The loop is a lottery, and this is the re-roll.

While a loop is running, the home screen shows `L n/N` — the beat you are on and
the phrase length. A napping channel shows `zz` instead of its note.

Changing **BEATS** captures a new phrase immediately. A _tempo_ change does not:
the new length is picked up at the next loop boundary, so the phrase always ends
where it started even while the BPM is moving.

Everything else stays live over the top of a locked phrase. Gravity, proximity,
the peg mutes, the scale and all CV modulation still apply — the loop rewinds the
motion, not the settings. Changing **SCALE** re-registers the phrase without
touching its rhythm.

### Coupling

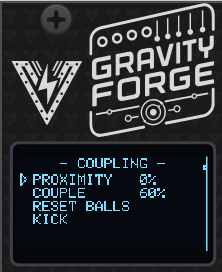
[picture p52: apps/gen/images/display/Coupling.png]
Coupling page


- **PROXIMITY** (0–100 %) — Slides the two containers together. At 0 % they sit apart and are completely independent. As it rises they overlap, and a wall strike whose contact point falls inside the other container transmits energy into it **and rings the peg nearest that point on the receiving rim**. At 100 % they are fully merged into one shared space.

  The transmitted note is always the _receiving_ container's own peg — its scale, its root, its spread and bias, its mutes — so a transfer can never sound out of key. Muting a peg absorbs the transfer silently, which is how you choose which transfers speak.

- **COUPLE** (0–100 %) — How strongly a transmitted collision arrives. Low values only nudge trajectories; the containers begin audibly answering each other as this comes up. Proximity decides _whether_ they touch; couple decides _how hard_.
- **RESET BALLS** — Re-place all balls at their starting positions and zero the rotation.
- **KICK** — Give every ball a random impulse. Useful when a patch has settled into something too regular, or to restart motion after a very low gravity setting.

Note that both containers stay separate instruments even when merged: each keeps its own gravity, scale, peg ring and outputs. This is energy transfer, not ball transfer, so the ball count in each container never drifts.

### Physics (per container)

Physics page

- **GRAVITY** (5–900) — The container's tempo control. Gravity scales the whole simulation in _time_: the balls trace the same paths and strike the same pegs, they just take longer to get there. It changes _how often_ pegs are struck, not how hard.

  With three balls, measured:

  | GRAVITY | Notes per second | Average gap |
  | ------- | ---------------- | ----------- |
  | 5       | 0.9              | 1080 ms     |
  | 30      | 2.3              | 440 ms      |
  | 120     | 4.6              | 220 ms      |
  | 220     | 6.2              | 160 ms      |
  | 600     | 10.2             | 100 ms      |
  | 900     | 12.6             | 80 ms       |

  Fewer balls thins it further — a single ball at GRAVITY 5 speaks about once every three seconds, which is where the slow ambient settings live.

  Note that a fast **SPIN** competes with this. The rotating wall is its own energy source and does not scale with gravity, so at SPIN `1` or `1/2` the wall is stirring the container harder than gravity is pulling on it and GRAVITY loses most of its authority over the density. SPIN `4` and slower leave it in charge.

- **BOUNCE** (10–98 %) — How much energy survives an impact. High values keep the balls lively and the pattern busy; low values let them settle toward the bottom of the container and tick along more sparsely.
- **GRIP** (0–100 %) — How much of the rotating wall's motion is transferred to a ball on contact. This is what makes a rotating container actually stir the balls instead of just spinning a decorative ring behind them. At 0 % rotation only moves the pegs under the balls; at high values the balls get carried around the rim.
- **SPIN** — Rotation rate in **beats per revolution**: `1/2`, `1`, `2`, `4`, `8`, `16`. Tied to the clock, so rotation stays musically related to the patch. Faster spin sweeps the peg ring under the balls more quickly and moves the melody around more.
- **DIR** — `FWD` or `REV`. Reversing one container against the other is an easy way to make two containers with identical settings behave differently.
- **BALLS** (1–8) — How many balls are in the container. More balls means a denser pattern and more coupled hits, at the cost of predictability.

### Notes (per container)

Notes page

- **SCALE** — One of 15 scales: Chromatic, Major, Minor, Dorian, Phrygian, Lydian, Mixolydian, Locrian, Pentatonic Minor, Pentatonic Major, Harmonic Minor, Melodic Minor, Whole tone, Diminished, Blues.
- **ROOT** (`C4` … `B8`) — The root note _with its octave_, and the note the peg ring starts on. This is the container's register: the ring opens upward from here, so `ROOT C4` puts the channel at the bottom of the module's range and `ROOT C7` puts it near the top. One detent is a semitone; spin faster to cover octaves. The octave shown follows **0V NOTE**, so it is the note your oscillator plays.

  The ceiling depends on SPREAD, since the whole ring has to fit under 5 V: a 2-octave ring stops at `C7`, a 5-octave ring can only start at `C4`. Widening SPREAD walks ROOT down rather than letting the top of the ring flatten out.

- **SPREAD** (1–5 oct) — How many octaves the peg ring covers, counted upward from ROOT, independent of the peg count. `ROOT C4` + `SPREAD 2` gives a ring from C4 to C6 (0–2 V); `SPREAD 5` uses the whole 0–5 V range.
- **BIAS** (`LO100` … `EVEN` … `HI100`) — Where inside that span the notes crowd. `EVEN` spaces the pegs evenly; `LO` bunches them into the low notes, `HI` into the high ones. The lowest and highest pegs never move, so SPREAD keeps meaning exactly what it says.

  With 8 pegs in C major, `ROOT C4` and SPREAD 2:

  | BIAS    | Notes around the ring   |
  | ------- | ----------------------- |
  | `EVEN`  | C4 E4 G4 B4 D5 F5 A5 C6 |
  | `LO100` | C4 D4 E4 F4 G4 A4 C5 C6 |
  | `HI100` | C4 C5 E5 F5 G5 A5 B5 C6 |

- **PEGS** (3–16) — How many pegs are on the ring. Fewer pegs means bigger intervals between neighbouring notes and a more angular melody; more pegs means smaller steps and a more scalar one. Changing the count re-maps every peg's pitch, since the count is what decides where each peg falls within SPREAD.
- **DENSITY** (0–100 %) — The chance that a strike actually speaks. At 100 % every valid hit becomes a note, which is the module's original behaviour. Lower it and notes drop out at random while the balls carry on exactly as before — this is the only thinning control that leaves the motion untouched, so the screen stays as lively as it was and only the output gets sparser. At 0 % the container is silent but still bouncing, still coupling and still driving the display.

ROOT, SPREAD and BIAS between them say exactly where every peg is: where the ring starts, how far it reaches, and how the notes bunch inside it. Nothing is inferred — earlier firmware centred the ring in the output range, which parked a one-octave ring two octaves up with no way to move it.

**0V NOTE** is not a fourth pitch control: it renames the range, it does not move it.

### Gate (per container)

Gate page

- **MODE**
  - **ENV** — An AD envelope: attack up, then decay. Retriggered by every hit.
  - **TRIG** — A fixed 10 ms pulse at full level on every hit. Use this to drive drums or anything that only wants a clean trigger.
  - **GATE** — Follows the level at IN 1, ignoring the hits. Useful when you want an external gate to shape the voice.
- **ATTACK** (0–2000 ms) — Envelope attack time. Zero gives an instant onset.
- **DECAY** (0–4000 ms) — Envelope decay time. Keep this shorter than the gap between hits, or the envelope never returns to zero and the output stops behaving like a gate. At factory settings a container fires roughly six times a second, which is why the default decay is 100 ms. **SPACE**, below, is how you buy room for a longer one.
- **LEVEL** (0–100 %) — Gate output level, 100 % being 5 V.
- **ACCENT** (0–100 %) — How much a ball's impact speed scales the gate level. At 0 % every hit is the same height; at high values soft grazes come out quiet and hard strikes come out full. Accent applies in ENV mode only — a trigger pulse has to keep a fixed height or downstream modules will start missing it.
- **SPACE** (`OFF`, `1/4`, `1/2`, `1`, `2`, `4`, `8` beats) — A minimum gap between two notes from this container. A note arriving sooner than the gap is dropped; one arriving later plays the instant it happens. It follows the tempo, so the spacing moves with the BPM.

  This is a rate _ceiling_, not a grid — it never moves a note, so the rhythm stays as human as the physics made it, just sparser. **QUANTIZE** on the CLOCK page is the control that snaps notes onto a grid, and the two work together: QUANTIZE decides where notes may land, SPACE decides how close together they may land.

  SPACE is also what makes long decays usable. At `1` beat and 90 BPM nothing can arrive less than 660 ms apart, so a 500 ms decay always finishes.

### CV Input Modulation

CV page

IN 2 and IN 3 each have a **DEST** (destination) and a **DEPTH** (0–100 %). Depth 0 means the input does nothing, so a patched cable never changes anything until you dial some in.

| Destination | Effect |
| --- | --- |
| `OFF` | Input unused |
| `GRAV A` | Gravity trim, container A |
| `GRAV B` | Gravity trim, container B |
| `GRAV AB` | Gravity trim, both containers |
| `SPIN A` | Rotation rate multiplier, container A |
| `SPIN B` | Rotation rate multiplier, container B |
| `SPIN AB` | Rotation rate multiplier, both containers |
| `BOUNCE` | Bounce trim, both containers |
| `BALLS` | Ball count, both containers |
| `PEGS A` | Peg count, container A |
| `PEGS B` | Peg count, container B |
| `PROX` | Proximity |
| `COUPLE` | Coupling amount |
| `DENS A` | Density, container A |
| `DENS B` | Density, container B |
| `DENS AB` | Density, both containers |

The **trim** targets (gravity, spin, bounce) are bipolar: 2.5 V is no change, below that subtracts and above that adds. The **amount** targets (balls, pegs, proximity, couple, density) are unipolar: 0 V adds nothing and 5 V adds the full depth on top of the menu setting.

Modulation is always applied _on top_ of what you set in the menu, never written into it — the menu keeps showing your setting and presets store your setting, not this instant's CV value.

Spin is modulated as a continuous multiplier rather than by stepping through the beats-per-revolution list, so a CV sweep glides the rotation instead of jumping between ratios.

`PROX` on a slow LFO is the single most rewarding patch on this module: the containers drift in and out of each other's reach and the two voices go from independent to entangled and back.

`DENS AB` on a slow LFO is the second: set DENSITY low in the menu and let the CV open the containers up, and the patch breathes between near-silence and a full run without the motion on screen changing at all. Put `DENS A` and `DENS B` on out-of-phase LFOs and the two voices hand off to each other.

### Settings

Settings page

- **0V NOTE** (`C0`–`C5`, default `C4`) — Which note the module should _call_ its 0 V. The row shows the note and the range that follows from it:

  ```text
  0V NOTE   C4   C4-C9
  ```

  This is a display preference — the modular equivalent of a DAW asking whether middle C is called C3 or C4. **It changes no voltage and no sound.** The outputs are 0–5 V at every setting; all it decides is what the home screen, the ROOT row and the Rack menu call them.

  Set it to whatever the oscillator you are patched into calls 0 V (`C4` in VCV Rack and on most hardware VCOs) and every note name on the module becomes the note you actually hear. If you tune by ear and never look at the note names, you can ignore this row entirely.

  The control that _moves_ the pitch is **ROOT**, on the NOTES page.

- **TIMEOUT** — Return to the physics screen after `OFF`, `2s`, `5s`, `10s` or `20s` of inactivity.
- **BOOT MENU** — Hand the hardware back to the module selector, so you can run a different Forge module — or the calibration wizard — without power-cycling. GravityForge flushes anything it owes to flash first, then the module reboots into the selector. Holding the encoder for two seconds does the same thing from anywhere in the menu.

### Presets

- **SLOT** (0–9) — The preset slot that SAVE and LOAD act on.
- **SAVE** — Write the current settings to the selected slot.
- **LOAD** — Recall the selected slot.
- **RANDOM** — Roll a whole new patch. See [Randomize](#randomize). It sits here rather than under Settings because, like LOAD, it replaces the whole patch — it just rolls the new one instead of reading it from a slot.

## Working with the module

### What you hear out of the box

The factory patch is deliberately **two different instruments**, one per container, with PROXIMITY at 0 so they run independently. Patch both pairs of jacks and you have the module's whole range in front of you before you change anything:

| | **A** — OUT 1 / OUT 3 | **B** — OUT 2 / OUT 4 |
| --- | --- | --- |
| Character | The sequencer | The ambient voice |
| Rate | ~6 notes/sec | ~1 note every 2 s |
| Notes | C major, `ROOT C4`, two octaves | C pentatonic major, `ROOT C6`, one octave — on top of A, not inside it |
| Physics | GRAVITY 220, 3 balls, SPIN 8 | GRAVITY 20, 1 ball, SPIN 16 |
| Gate | 100 ms decay | 120 ms attack, 750 ms decay |
| Thinning  | none | DENSITY 85 %, SPACE `2` |

B is the worked example for everything in [Slow, ambient patterns](#slow-ambient-patterns) below — its settings are exactly what that section builds, so you can read the recipe off the menu pages rather than typing it in. Its scale is a subset of A's on purpose: the two containers drift into every possible alignment, so B's notes have to be ones that cannot clash with A's whatever lands together.

Then turn **PROXIMITY** up. With the containers this far apart in character it is the most rewarding control on the module — A's busy strikes start shaking notes out of B's slow one.

### Getting a first sequence

From the factory patch:

1. Set **SCALE** and **ROOT** on the A NOTES and B NOTES pages. Give the two containers different roots a fifth apart for an easy two-voice patch.
2. Set **PEGS**. Around 5–8 gives clear melodic movement; 12–16 gives something closer to a run.
3. Set **SPREAD** to choose the register width, then **BIAS** if you want the melody to sit low or high inside it.
4. Adjust **GRAVITY** and **BALLS** on the physics pages until the density feels right.
5. On the GATE pages, pick **ENV** for pitched voices or **TRIG** for drums, and set **DECAY** shorter than the gaps between notes.

### Using proximity musically

PROXIMITY is a continuous gradient, and the useful territory is the middle of it:

- **0 %** — Two independent sequencers sharing a screen.
- **20–60 %** — The containers overlap. Strikes near the shared area transmit, so occasional notes appear in one container that were caused by the other. This is where the two voices start sounding like they are listening to each other.
- **100 %** — One merged space. Density roughly doubles, and both channels ring almost continuously.

If it appears to be doing nothing, check that **COUPLE** is above about 50 % — below that the transmitted energy nudges the balls but is not hard enough to ring a peg. The expanding spark rings on the physics screen tell you a transfer actually happened.

### Taming or thickening the density

Every hit is one note, and at factory settings a container fires about six times a second. Five controls thin it out, and they are not interchangeable — each gives up something different:

| Control | What it does | What else changes |
| --- | --- | --- |
| **DENSITY** | Drops notes at random | Nothing — the motion is identical |
| **SPACE** | Enforces a minimum gap | Nothing — the motion is identical |
| **GRAVITY** | Slows the whole simulation down | The balls visibly slow too |
| **BALLS** | Fewer sources of hits | Less interplay, more predictable  |
| **PEGS** | Fewer pegs on the ring | Wider intervals in the melody |

DENSITY and SPACE are the two that leave the simulation alone — the screen looks exactly as busy as it did and only the output thins. They compose cleanly: SPACE puts a ceiling on the rate, DENSITY thins whatever got through. At SPACE `1` and DENSITY 50 % you get at most one note per beat, and roughly half the beats speak.

Muting pegs is a sixth route — a muted peg still bounces the ball, it just does not speak — but it also decides _which_ notes survive rather than how many.

To thicken instead: more balls, higher gravity and bounce, faster **SPIN**, and more proximity.

### Slow, ambient patterns

Container **B** already ships this way, so the fastest way to learn it is to walk the B pages and read what each control is doing. Building it from scratch on A:

1. **A PHYSICS** — GRAVITY 20, BALLS 1, BOUNCE 45 %. One slowly falling ball. GRAVITY is doing the real work here: it rescales the whole simulation in time, so this is about a third of the default tempo. Keep **SPIN** at `8` or slower — the rotating wall is an energy source that does _not_ scale with gravity, so a fast spin stirs the container harder than low gravity pulls on it and undoes the slowness.
2. **A NOTES** — SCALE Pentatonic Major, SPREAD 1, PEGS 5. One peg per scale degree, so the ring _is_ the scale. A pentatonic has no semitone in it, which is what lets it sit under another voice without ever fighting it.
3. **A NOTES ▸ DENSITY** — around 85 %. Drops the occasional note so the line wanders instead of ticking, without touching the motion on screen.
4. **A GATE** — SPACE `2`, then ATTACK 120 ms and DECAY 750 ms. Do these in that order: SPACE sets a hard floor under the gap (two beats, so 1000 ms at 120 BPM), and the envelope has to fit inside **that floor**, not inside the average gap. Sizing a 1500 ms decay against a 2 s average looks fine on paper and clips on every close pair.
5. **COUPLING** — PROXIMITY around 40 %, COUPLE 70 %. The containers now occasionally answer each other, which is where the "evolving" comes from.
6. **CV IN** — `DENS AB` on a very slow LFO at 60 % depth, with DENSITY set to 30 % in the menu. The patch now breathes over minutes.

Add **LOOP** BEATS 8 with NAP 1 / WAKE 3 if you want it to settle into something that repeats and then opens back up. Turn GRAVITY down toward 5 for the extreme end — about one note every three seconds from a single ball.

### Keeping a phrase

The module generates continuously and never repeats, which is what it is for —
but it also means a passage you like is gone by the time you reach for the
encoder. Loop mode is the answer.

1. Patch as normal and let it run until something catches your ear.
2. On the LOOP page set **BEATS** to the phrase length you want — 4 or 8 to
   start. From the next boundary the module repeats that phrase exactly.
3. If you set the length a moment too late and captured the wrong bar, click
   **NEW PHRASE** to grab the current one instead. Keep clicking until one lands.
4. Everything else still works over the top. Sweep **PROXIMITY**, change the
   scale, mute pegs, ride a CV — the phrase's rhythm holds while the sound around
   it moves.
5. Set **BEATS** back to `OFF` to let it run free again.

**Call-and-response.** Set **WAKE** 1, **NAP** 1, **A SHIFT** 0 and **B SHIFT** 1.
Container A plays the first loop while B rests, then they swap. With **WAKE** 2
and **NAP** 2 they trade two-loop phrases instead. Because the physics never
stops during a nap, each container comes back exactly where it would have been.

**Longer forms.** **WAKE** 3 with **NAP** 1 on B alone gives a container that
drops out for one loop in four — a structure, rather than a texture, without any
sequencing of your own.

A loop is only as reproducible as the settings under it. Modulating gravity or
ball count from a CV while a loop runs will change the phrase — usually the
interesting kind of change, but if you want the phrase frozen, leave the physics
alone and modulate the note mapping instead.

### Locking to a grid

The physics free-runs and the notes land where they land, which is the point of the module. When a patch needs the rhythm locked, set **QUANTIZE** on the CLOCK page to a division: a peg hit is then held and released on the next grid boundary.

If a second hit arrives for the same channel before the pending one has been released, the newer one replaces it. A dense passage therefore releases as one note on the boundary rather than a burst of retriggers, which keeps the result sounding like the physics that produced it.

### External clock sync

1. Set **IN 1** to `CLOCK` on the CLOCK page (this is the default).
2. Patch your clock into IN 1 and set **CLK DIV** to match its resolution (4 for a 16th-note clock, 1 for quarter notes).
3. The tempo display shows the derived BPM with an `E` next to it while pulses are actually arriving.

When the clock stops or is unpatched, the module falls back to the internal BPM setting after a short timeout scaled to the tempo it was receiving. The module tracks clocks from 20 to 300 BPM and uses a median of the last few intervals, so a single jittery edge will not lurch the rotation.

### Muting pegs

Muting individual pegs is how you open up the rhythm without changing the physics — a muted peg still bounces the ball, it just does not play a note. It is also how you decide which coupled transfers speak.

On the hardware, the peg mask is set by **RANDOM** and stored with each preset. In the VCV Rack plugin, individual pegs are toggled under **right-click ▸ Container A/B ▸ Active pegs**.

### Randomize

**SETTINGS ▸ RANDOM** rolls a whole new patch: physics, scale, root, spread, bias, peg count, peg mutes, gate settings, proximity and coupling for both containers. In VCV Rack, the standard Randomize (Ctrl+R) does exactly the same thing.

It deliberately leaves the tempo, the clock divider, the quantize grid, the IN 1 role and the CV modulation matrix alone — those are the things you cabled up on purpose, and rerolling them would turn "give me a new rhythm" into "break my patch".

The ranges it draws from are narrower than the full parameter ranges, so a roll always lands on something that actually plays a sequence rather than a container that either barely rings a peg or buzzes continuously. It never writes a preset slot, so a saved patch is one LOAD away.

### Save/Load Configuration

The module has 10 memory slots (0–9). The parameters saved into slot 0 are automatically loaded on boot.

1. Navigate to **SLOT** on the PRESETS page.
2. Click the encoder, turn to the desired slot, and click again to leave edit mode.
3. Select **SAVE** and click the encoder to store the current settings in that slot.
4. Select **LOAD** and click the encoder to recall it.

The dot in the top-left corner of the screen disappears once the current state has been saved.

## VCV Rack Plugin

The VCV Rack plugin is a full software emulation of the hardware module and can be used without owning the physical hardware. It runs the same firmware code, so the behaviour matches. The plugin saves and loads its configuration inside the patch, in the same way as the hardware module does in its memory, without the use of VCV Rack presets.

Every parameter is reachable from the module's right-click context menu, grouped as **Coupling**, **Clock**, **Loop**, **CV modulation** and one submenu per container. The encoder and screen work as they do on the hardware, so either route is available.

Some features are exclusive to the plugin:

- Setting the input CV range to 0-5V, -5V to +5V or 0-10V. The hardware module only supports 0-5V.
- Setting the encoder sensitivity.
- Toggling individual pegs on and off from the **Active pegs** submenu.

## Hardware Calibration

The module ships with sensible default values, but for best precision — especially when using the CV outputs for 1V/oct pitch — you should run the hardware calibration wizard once after building or assembling the module.

Calibration covers two things:

**Output calibration**: the output op-amp gain is set with on-board trimmers so every output jack delivers exactly 5.00 V at full scale, and the wizard then measures each output's low point to correct any residual offset in firmware.
**CV input calibration**: each CV input is measured at two known reference voltages (1 V and 3 V) to build a per-channel linear correction that compensates for resistor tolerances and ADC offset. This is done with external references and is independent of the module's own outputs, so any output error does not propagate into the input calibration.

Calibration data is stored in a dedicated area of non-volatile memory **separate from presets**, so it survives firmware updates and preset load/save operations.

### What you need

- A multimeter capable of measuring DC voltage to at least two decimal places.
- A stable, known **1 V** and **3 V** source for the CV inputs — for example a precision voltage reference, a bench power supply, or a calibrated sequencer/quantizer output — and a patch cable to connect it.

### Running calibration

The wizard has 6 steps: output trim, output offset capture, then four CV input captures (1 V and 3 V on each of the two CV inputs).

1. Power on the module **from your Eurorack supply** while **holding the encoder button** pressed, which opens the module selector. Release the button, scroll to **CALIBRATE** at the bottom of the list and click. (From a running module you can get to the same screen with **SETTINGS → BOOT MENU**, or by holding the encoder for two seconds.) Click the encoder at the welcome screen to start.

   Calibration belongs to the board, not to any one module: one run covers every module in the firmware, and the wizard reboots back to the selector when it is done.

   > ⚠️ Calibrate on Eurorack power, **not** the MCU's USB port — USB cannot drive the outputs to full scale, so the trim would be wrong. **Never connect Eurorack power and USB at the same time, as this could damage the module.**

2. **Step 1 — Output trim** (`1/6  OUTPUT TRIM`):
   All four outputs are driven to full scale. Using a multimeter set to DC voltage, probe each output jack in turn and adjust its corresponding trimmer potentiometer on the PCB until the reading is exactly **5.00 V**. When all four outputs read 5.00 V, press the encoder to continue.

3. **Step 2 — Output offset** (`2/6  <OUT> OFFSET`):
   All outputs are driven to a nominal 1.000 V. For each output jack in turn (OUT 1 – OUT 4, i.e. CV 1, CV 2, GATE 1, GATE 2 in GravityForge's terms), measure the actual voltage at that jack and dial the measured value in with the encoder, then click to confirm. The firmware uses the difference to correct that channel. The wizard names the jacks by number rather than by role, because it runs before a module has been chosen.

4. **Steps 3–6 — CV input capture** (`3/6` … `6/6`):
   The display asks for a specific reference voltage on a specific input, in turn:
   - `3/6  CV1 INPUT 1V` — apply **1 V** to CV input 1 (IN 2)
   - `4/6  CV1 INPUT 3V` — apply **3 V** to CV input 1 (IN 2)
   - `5/6  CV2 INPUT 1V` — apply **1 V** to CV input 2 (IN 3)
   - `6/6  CV2 INPUT 3V` — apply **3 V** to CV input 2 (IN 3)

   For each step, apply the requested voltage to the named input. The screen shows a live voltage reading so you can confirm the signal is stable; when it is steady, press the encoder to capture.

5. **Review and save**:
   The display shows the derived per-channel scale and offset for a sanity check. Press the encoder to **save and reboot**. The module restarts with calibration applied.

> **Tip:** Calibration only needs to be run once. Re-run it if you replace any resistors or trimmers on the board, or if CV tracking feels off after assembly.

## Firmware Update

1. Download the latest firmware from the [releases page](https://github.com/VoltageFoundryMod/ForgeSeries/releases).
2. Connect the module to your computer using a USB-C cable while holding the small BOOT (B) button. The CPU can be removed from the module as it's socketed to the main board if desired. Firmware loading can be done with the CPU removed.
3. A new drive will show on your computer named RPI-RP2. Copy and overwrite the `CURRENT.UF2` file to the module USB drive. After the copy is finished, the module will reboot and the new firmware will be loaded.

XIAO RP2040 MCU

> Note: a firmware update may change the preset format, in which case saved slots are reset to defaults on first boot. Calibration data is unaffected.
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

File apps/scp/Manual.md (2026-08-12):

# ForgeView: A scope for Eurorack



## Overview

ForgeView is an essential oscilloscope for Eurorack systems. It can be used to visualize waveforms and signals in your modular system. The module has a 0.96" OLED display and can be used to visualize waveforms from LFOs, envelopes, oscillators, filters, and other signals in your system.

The module also exists as a VCV Rack plugin, which can be used to try the module virtually before building the hardware.

Part of the **Forge** series of modules which share a single hardware platform.

The hardware schematics and design files are completely open-source and available in the [GitHub repository](https://github.com/VoltageFoundryMod/ForgeSeries-Hardware).

ForgeView Module Front Panel
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

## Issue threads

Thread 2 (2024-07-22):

[CLK] Implement sync with external clock

carlosedp, 2024-07-22:
To implement this, uClock has a function called `uClock.clockMe()` that expects 24PPQM calls to sync.

The issue is that if using the clock input with a simple LFO, square wave or anything that output pulses (for example Marbles output T2), we need a way to convert (multiply) these pulses to 24 pulses/s for the correct synchronization. Also this should be phase locked to the input to guarantee the input and output pulses (and its divisions/multipliers) are kept in sync.

I found a similar solution but I didn't make it work as expected... also had to change the Timer1 to Timer2 since uClock uses Timer1 internally.

- https://forum.arduino.cc/t/frequency-multiplier-with-phase-locked/476894

There's a simulation here: https://wokwi.com/projects/404326713803438081

carlosedp, 2024-11-04:
External clock works but pulses are not in sync.

Still WIP.

carlosedp, 2024-11-18:
Implemented an initial sync to external trigger without any divider.
Sync follows 1PPQN (1 pulse per quarter note).

Closed 2024-11-18.

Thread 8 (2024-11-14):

Multiple load/save slots (presets) and load defaults

carlosedp, 2024-11-14:
Add the option to have multiple save/load slots and an option to load the factory presets.

Ps. The presets are deleted when new firmware is flashed.

carlosedp, 2024-12-05:
Fixed with #17

Closed 2024-12-05.

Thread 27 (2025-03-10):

[CLK] Make waveforms available on outputs 1/2

carlosedp, 2025-03-10:
Some waveforms could be implemented on outputs 1 and 2 like play and reset.

In fact all waveforms could be implemented by using PWM on the digital outs (1/2).

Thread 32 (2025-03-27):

Clock Forge save issue

K-Teck-Dave, 2025-03-27:
hey there

i haven't investigated this too deeply:

v1.7 & 1.6 won't save output divider/multiplier sates
had to go back to 1.5

1.5 & 1.6 only show memory slot 0 to save to
1.7 shows all memory slots and saves euclidean data etc.

carlosedp, 2025-05-01:
Sorry about the delay... I'll investigate this.
Been kinda off of the project for a while.

Closed 2025-05-02.

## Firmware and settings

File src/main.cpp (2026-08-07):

// main.cpp — the ForgeSeries shell.
//
// Owns the board; runs exactly one app at a time.
//
//   Core 0 (setup/loop)   hardware bring-up, encoder, the selected app's Tick0
//   Core 1 (setup1/loop1) the selected app's Tick1 (render + flush)
//
// The core split and bus ownership are the same ones every ForgeSeries firmware
// already used: Wire1/ADC on Core 0, Wire/display on Core 1, which is why
// neither needs a mutex.

#include <Arduino.h>

#include <Adafruit_GFX.h>
#include <Adafruit_SSD1306.h>
#include <EEPROM.h>
#include <Wire.h>

#define OLED_ADDRESS 0x3C
#define SCREEN_WIDTH 128
#define SCREEN_HEIGHT 64

#include "IApp.hpp"
#include "boardIO.hpp"
#include "boardPinouts.hpp"
#include "calibrationData.hpp"
#include "encoder.hpp"
#include "fsStore.hpp"
#include "fwVersion.hpp"
#include "shellObjects.hpp"
#include "splash.hpp"
// calibration.hpp is included further down: it needs `display` and
// SaveCalibration(), both defined below.
//
// The app factory headers sit with the registry further down, so that adding a
// module touches one contiguous block rather than two ends of the file.

// ── Board-owned singletons ──────────────────────────────────────────────────
// One display, one encoder, one calibration for the whole module, rather than a
// set per firmware. Apps reach the display only through IApp::Tick1's argument
// and the encoder only through IApp's event calls, so they cannot fight over
// either.
Adafruit_SSD1306 display(SCREEN_WIDTH, SCREEN_HEIGHT, &Wire, -1);
DisplayManager displayMgr(display);
Encoder encoder(ENC_PIN_1, ENC_PIN_2);

// Referenced by core/boardIO.hpp (DAC correction) and core/cvInput.hpp.
// Shared by every app: calibration describes the board, not the module.
CalibrationData cal = {};

// ── The app registry ────────────────────────────────────────────────────────
// Adding an app is one include, one entry, one -I line in platformio.ini — and,
// if it should also ship on its own, one env there. Nothing below is per-app
// beyond those two lines.
//
// The includes are unconditional even in a single-module image, because these
// headers only DECLARE a factory. Declaring forge::DqApp() in a build that does
// not compile dq_app.cpp costs nothing: an unused declaration is not a link
// reference. So only the array has to know which modules are actually here.
//
// A single-module build (env:xiao_clk and friends) names its factory in
// FORGE_ONLY_APP and gets an array of one. The shell is otherwise identical: it
// still boots straight into the module, still honours SETTINGS ▸ BOOT MENU, and
// still reaches the calibration wizard — the selector simply lists one module
// and CALIBRATE. See kMenuTitle for the one place kAppCount == 1 is visible.
#include "att_app.hpp"
#include "clk_app.hpp"
#include "dq_app.hpp"
#include "gen_app.hpp"
#include "scp_app.hpp"
#include "wea_app.hpp"

// The order here is the boot menu's order, and the index persisted in /boot
// (fsStore's SaveBootApp/LoadBootApp) — which is why the array is written out
// rather than each app TU registering itself at static-init time. Static-init
// order across translation units is unspecified, so self-registration would let
// link order decide what index 2 means.
static forge::IApp *const kApps[] = {
#ifdef FORGE_ONLY_APP
    forge::FORGE_ONLY_APP(), // single-module image: this one and no other
#else
    forge::ClkApp(),
    forge::DqApp(),
    forge::GenApp(),
    forge::ScpApp(),
    forge::AttApp(),
    forge::WeaApp(),
#endif
};
static constexpr int kAppCount = (int)(sizeof(kApps) / sizeof(kApps[0]));

static forge::IApp *g_app = nullptr;

// ── Calibration ─────────────────────────────────────────────────────────────
// The wizard is board-level: it measures the analog front and back ends, which
// are the same hardware whichever module you go on to boot, so one run serves
// every app and it lives here rather than in any of them.
//
// It draws straight to `display` and blocks, which is only safe because it runs
// from the boot menu — Core 0, before Core 1 is released, with no app started.
void SaveCalibration(const CalibrationData &c) { forge::fs::SaveCalibrationFs(c); }
#include "calibration.hpp"

// Core 1 is started by the Arduino core *before* setup() runs on Core 0, so
// without this gate it would render over Wire while display.begin() is still
// initialising the panel — corrupting the init command stream and wiping the
// splash. Core 1 idles until Core 0 raises it.
static volatile bool g_setupDone = false;

// ── Taking the display back from Core 1 ─────────────────────────────────────
// Core 1 owns the display once it is released (see shellObjects.hpp), so Core 0
// must not draw on it. SwitchToMenu has to: it puts a message up and reboots.
//
// Doing that unsynchronised is what makes the return-to-menu gesture unreliable.
// Two cores interleaving writes on Wire corrupt each other's transactions, and
// the reboot landing mid-byte is worse than a garbled frame: the panel keeps SDA
// low waiting for the rest of that byte, and the bus is still held when the MCU
// comes back up. RecoverI2CBus() in InitWire() now clears that, but not starting
// it is better than recovering from it — a reset arriving on its own is the case
// that cannot be prevented, this one can.
//
// So Core 0 asks, and waits for Core 1 to confirm it is off the bus.
static volatile bool g_renderStop = false;
static volatile bool g_renderStopped = false;

// Returns with Core 1 off the display bus and out of Tick1.
//
// Bounded: a wedged Core 1 must not take the menu gesture down with it, and the
// worst case is the garbled frame we are about to reboot away from anyway. The
// budget covers a whole flush at 1 MHz (1 KB frame, ~10 ms) many times over.
static void TakeDisplayFromCore1() {
    g_renderStop = true;
    const uint32_t t = millis();
    while (!g_renderStopped && (millis() - t) < 100)
        delay(1);
}

// ── Encoder ─────────────────────────────────────────────────────────────────
// The shell polls the encoder and forwards events, rather than letting apps read
// the pins: it needs the same events to catch the "back to menu" gesture, and
// two readers would race the quarter-step detent state.
static long oldPosition = 0;
static long newPosition = 0;

// Hold the encoder this long while an app is running to return to the selector.
// Long enough not to fire on an ordinary click, short enough to find by
// accident-then-intent.
#define APP_SWITCH_HOLD_MS 2000

static bool g_switchRequested = false;
static unsigned long g_pressStartMs = 0;
static bool g_wasPressed = false;

namespace forge {
void RequestAppMenu() { g_switchRequested = true; }
} // namespace forge

static void PollEncoder(forge::IApp *app) {
    const bool pressed = (digitalRead(ENCODER_SW) == LOW); // active-low, pull-up

    // Hold-to-switch. Every app acts on the button's *release* edge, so a hold
    // that ends in a reboot is never seen as a click: the app only ever receives
    // "pressed", and the release it would act on never arrives.
    if (pressed && !g_wasPressed) {
        g_pressStartMs = millis();
    } else if (pressed && (millis() - g_pressStartMs) >= APP_SWITCH_HOLD_MS) {
        g_switchRequested = true;
    }
    g_wasPressed = pressed;

    app->EncoderButton(pressed);

    // ── Detent detection ────────────────────────────────────────────────────
    // The quadrature decoder counts all four transitions, so one detent is
    // COUNTS_PER_DETENT counts. Consume whole detents out of the accumulated
    // delta rather than snapping oldPosition to wherever the encoder happens to
    // be.
    //
    // The previous form — a +/-3 deadband against (newPosition +/- 3) / 4, then
    // oldPosition = newPosition — was asymmetric. From an aligned position it
    // took one detent to register in the decreasing direction and two in the
    // increasing one, because integer division truncates and the snap threw
    // away the remainder. That is the "reversing needs two clicks" symptom.
    // Truncation toward zero also flipped which direction was penalised once
    // the count went negative.
    //
    // Subtracting a whole detent keeps the remainder, so direction changes cost
    // exactly one detent either way, and the loop catches up if several arrive
    // between polls.
    static constexpr long COUNTS_PER_DETENT = 4;

    newPosition = encoder.read();
    long delta = newPosition - oldPosition;

    while (delta >= COUNTS_PER_DETENT) {
        delta -= COUNTS_PER_DETENT;
        oldPosition += COUNTS_PER_DETENT;
        app->EncoderTurn(-1); // increasing counts = counter-clockwise
    }
    while (delta <= -COUNTS_PER_DETENT) {
        delta += COUNTS_PER_DETENT;
        oldPosition -= COUNTS_PER_DETENT;
        app->EncoderTurn(+1); // decreasing counts = clockwise
    }
}

// ── Boot menu ───────────────────────────────────────────────────────────────
// Hold the encoder at power-on to choose which module the hardware is. The
// choice persists, so the module boots straight into it from then on.
//
// This runs entirely on Core 0, before Core 1 is released, so it can drive the
// display directly — no frame-ready handshake, and no app is running yet.
//
// The list is the apps plus one trailing CALIBRATE row. That row is why the
// selector is reachable from an app's SETTINGS page at all: the wizard is
// board-level and can only run with no app started, so this screen is the only
// place it can live, and without a way back here there would be no way in.
static constexpr int kCalibrateIndex = kAppCount;
static constexpr int kMenuEntries = kAppCount + 1;

// A single-module image has nothing to select between — the list is that one
// module and CALIBRATE — so the header names what the screen is instead of
// promising a choice.
static constexpr const char *kMenuTitle =
    (kAppCount > 1) ? "SELECT MODULE" : "SETUP";

// Shown by SwitchToMenu() on the way out of a running app, for the same reason.
static constexpr const char *kMenuLeaveMsg =
    (kAppCount > 1) ? "SELECT MODULE..." : "SETUP...";

static void DrawMenu(int sel, int top) {
    display.clearDisplay();
    display.setTextColor(WHITE);
    display.setTextSize(1);
    display.setCursor(2, 2);
    display.print(kMenuTitle);

    // The image version, right-aligned on the header row: one number for the
    // whole UF2, above the per-module versions in the list. 6px per character at
    // text size 1, so the title ends at 2 + len*6 — 80 for "SELECT MODULE" —
    // and the version may not start before that.
    {
        const int floorX = 2 + (int)strlen(kMenuTitle) * 6;
        const int len = (int)strlen(forge::kFirmwareVersion);
        int x = SCREEN_WIDTH - len * 6 - 2;
        if (x < floorX) {
            x = floorX; // a long tag gives up alignment rather than the header
        }
        // An over-long tag clips at the right edge rather than wrapping down
        // into the first list row — setup() turns wrap off firmware-wide.
        display.setCursor(x, 2);
        display.print(forge::kFirmwareVersion);
    }

    display.drawFastHLine(0, 11, SCREEN_WIDTH, WHITE);

    // Four visible rows at 13px; the list scrolls when there are more entries.
    const int rows = 4;
    for (int r = 0; r < rows && (top + r) < kMenuEntries; r++) {
        const int i = top + r;
        const int y = 15 + r * 12;
        if (i == sel) {
            display.fillRect(0, y - 2, SCREEN_WIDTH, 11, WHITE);
            display.setTextColor(BLACK);
        } else {
            display.setTextColor(WHITE);
        }
        display.setCursor(4, y);
        if (i == kCalibrateIndex) {
            display.print("CALIBRATE"); // no version — it is not a module
        } else {
            display.print(kApps[i]->Name());
            display.setCursor(84, y);
            display.print("v");
            display.print(kApps[i]->Version());
        }
    }
    display.setTextColor(WHITE);
    display.display();
}

// Blocks until the user clicks. Returns the chosen index — an app index, or
// kCalibrateIndex.
static int RunBootMenu(int initial) {
    int sel = (initial >= 0 && initial < kMenuEntries) ? initial : 0;
    int top = 0;

    // Draw before waiting on the button, not after.
    //
    // The gesture that gets here is the encoder being *held* — at power-on, or
    // for two seconds inside an app. Drawing only once it was released left the
    // screen on the splash for as long as the hold lasted, so the module looked
    // like it had ignored the gesture and you let go to check.
    DrawMenu(sel, top);

    // Now let that press go before the loop starts, or the very same press is
    // read as the selection click and the menu closes on whatever was
    // preselected.
    while (digitalRead(ENCODER_SW) == LOW)
        delay(10);
    delay(50); // contact settle

    // Baselined after the release, so a nudge of the shaft while holding does
    // not arrive as a detent the moment the loop opens.
    long oldPos = encoder.read();

    for (;;) {
        // Whole-detent consumption, same as PollEncoder — see the note there
        // for why snapping to newPos made direction changes cost two detents.
        const long newPos = encoder.read();
        int dir = 0;
        if (newPos - oldPos >= 4) {
            oldPos += 4;
            dir = -1;
        } else if (newPos - oldPos <= -4) {
            oldPos -= 4;
            dir = +1;
        }
        if (dir != 0) {
            sel += dir;
            if (sel < 0)
                sel = kMenuEntries - 1;
            else if (sel >= kMenuEntries)
                sel = 0;
            if (sel < top)
                top = sel;
            else if (sel > top + 3)
                top = sel - 3;
            DrawMenu(sel, top);
        }

        if (digitalRead(ENCODER_SW) == LOW) { // clicked — commit
            while (digitalRead(ENCODER_SW) == LOW)
                delay(10);
            return sel;
        }
        delay(2);
    }
}

// Which app to run: the stored choice, unless the encoder is held at boot.
// Returns only when a module was picked; CALIBRATE runs the wizard, which
// reboots.
//
// The held-encoder check is deliberately unconditional and happens before any
// app code runs, so a firmware that hangs in its own Begin() can still be
// escaped — hold the encoder and power-cycle.
static forge::IApp *SelectApp() {
    uint8_t stored = forge::fs::LoadBootApp(0);
    if (stored >= kAppCount)
        stored = 0; // stale index (app removed from this build)

    // Either gesture opens the menu: the encoder held at power-on, or an app
    // having asked for it before rebooting.
    const bool requested = forge::fs::BootMenuRequested();
    if (requested || digitalRead(ENCODER_SW) == LOW) {
        const int chosen = RunBootMenu(stored);

        if (chosen == kCalibrateIndex) {
            // Come back to this screen afterwards rather than dropping into a
            // module: calibrating is rarely the last thing you meant to do, and
            // RunCalibration() reboots as soon as it has written /cal.bin.
            // Keep `stored` as the pre-selection so the list opens where it was.
            forge::fs::SaveBootApp(stored, /*showMenu=*/true);
            RunCalibration(); // saves and reboots
            for (;;) {        /* not reached */
            }
        }

        // Always rewrite, even when the choice is unchanged: it is what clears
        // the showMenu flag, and leaving it set would trap the module in the
        // menu on every boot.
        forge::fs::SaveBootApp((uint8_t)chosen, false);
        stored = (uint8_t)chosen;
    }
    return kApps[stored];
}

// ── Module splash ───────────────────────────────────────────────────────────
// The chosen module's name, shown once between the logo and the app starting.
//
// It is drawn on two lines because at text size 2 a character is 12px wide, so
// from x=4 only ten fit across the 128px display: "GravityForge" ran to 148px
// and lost its last character and a half. "ClockForge" fit with 4px to spare, so
// the next name of any length would have hit this too.
//
// Every module name is Forge plus one word, which gives a natural break —
// Gravity/Forge, Forge/View — and the longest half ("Gravity", 84px) then has
// room to spare. Both lines are centred, so the split is not visible as one.

// `len` characters of `s`, horizontally centred, at row `y`. Takes a length
// because the two halves of a name are one buffer, not two strings.
static void DrawCentered(const char *s, int len, int y, int charWidth) {
    const int x = (SCREEN_WIDTH - len * charWidth) / 2;
    display.setCursor(x < 0 ? 0 : x, y);
    for (int i = 0; i < len; i++)
        display.write(s[i]);
}

static void DrawModuleSplash(const forge::IApp *app) {
    const char *name = app->Name();
    const int len = (int)strlen(name);

    // Split so "Forge" survives whole: after it when the name opens with it,
    // before it otherwise. A name without "Forge" stays on one line.
    const char *forge = strstr(name, "Forge");
    int cut = 0;
    if (forge == name && len > 5) {
        cut = 5; // Forge + suffix, e.g. ForgeView
    } else if (forge != nullptr) {
        cut = (int)(forge - name); // prefix + Forge, e.g. GravityForge
    }

    display.clearDisplay();
    display.setTextColor(WHITE);
    display.setTextSize(2);

    if (cut > 0) {
        DrawCentered(name, cut, 14, 12);
        DrawCentered(name + cut, len - cut, 32, 12);
    } else {
        DrawCentered(name, len, 23, 12); // single line, vertically centred
    }

    display.setTextSize(1);
    display.setCursor(80, 54);
    display.print("V");
    display.print(app->Version());
    display.display();
}

// ────────────────────────────────────────────────────────────────────────────
void setup() {
    Serial.begin(115200);
    {
        const uint32_t t = millis();
        while (!Serial && (millis() - t) < 2000) { /* wait for USB-CDC */
        }
    }
    Serial.println("\n\n--- ForgeSeries unified firmware ---");

    encoder.begin(); // deferred pin init — safe only once the runtime is up
    InitWire();
    InitIO();

    // Display first, so any later hardware failure can be shown on screen.
    if (!display.begin(SSD1306_SWITCHCAPVCC, OLED_ADDRESS)) {
        Serial.println(F("SSD1306 allocation failed"));
        pinMode(LED_BUILTIN, OUTPUT);
        while (1) { // nothing useful left to do — blink for a service tech
            digitalWrite(LED_BUILTIN, HIGH);
            delay(200);
            digitalWrite(LED_BUILTIN, LOW);
            delay(200);
        }
    }
    // Blank the panel before anything can be seen on it.
    //
    // begin() clears the frame buffer but never pushes it, and its init sequence
    // ends with DISPLAYON — so the panel lights up showing whatever is still in
    // its GDDRAM: random bytes on a cold boot, the previous app's last frame
    // after the reboot that comes back here. Without this flush that garbage
    // stays up through InitDAC, the LittleFS mount and the calibration load,
    // which is the "garbled characters until the boot menu appears" window.
    display.clearDisplay();
    display.display();

    // Wrap off for the whole firmware: every screen here is laid out to fit, and
    // a wrapped glyph corrupts the line below rather than being clipped away.
    display.setTextWrap(false);
    display.cp437(true);

    // The DAC is optional for some apps (the scope only uses it for
    // pass-through), so a failure here warns rather than halts.
    if (!InitDAC())
        Serial.println("MCP4728 not found — outputs disabled.");

    // Storage, then calibration. One calibration serves every app because it
    // describes the board, not the module — which is the whole reason it lives
    // in the shell rather than being re-run per firmware.
    if (!forge::fs::Begin())
        Serial.println("No persistent storage — presets and calibration disabled.");
    cal = forge::fs::LoadCalibrationFs();
    Serial.println(cal.valid ? "Calibration: loaded"
                             : "Calibration: not set (using nominal)");

    display.clearDisplay();
    display.drawBitmap(30, 0, VFM_Splash, 68, 64, 1);
    display.display();
    delay(1200);

    g_app = SelectApp();

    DrawModuleSplash(g_app);
    delay(1000);

    Serial.printf("Starting app: %s v%s\n", g_app->Name(), g_app->Version());
    g_app->Begin();

    // Re-baseline the encoder before the app sees it.
    //
    // Anything turned during boot is on the counter by now — most obviously the
    // scrolling done in the module selector, which tracks its own position and
    // leaves this one at zero. Without this, PollEncoder's first call reads a
    // delta covering the whole menu rotation and fires that many detents
    // straight into the app: the module came up with its cursor moved by
    // exactly as far as you had scrolled to select it, and only after selecting
    // it from the menu — a plain power-cycle looked fine.
    oldPosition = encoder.read();
    newPosition = oldPosition;

    g_setupDone = true; // release Core 1
}
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
void loop() {
    PollEncoder(g_app);
    if (g_switchRequested)
        SwitchToMenu();
    g_app->Tick0();
}

void setup1() {
    while (!g_setupDone)
        delay(1);
}

void loop1() {
    // Checked between frames, never inside one: Core 0 waits for this
    // acknowledgement, so seeing it means the last flush has fully completed and
    // no further one will start.
    if (g_renderStop) {
        g_renderStopped = true;
        delay(1);
        return;
    }
    g_app->Tick1(display);
}

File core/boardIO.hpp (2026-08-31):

#pragma once

// Converter resolutions (DAC_RESOLUTION / MAXDAC / MAXADC) are board facts and
// live in boardPinouts.hpp, included below, so code that only
// needs to scale a reading does not have to include the whole DAC driver.

// MCP4728 I2C address — the base board's DAC, outputs 1-4.
#define MCP4728_ADDR 0x60

// The expander's MCP4728, outputs 5-8. Same part, same bus (Wire1), so its
// address has to be moved off the 0x60 default before it can be fitted. The
// MCP4728 stores its address in EEPROM and changing it needs LDAC toggled
// during the write, which no pin here can do — it is done out-of-circuit
// through the expander's program header.
#define MCP4728_EXP_ADDR 0x61

#include <Adafruit_MCP4728.h>
#include <Arduino.h>
#include <Wire.h>
#include <math.h> // lroundf (output calibration remap)

#include "calibrationData.hpp" // CalibrationData (full definition)
// boardPinouts.hpp, not the app-level pinouts.hpp: this layer needs the board
// wiring only, never an app's jack semantics. Depending on the app header
// would make core/ unbuildable without one.
#include "boardPinouts.hpp"

// MCP4728 quad 12-bit I2C DAC (channels A=out1, B=out2, C=out3, D=out4)
inline Adafruit_MCP4728 dac4;

// Current per-channel shadow values for fast single-channel updates.
// Indices 4-7 are the expander's, written only when one is fitted.
inline uint16_t _dacShadow[NUM_MAX_OUTPUTS] = {0, 0, 0, 0, 0, 0, 0, 0};

// Set once at boot by ProbeExpander(). Nothing writes the expander DAC unless
// this is true, so a module with no expander pays one I2C probe and nothing
// more.
inline bool expanderDacPresent = false;

// Physical channel mapping: DAC channel A-D drive outputs 1-4 in order.
//
// This used to swap B and C, compensating for the GY-MCP4728 breakout's wiring
// on the older board. The board no longer uses that breakout — the DAC is on
// the PCB with its outputs wired in order, and the expander is wired the same
// way — so the mapping is the identity on both devices and the swap is gone.
inline const MCP4728_channel_t _chanMap[4] = {
    MCP4728_CHANNEL_A, // Output 1 → DACA → Jack 1 (CV 1)
    MCP4728_CHANNEL_B, // Output 2 → DACB → Jack 2 (CV 2)
    MCP4728_CHANNEL_C, // Output 3 → DACC → Jack 3 (GATE 1)
    MCP4728_CHANNEL_D, // Output 4 → DACD → Jack 4 (GATE 2)
};

inline void InitIO() {
    analogReadResolution(12); // RP2040 supports 12-bit ADC

    pinMode(CLK_IN_PIN, INPUT_PULLDOWN); // TRIG in — pull low so a floating
                                         // input doesn't fire spurious triggers
    for (int i = 0; i < NUM_MAX_CV_INS; i++) {
        pinMode(CV_IN_PINS[i], INPUT);
    }
    pinMode(ENCODER_SW, INPUT_PULLUP);
    // No GPIO gate output pins — all outputs via MCP4728
}

// Display bus speed, platform-wide.
//
// The SSD1306 datasheet rates the bus at 400 kHz, but the panel on this board
// runs reliably at 1 MHz — ForgeView has shipped that way to hit its scope
// refresh rate. Since a display.display() flush blocks the calling core for the
// whole transfer, there is no upside to clocking it slower on the other
// modules: 1 MHz simply makes every UI more responsive.
//
// This applies to Wire ONLY. Do NOT raise Wire1 to match — see InitWire().
//
// Left overridable so an app can drop back if a future panel revision needs it.
#ifndef FORGE_DISPLAY_I2C_HZ
#define FORGE_DISPLAY_I2C_HZ 1000000
#endif
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

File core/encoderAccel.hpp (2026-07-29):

#pragma once

// encoderAccel.hpp — encoder rotation acceleration, shared by every module.
//
// Turning faster steps further, so a 0-100 parameter is reachable without
// twenty detents. This was byte-identical in all three firmwares and again in
// all three unified app TUs: six copies of the same twenty lines.
//
// Deliberately just the acceleration. What a detent *does* — move the menu
// cursor, edit a value, arm a live preview — is genuinely per-module and stays
// in each app's own handler.

#include <Arduino.h>

// `inline`: header-defined state, and the unified firmware links one TU per app
// plus the shell. Without it each TU carries a private copy of the timers.
inline float speedFactor = 1.0f;
inline unsigned long lastEncoderTime = 0;
inline int lastEncoderDir = 0; // +1 / -1, 0 = nothing yet

// Call once per acted-on detent, with its direction.
inline void UpdateSpeedFactor(int dir) {
    const unsigned long now = millis();
    const unsigned long timeDiff = now - lastEncoderTime;
    lastEncoderTime = now;

    // Reversing always restarts at a single step, so a turn-around never
    // overshoots by eight.
    if (lastEncoderDir != 0 && dir != lastEncoderDir) {
        speedFactor = 1.0f;
        lastEncoderDir = dir;
        return;
    }
    lastEncoderDir = dir;

    if (timeDiff < 30) {
        speedFactor = 8.0f; // very fast spin
    } else if (timeDiff < 60) {
        speedFactor = 4.0f;
    } else if (timeDiff < 120) {
        speedFactor = 2.0f;
    } else {
        speedFactor = 1.0f; // normal
    }
}

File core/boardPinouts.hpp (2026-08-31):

#pragma once

// boardPinouts.hpp — the ForgeSeries hardware, and nothing else.
//
// Every module in the series is the same board: a Seeed XIAO RP2040, an SSD1306
// OLED, an MCP4728 quad DAC, one rotary encoder with a push switch, three input
// jacks and four output jacks. That wiring is fixed and identical across every
// firmware, so it lives here exactly once.
//

// Needed for A0/A1/A2 below. This used to be left to the caller, which happened
// to work only because main.cpp included <Arduino.h> first; including a pinout
// header before Arduino.h was a compile error waiting to happen.
#include <Arduino.h>

// ── I2C — display bus (SSD1306 OLED) on Wire ─────────────────────────────────
// NOTE: Wire.setSDA/SCL on RP2040 takes GPIO numbers, not Arduino pin numbers.
// XIAO RP2040 physical pad D4 = GPIO6 (I2C1 SDA), D5 = GPIO7 (I2C1 SCL).
#define I2C_SDA_PIN 6 // GPIO6 = D4
#define I2C_SCL_PIN 7 // GPIO7 = D5

// ── I2C — DAC bus (MCP4728) on Wire1 ─────────────────────────────────────────
// XIAO RP2040 physical pad D6 = GPIO0 (I2C0 SDA), D7 = GPIO1 (I2C0 SCL).
// A separate bus from the display so DAC writes and display.display() never
// contend; combined with the core split (Core 0 = DAC, Core 1 = GFX) that
// removes the need for a mutex on either bus.
#define I2C_DAC_SDA_PIN 0 // GPIO0 = D6
#define I2C_DAC_SCL_PIN 1 // GPIO1 = D7

// ── IN 1 — gate/trigger input ────────────────────────────────────────────────
// Interrupt-driven only, never read as analog CV. Its meaning (clock / reset /
// kick / ...) is menu-selectable per app.
#define CLK_IN_PIN A0 // GPIO26

// ── IN 2 / IN 3 — analog CV inputs ───────────────────────────────────────────
// CV RANGE: the current hardware revision accepts 0-5 V only. A later revision
// moves to +/-5 V. Nothing downstream of each app's CV normalisation assumes a
// polarity, so that swap stays a one-function change — do not sprinkle range
// assumptions through modulation targets.
#define CV_1_IN_PIN A1 // GPIO27 — IN 2
#define CV_2_IN_PIN A2 // GPIO28 — IN 3

// ── IN 4 — analog CV input, on the expander ──────────────────────────────────
// The last free pad on the XIAO. Its jack, and the inverting/offsetting input
// stage in front of it, live on the expander board; the base board only carries
// the net from the expander header (J9 pin 8) to here. Electrically it is the
// same stage as IN 2 and IN 3 — 100k in, 200k from the -10 V reference, 33k
// feedback — so it reads through CvRead() like any other channel and needs no
// mapping of its own.
//
// With this taken, every XIAO pad is spoken for: 26, 27, 28, 29, 6, 7, 0, 1, 2,
// 4, 3. Nothing is left to drive the DAC's LDAC line, which is why the two DAC
// banks cannot be latched together — see DACWriteAllExp() in boardIO.hpp.
#define CV_3_IN_PIN A3 // GPIO29 = D3 — IN 4 (expander)

// ── Encoder ──────────────────────────────────────────────────────────────────
// arduino-pico pin numbers are GPIO numbers, not the silkscreen D numbers.
// XIAO RP2040: D8=GPIO2, D9=GPIO4, D10=GPIO3.
#define ENC_PIN_1 4  // GPIO4 = D9
#define ENC_PIN_2 2  // GPIO2 = D8
#define ENCODER_SW 3 // GPIO3 = D10

// ── Counts ───────────────────────────────────────────────────────────────────
// No GPIO output pins — all four outputs go through the MCP4728.
//
// These describe THE BASE BOARD, and keep doing so with an expander attached.
// Code that means "this board's own jacks" — calibration of the on-board DAC,
// the four panel LEDs, a module that has no expander support — stays on these.
#define NUM_CV_INS 2   // analog CV inputs (IN 1 is trigger-only)
#define NUM_OUTPUTS 4  // output jacks
#define NUM_DAC_OUTS 4 // ...all of which are DAC channels

// ── Expander counts ──────────────────────────────────────────────────────────
// Expander 1 is a second MCP4728 (four more outputs) plus one more CV input, on
// the DAC bus and the ADC pad above. NUM_MAX_* is the ceiling a module sizes its
// arrays to; how many are actually live is a runtime question, because whether
// an expander is fitted is a setting rather than a build flag. One firmware
// covers both, so there is no second image to keep in step and no second preset
// schema.
#define NUM_EXP_OUTPUTS 4
#define NUM_EXP_CV_INS 1
#define NUM_MAX_OUTPUTS (NUM_OUTPUTS + NUM_EXP_OUTPUTS) // 8
#define NUM_MAX_CV_INS (NUM_CV_INS + NUM_EXP_CV_INS)    // 3

// ── Converter resolution ─────────────────────────────────────────────────────
// The MCP4728 is 12-bit and so is the RP2040's ADC. These are board facts, so
// they live here rather than in boardIO.hpp: scaling a CV reading should not
// require pulling in the DAC driver.
#define DAC_RESOLUTION (12)
#define MAXDAC 4095 // Maximum value for a 12-bit DAC: 2^12 - 1
#define MAXADC 4095 // Maximum value for the RP2040's 12-bit ADC
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

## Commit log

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2026-01-19 Implement metrics to improve performance and find how to solve timing issues
    [main.cpp]
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2026-04-24 feat(rp2040): dual-core + dual-I2C architecture
    - Wire1 (GPIO0/1) for MCP4728 DAC on Core 0
    - Wire (GPIO6/7) for SSD1306 display on Core 1
    - Core 0: timer ISR, encoder, CV, DAC writes — never blocked
    - Core 1: display.display() via _displayFrameReady flag
    - Removes all mutex/deferral workarounds
    [main.cpp]
2026-04-25 fix: save/load display corruption and output dropout on RP2040
    - Replace direct display.display() calls from Core 0 with ShowTemporaryMessage()
    helper that uses _displayFrameReady to route through Core 1 (Wire owner)
    - Add _displayLocked flag to pause Core 1 GFX rendering during temporary messages
    - Replace re-entrant HandleIO() wait loop with HandleOutputs()-only loop so DAC
    output continues during save/load confirmation screen
    - Fix encoder inversion caused by re-entrant HandleEncoderClick()
    - Raise Wire1 (MCP4728 DAC bus) to 1MHz: DACWriteAll ~400us -> ~210us, loop 1935->2830Hz
    - Improve metrics: fix ISR start time bug, add DAC/Core1 flush timing, jitter reporting
    - Fix menu starting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
    [main.cpp]
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2026-04-27 feat(encoder): add encoder class implementation and integrate into main feat(clock): implement SetTapTempo function for BPM control refactor(menu): replace manual menu item count with automatic MENU_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
    [main.cpp]
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2026-04-28 fix: resolve AR envelope 0V drop and envelope UX improvements
    - Fix Wire1 clock from 1MHz to 400kHz (MCP4728 rated max): at 1MHz
    tLOW=500ns violated the 1300ns minimum, causing silent I2C data
    corruption where the DAC ACKed but misinterpreted channel values,
    outputting 0V during AttackHold. Software values were always correct.
    - Block divisor changes via encoder when output is AD/AR/ADSR type;
    'Env' label remains visible as read-only indicator (IsEnvelopeType())
    - Envelope output indicator now follows _waveActive: filled square
    while envelope is running, outline when idle (was fast-blinking from
    Env divider slot at 10000x multiplier)
    - Gate output BPM update rate-limited to 30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
    [main.cpp]
2026-04-28 Refactor menu handling for waveform and level/offset settings
    - Updated menu groups and item descriptions for clarity.
    - Consolidated waveform settings for all outputs into a single group.
    - Added level and offset settings for all outputs in a new group.
    - Adjusted envelope output selection to wrap across all outputs.
    - Fixed menu item indices and display handling for CV input targets.
    - Enhanced display rendering logic to reflect new menu structure.
    [main.cpp]
2026-04-28 fix: update quantizer output selection logic and reset initial index
    [main.cpp]
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2026-06-25 feat: Add loop functionality and output inversion to firmware
    - Introduced new loop features in the output management, allowing periodic rewind of pattern generators and nap/wake gating.
    - Added support for output inversion, enabling polarity flipping at the final output stage.
    - Updated the menu rendering to include new loop settings and output inversion options.
    - Enhanced the LoadSaveParams structure to accommodate new loop and inversion fields, ensuring backward compatibility with existing presets.
    - Adjusted the random number generation to support deterministic behavior for loops and cross operations.
    - Refactored output handling to integrate new loop and inversion functionalities seaml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
    [main.cpp]
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2026-06-26 fix: Update Readme.md to clarify open-source availability of hardware schematics and design files
2026-06-26 Add Arduino core shims for VCV Rack integration
    - Implemented Arduino.h to provide a subset of the Arduino API, including HostBridge for I/O management.
    - Created EEPROM.h for EEPROM emulation using a byte buffer, allowing data persistence via JSON.
    - Developed WString.h as a minimal string class backed by std::string for compatibility with Arduino string operations.
    - Added Wire.h to implement I2C communication, handling MCP4728 multi-write frames for DAC outputs.
    - Included glcdfont.h for a fixed-space bitmap font compatible with Adafruit_GFX.
    - Introduced timer.h for RP2040 hardware timer functionality, providing inert stubs for hosted engine use.
    [Arduino.h, ClockForge.cpp]
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2026-07-20 feat: Add keyboard shortcuts for encoder control in ClockForge module
    [ClockForge.cpp]
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2026-07-27 Add randomization functionality and update related documentation
    - Implement RandomizeParams() in lib/randomize.hpp for patch randomization.
    - Integrate randomization into the VCV plugin's engine with reset() and randomize() functions.
    - Update AGENTS.md and menuHandlers.hpp to reflect new randomization features.
    - Enhance isolation tests to validate randomization behavior and state persistence.
    [main.cpp]
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2026-07-27 Enhance Core 1 initialization and synchronization; add gate mechanism to prevent display corruption during setup
    [main.cpp]
2026-07-27 Add boot gate for Core 1 to prevent display corruption during initialization
    [main.cpp]
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2026-07-28 core: share boardIO and encoder across all four modules
    The board is the same board on every module, so the IO layer should be one
    file. It was four, and comparing them shows the split was never a design
    decision - it is development-timeline drift:
    * boardIO.hpp on CLK vs DQ/GEN differed ONLY in comment wording. Not one
    line of code.
    * encoder.hpp on CLK/SCP vs DQ/GEN differed by a single typo: a comment
    saying "call begin() from setupZ()". Fixed, and the files were then
    byte-identical, so they are gone.
    DQ's boardIO was the superset and becomes core/boardIO.hpp. Two real
    differences had to be handled rather than flattened:
    1. Display bus speed. SCP drives Wire at 1 MHz be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
    [boardIO.hpp, main.cpp]
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2026-07-28 dq: read CV through the shared core layer
    Second adopter of core/cvInput.hpp. Same channelADC[] -> channelMv[] move as
    GEN, but DQ had two consumers that worked in raw counts and one of them is the
    pitch path, so this is more than a swap.
    * HandleTransposeInput() divided by 4095 by hand; now uses CvNormFromMv().
    * Channel::Process() took ADC counts and did CountsToSemitones() internally.
    It now takes fractional semitones, converted by the caller with the new
    CvSemitonesFromMv(). This matters: counts cannot express a negative CV, so
    feeding a counts-based pitch input from bipolar hardware would have
    silently dropped every note below 0 V. Semitones carry the sign.
    Th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
    [main.cpp]
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2026-07-28 core: carry CV as normalised float instead of millivolts
    Replaces the millivolt transport with a normalised one, Mutable-style: a
    reading is a float where 1.0 is +5 V at the jack on every revision.
    unipolar (0..+5 V) CvRead() -> 0.0 .. 1.0
    bipolar (-5..+5 V) CvRead() -> -1.0 .. 1.0, 0 V == 0.0
    Millivolts were a units layer the hardware does not speak. The decisive
    argument for normalised over raw counts is what ends up in presets: a count is
    meaningless without also knowing MAXADC and the polarity convention, and both
    are expected to change (a +/-5 V revision is planned; MAXDAC moves if the DAC
    is upgraded). A normalised 0.5 survives both. It also keeps converter
    resolution o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
    [main.cpp]
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2026-07-28 unified: host NoteForge alongside ForgeView
    Two apps in one image. This is the first build where the namespacing does real
    work - ForgeView alone had nothing to collide with, and both modules define
    menuMode, switchState, displayRefresh, HandleCVInputs, TriggerReceived and
    RedrawDisplay at file scope.
    unified (shell + dq + scp) 19904 RAM / 144384 flash
    dq alone 18760 / 132448
    scp alone 19124 / 127384
    The second app costs ~780 bytes of RAM, which matches its TU's own data+bss
    almost exactly - i.e. nothing is being duplicated that should not be.
    Three things had to be fixed to get here, each the same shape: a header that
    was fine when includ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
    [dq_app.cpp, main.cpp]
2026-07-28 unified: host all four modules in one image
    GravityForge and ClockForge join NoteForge and ForgeView. The whole series now
    links into a single firmware:
    unified (4 apps) 28628 RAM (10.9%) 210864 flash (10.1%)
    clk 25356/163792 dq 18760/132448
    gen 19952/143528 scp 19124/127384 (standalone, all unchanged)
    Which lands almost exactly where the earlier per-TU measurement predicted:
    ~17.8 KB of shared Arduino/TinyUSB baseline plus each app's own state. Four
    apps cost 11 % of RAM, so the headroom concern about growing past six apps is
    comfortable.
    Two structural fixes this forced, both worth having regardless:
    * The per-app -I paths were a trap. GravityForge's TU resolved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
    [boardIO.hpp, clk_app.cpp, gen_app.cpp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]
2026-07-28 unified: LittleFS storage, shared calibration, and the boot menu
    Hold the encoder at power-on and the module asks which firmware it is. The
    choice persists, so it boots straight into that one from then on — the feature
    this whole exercise was for.
    unified 28648 RAM (10.9%) 239188 flash (13.1% of 1830912)
    Flash headroom drops because 256k is now reserved for the filesystem; the image
    itself grew 28 KB for LittleFS and the menu.
    core/fsStore.hpp replaces the emulated EEPROM as the platform's storage. The
    EEPROM emulation is ONE 4096-byte sector whose begin() silently clamps, and
    past the clamp every get/put is a no-op that still reports success — that is
    exactly how ClockForge's c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
    [fsStore.hpp, main.cpp]
2026-07-28 apps: persist presets to LittleFS in the unified build
    Closes the hazard the previous commit left open: all four apps wrote their
    presets from offset 0 of the emulated EEPROM sector, so switching apps and
    switching back lost them.
    storage.hpp gains a -DFORGE_USE_FS branch. The unified firmware sets it and
    gets per-app files; without it, the EEPROM path is unchanged. That matters
    because storage.hpp is shared with the VCV Rack port, whose shim provides a
    byte-buffer EEPROM and no filesystem — so the FS backend has to be opt-in
    rather than a replacement. The standalone firmwares stay on EEPROM too, where a
    single app owning the whole sector is fine.
    One file per slot (/clk3.pre), not one f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
    [clk_app.cpp, dq_app.cpp, fsStore.hpp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]
2026-07-28 unified: switch modules without a power cycle
    Hold the encoder for 2 s while an app is running and the module returns to the
    selector.
    Implemented as a shell gesture rather than a menu entry in each app: uniform
    across all four, costs no app a menu slot, and needs no surgery on four
    different MENU_ITEMS layouts. forge::RequestAppMenu() is exposed alongside it so
    an app can still offer its own entry later.
    The gesture cannot be mistaken for a click. Every app acts on the button's
    RELEASE edge, and the hold ends in a reboot — so the app only ever receives
    'pressed' and the release it would act on never arrives.
    Returning to the menu reboots rather than unwinding in place. A running app ow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
    [fsStore.hpp, main.cpp]
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2026-07-28 Protect load-bearing include order from include sorting
    Renaming the apps in the boot menu came with an editor auto-format that sorted
    the includes alphabetically, which broke the build with errors pointing at the
    wrong files entirely — 'RedrawDisplay was not declared' inside menuRender.hpp,
    whose real cause was menuDisplay.hpp having moved below it.
    The app headers carry a ../../../apps/<app>/lib/ prefix, so alphabetical order
    puts every one of them ahead of any bare-name core header. menuDisplay.hpp
    therefore lands last, after the menuRender.hpp that needs its MD_* primitives.
    The same sort also reorders the app headers among themselves, putting
    pinouts.hpp after files that need NUM_OUT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
    [clk_app.cpp, dq_app.cpp, gen_app.cpp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]
2026-07-28 core: share the calibration wizard, and fix CLK's divide-by-zero
    ~340 lines that existed three times. DQ and GEN were byte-identical; CLK
    differed by 24 code lines, only two of which mattered.
    The blocker I had been citing turned out not to exist. calibration.hpp
    #included presetManager.hpp — the app-specific preset schema — which is what
    kept it out of core/. It never used it: SaveCalibration() is declared in the
    file itself. The include was vestigial.
    The real per-app difference was jack naming: ClockForge prompts for OUT1..OUT4,
    the others for CV 1 / CV 2 / GATE1 / GATE2. That is module semantics, so
    CAL_OUT_NAMES moves to each app's lib/pinouts.hpp alongside NUM_CHANNELS and
    OUT_CV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
    [calibration.hpp, clk_app.cpp, dq_app.cpp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]
2026-07-28 core: one storage layer, ten slots on every module
    storage.hpp existed three times, differing by 2 code lines between DQ and GEN
    and 6 between CLK and DQ. It is now core/appStorage.hpp plus a four-line shim
    per app that defines FORGE_APP_SLUG and includes its own preset schema.
    NUM_SLOTS goes 7 -> 10 everywhere. The 7 was never a design choice: it was the
    largest number of ClockForge presets that fit the 4096-byte emulated EEPROM
    sector, and dropping to it was how that module's silently-broken calibration
    got fixed. On the filesystem each slot is its own file, so the cap is gone and
    all three modules get the same ten.
    Standalone hardware builds move onto LittleFS too, so there is now ONE s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
    [appStorage.hpp]
2026-07-28 Replace hardcoded 4095 with MAXDAC/MAXADC
    I claimed a few commits ago that moving to a 16-bit DAC would be a one-line
    change to MAXDAC. It would not have been: the converter's full-scale value was
    still written literally in nine places, including twice inside core/ itself
    where MAXADC was already in scope.
    Fixed, with the domain chosen per site rather than substituted blindly — the
    two are the same number today and will not stay that way, since the RP2040's
    ADC is fixed at 12 bit while the DAC could be swapped:
    ADC domain -> MAXADC
    core/calibration.hpp raw->mV conversion, and the nominal cvScale
    apps/scp scope.hpp volts-per-division readout
    DAC domain -> MAXDAC
    app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
    [calibration.hpp]
2026-07-29 Replace per-app pinouts.hpp with jacks.hpp
    Deleting the per-app pinouts.hpp was right — it was mostly a wrapper around
    core/boardPinouts.hpp. Moving its contents into src/main.cpp could not work,
    though, and the build showed why: NUM_CHANNELS, OUT_CV/OUT_GATE and
    CAL_OUT_NAMES are used by seven app HEADERS (presetManager, menuHandlers,
    menuRender, randomize), and each of those is compiled by three translation
    units per module — src/main.cpp, the unified firmware's app TU, and the VCV
    Rack engine. Only one of the three is main.cpp, so standalone built and the
    other two could not.
    They now live in apps/<app>/lib/jacks.hpp, named for what they actually are.
    That is not the old wrapper unde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
    [calibration.hpp, clk_app.cpp, dq_app.cpp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]
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2026-07-29 dq: one HandleOutputs instead of three
    First of the three modules. NoteForge's per-iteration engine step moves from
    src/main.cpp into lib/engine.hpp, and the firmware, the VCV Rack engine and the
    unified app TU all include it rather than each carrying a copy.
    Three TUs compile every app header and only one of them is main.cpp, so
    anything defined there gets duplicated into the other two by hand. That is not
    theoretical: GravityForge's Rack port had lost its LOOP>NAP muting call, fixed
    in the preceding commit and found by diffing these very copies.
    engine.hpp externs the two globals it needs (channels[], displayRefresh) and is
    included after they are defined, which is the convention menuHan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
    [dq_app.cpp, main.cpp]
2026-07-29 core: share encoder rotation acceleration
    UpdateSpeedFactor was byte-identical in all three firmwares and again in all
    three unified app TUs — six copies of the same twenty lines. Now one:
    core/encoderAccel.hpp.
    Only the acceleration moved. What a detent *does* stays per module, because it
    genuinely differs: GravityForge arms a live physics preview, ClockForge seeds
    pendingCVInputTarget when entering CV-target edit mode, NoteForge does neither.
    The unified image drops 32 bytes of RAM: the three private copies of
    speedFactor/lastEncoderTime/lastEncoderDir become one shared set, which is also
    more correct — the encoder is one piece of hardware and only one app runs.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
    [clk_app.cpp, dq_app.cpp, encoderAccel.hpp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]
2026-07-29 core: share ShowTemporaryMessage and metrics.hpp
    ShowTemporaryMessage was byte-identical in NoteForge and GravityForge.
    ClockForge's differed in exactly two ways, and adopting the shared version
    fixes both:
    * it did not clamp x, so a message wider than the screen started drawing off
    the left edge;
    * its wait loop called HandleOutputs() but not HandleCVInputs(), so CV
    modulation froze for the whole second the overlay was up. The clock kept
    running because it is timer-driven, which is why this would read as CV
    briefly sticking rather than as a hang.
    The header is included INSIDE each app's namespace, not at global scope. It
    reads names the app owns (_displayLocked, _displ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
    [clk_app.cpp, dq_app.cpp, gen_app.cpp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]
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2026-07-29 One hardware build: unified. Apps become native-test projects
    Prep for retiring the standalone firmwares. Each app's logic currently exists
    three times — src/main.cpp, the unified app TU, and the VCV engine — and that
    is the root of the remaining duplication, not any individual function. Dropping
    one host removes a third of it.
    Nothing is deleted yet. src/main.cpp stays on disk, out of the build, until the
    unified image has been verified on hardware for all four modules; right now
    only the boot menu has been. Deleting the known-good reference before the
    replacement is proven is the one step worth not rushing.
    Two things had to be rescued rather than fall out with the hardware env:
    *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
    [clk_app.cpp, dq_app.cpp, gen_app.cpp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]
2026-07-29 Delete the standalone firmwares
    Hardware-verified: every module loads and saves its parameters from the
    unified image, so the per-app builds have nothing left to be a fallback for.
    1367 lines of src/main.cpp across the four modules, all of it a third copy of
    logic that already exists in unified/src/apps/<app>_app.cpp and in each
    vcv-plugin engine. That third copy is what let GravityForge's Rack port lose
    its LOOP>NAP muting, and what made an include-order mistake fail to link in
    NoteForge while ClockForge and GravityForge silently got away with it.
    Each module's firmware logic now lives in exactly two places — the unified app
    TU and the Rack engine — and collapsing those two onto IApp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
    [main.cpp]
2026-07-29 Move each app TU beside its own lib
    unified/src/apps/<app>_app.cpp moves to apps/<app>/src/<app>_app.cpp, so a
    module's code all lives under apps/<app>/ — its shell-facing TU, its lib/, its
    Rack plugin and its tests. unified/ is now just the shell.
    This also retires the deep relative includes. Sitting next to its own lib/,
    each TU addresses its headers as ../lib/foo.hpp instead of
    ../../../apps/<app>/lib/foo.hpp — around fifteen per module.
    Those paths were not stylistic: they exist because the per-app -I entries had
    to go after GravityForge's TU resolved "quantizer.hpp" to NoteForge's copy
    purely because dq came first in the include path. Explicit paths were the fix.
    Being adjacent gi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
    [clk_app.cpp, dq_app.cpp, gen_app.cpp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]
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2026-07-29 unified: fix encoder needing two detents to reverse
    The detent test was asymmetric. With four counts per detent, from an aligned
    oldPosition of 100:
    decreasing (newPos + 3) / 4 < 25 fires at 96 one detent
    increasing (newPos - 3) / 4 > 25 fires at 107 two detents
    Integer division truncates and oldPosition was then snapped to newPosition,
    throwing away the remainder, so the deadband never re-centred. Truncation
    toward zero also swapped which direction was penalised once the count went
    negative.
    Now a whole detent is subtracted from the accumulated delta and the remainder
    kept, so both directions cost exactly one detent and a reversal costs one.
    Looping rather than testi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
    [main.cpp]
2026-07-29 unified: stop boot-menu scrolling leaking into the app
    Selecting a module from the boot menu left its cursor offset by however far you
    had scrolled to reach that module - two back for ClockForge, one forward for
    the others, matching where each sits in the list. Power-cycling straight into a
    module was fine, which is what pointed at the menu.
    RunBootMenu tracks its own encoder position, so the shell's stayed at zero
    while the counter moved. PollEncoder's first call then saw a delta covering the
    entire menu rotation and, since the previous commit made it consume every whole
    detent in a loop rather than one per call, delivered all of them to the app at
    once.
    Re-baselining after Begin() covers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
    [main.cpp]
2026-07-29 Fix clk build; make the Windows detection shell-independent
    Three things, all surfaced by running make everything.
    1. ClockForge stopped compiling: core/appDisplay.hpp calls HandleOutputs from
    ShowTemporaryMessage, and the forward declaration that bridged the gap had
    gone missing. Rather than restore it, engine.hpp now precedes appDisplay.hpp
    in all three modules. engine.hpp externs the globals it needs, so it does not
    care that they are defined further down, and it defines HandleOutputs — which
    satisfies appDisplay directly. One less fragile declaration to lose.
    2. The Windows block was keyed on the OS variable, which Git Bash sets as a
    shell variable without exporting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
    [clk_app.cpp, dq_app.cpp, gen_app.cpp]
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2026-07-29 feat: Enhance CI workflow for versioning and release management; update app versions and add I2C bus recovery for display error on boot selection
    [boardIO.hpp, main.cpp]
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2026-08-05 feat: Add ChaosForge — dual chaotic-attractor modulation source
    A fifth module (apps/att), built on the shared shell, core and VCV layer.
    Two generators each integrate one of twelve published chaotic systems
    (Lorenz, Rössler, Thomas, Chua, Halvorsen, Chen, Burke-Shaw, Aizawa,
    Dadras, Sprott B/C, Finance) and send two of their three state variables
    to a pair of jacks: OUT 1/2 from A, OUT 3/4 from B. Two outputs from one
    orbit are related but never equal, which is the thing a pair of LFOs
    cannot do.
    - SPEED is a multiplier on the rate each system was catalogued at, so
    1.00x means comparable motion whichever system is selected. A fixed
    1 ms module step drives an RK4 integrator whose ow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
    [ChaosForge.cpp, att_app.cpp, main.cpp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]
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2026-08-07 feat: WeaveForge — dual shift-register sequencer
    Two 16-bit Turing Machines clocked in parallel, with a WEAVE control
    deciding how much of each register's incoming bit is taken from the
    other: from two independent sequencers, through motifs leaking across,
    to a single ring as long as both of them together. The four outputs are
    assignable — source, type, window depth and rotation each — so the same
    two registers can be two voices, a voice plus two modulations, or a
    four-track drum machine.
    Runs on both hosts: the unified firmware (env:xiao_wea builds a
    single-module image) and VCV Rack, standalone and in the consolidated
    plugin.
    Promotes the tempo half of GravityForge's clock into cor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
    [gen_app.cpp, main.cpp, wea_app.cpp]
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
